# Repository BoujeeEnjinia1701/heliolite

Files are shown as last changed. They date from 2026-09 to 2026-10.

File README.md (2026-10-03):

# HelioLite

     

**Area:** CleanTech · **TRL:** 3 of 9 (proof of concept on paper) · **Value-engineering target:** about $455 USD · **Difficulty:** 3 of 5

Two-axis mini heliostat on a mast that redirects sunlight to a fixed target, using a sun-position algorithm with no sun sensors.

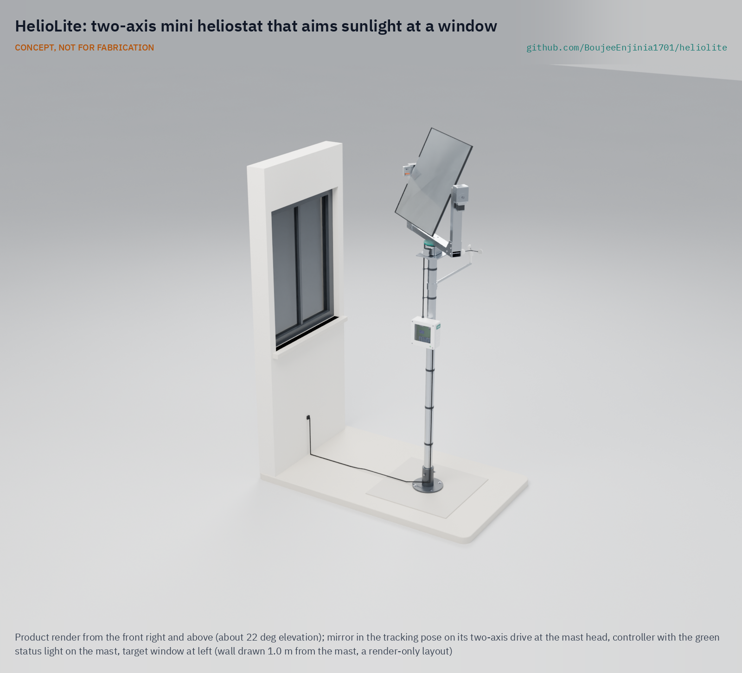
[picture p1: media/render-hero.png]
HelioLite: two-axis mini heliostat that aims sunlight at a window, product render


[Exploded render](media/render-exploded.png) · [Detail render](media/render-detail.png) · [Interactive 3D model](media/viewer.html) · [Concept blueprint (PDF)](media/concept-blueprint.pdf) · [General arrangement HLT-DWG-001 (PDF)](cad/drawings/HLT-DWG-001.pdf) · [Sizing calculations](docs/04-calcs/01-sizing.md) · [Prototype build plan](docs/05-build-plan.md) · [Design decisions register](docs/06-design-decisions.md) · [Review note](docs/REVIEW.md)

## Concept rationale

A flat mirror that follows the sun is the simplest way to move winter sunlight to where it is needed: it adds no light source, burns no fuel and uses a few watts to aim itself. Towns in deep valleys have proved the idea at civic scale ([NPR, 2013](https://www.npr.org/2013/11/03/242789411/as-mirrors-beam-light-to-town-norwegians-share-patch-of-sun)), and open microcontroller projects have shown that a clock and a sun-position algorithm can aim a mirror without a sun sensor ([jremington/Arduino_heliostat](https://github.com/jremington/Arduino_heliostat)). HelioLite joins the two at the scale of one window, with a mast, a light aluminum yoke and two worm drives instead of a structure on a mountainside.

Keeping the design open and garage-buildable matters because the useful sites are scattered and different: each yard, greenhouse or school has its own latitude, distances and shading, and the hourly model shows that siting changes the result more than any part choice. Common parts (a glazier's mirror, steel fence pipe, NEMA17 motors, an ESP32) let owners build, calibrate and repair a unit for their own site, and published calculations let them check that it will work there before they buy anything.

## Burning platform

People in the United States spend, on average, about 90 % of their time indoors ([US EPA](https://www.epa.gov/report-environment/indoor-air-quality)), so the daylight a room receives is most of the daylight its occupants get. Lighting in buildings and outdoor applications used about 8 % of global electricity in 2024, about 2,200 TWh ([IEA](https://www.iea.org/commentaries/the-next-wave-of-led-lighting-smarter-circular-and-more-efficient)), and rooms that never see the sun in winter are the ones that run lamps through the day.

Cold matters as well as dark. The WHO proposes 18 °C as a safe indoor temperature during cold seasons in temperate and colder climates ([WHO Housing and Health Guidelines, 2018](https://www.ncbi.nlm.nih.gov/books/NBK535281/table/fm-ch1.tab1/)), and north-facing rooms receive no passive solar gain toward it. HelioLite's contribution is modest, about 150 W while the sun shines, but it arrives at the time of day and in the rooms where winter sun is otherwise missing.

## Where it could be used

### By industry

| Industry | Use |
| --- | --- |
| Housing and home improvement | Daylight and a little heat in north-facing living rooms, kitchens and home offices |
| Horticulture and community gardens | Extra light on the shaded side of greenhouses, hoop houses and lean-tos in winter and spring |
| Education | A working teaching project in astronomy, optics and control for schools and makerspaces |
| Hospitality and small commercial | Sunlight into a north-facing courtyard, café seating or entrance on clear winter days |
| Urban planning and building retrofit | A small-scale option where new neighboring buildings take a dwelling's winter sun |

### By country or region

| Country or region | Why it matters there |
| --- | --- |
| United States | Space heating and air conditioning made up 52 % of household energy use in 2020, and homes in the colder Northeast and Midwest use more energy on average than those in the South and West, largely for heating ([US EIA](https://www.eia.gov/energyexplained/use-of-energy/homes.php)); houses, greenhouses and community gardens in the northern states have long, low-sun winters |
| European Union | In 2024, 9.2 % of the EU population could not keep their home adequately warm, rising to 19.0 % in Bulgaria and Greece ([Eurostat, 2026](https://ec.europa.eu/eurostat/web/products-eurostat-news/w/ddn-20260202-2)); in sunny southern member states, clear winter days make free solar gain worth capturing |
| China | Planning rules require dwellings to receive two or three hours of sunlight on Dahan Day (20 January) or one hour on the winter solstice, by climate zone and city size ([Hong, Wang and Zhang, *Buildings*, 2024](https://www.mdpi.com/2075-5309/14/4/1090)); units that fall short could borrow sun from a courtyard |
| Mongolia | More than half of Ulaanbaatar's residents, over 790,000 people, live in ger districts heated mainly by coal and wood, and January temperatures fall below -20 °C ([World Bank, 2018](https://www.worldbank.org/en/news/feature/2018/06/26/better-air-quality-in-ulaanbaatar-begins-in-ger-areas)); any daytime solar gain that does not come from a stove is worth having |
| Chile | Firewood produces as much as 94 % of fine particulate (PM2.5) emissions in some Chilean cities, and winter smog is trapped in valley cities such as Santiago ([UNEP](https://www.unep.org/news-and-stories/story/chile-takes-action-air-pollution)); in the Southern Hemisphere the rooms that miss winter sun face south |

## What sparked the idea

The starting point was Rjukan, a Norwegian town of about 3,500 people that the surrounding mountains keep out of direct sunlight from late September to mid-March. In 2013 a set of mirrors on the mountainside above the town was used for the first time: controlled by a computer, the mirrors shift with the sun through the day, pivot closed in windy weather and reflect a beam onto the central square, lighting an elliptical patch of about 600 m² ([NPR, 2013](https://www.npr.org/2013/11/03/242789411/as-mirrors-beam-light-to-town-norwegians-share-patch-of-sun)). HelioLite asks whether the same principle, a tracking mirror aimed by software, can serve a single dark room or greenhouse for a few hundred dollars in parts.

## Problem

North-facing rooms and greenhouses lack daylight and solar heat. On a clear winter day a 0.36 m² mirror can send about 160 W of sunlight (about 15,000 lm) through a window, enough to add roughly 500 lx to a small room, and 0.5 to 1.0 kWh a day at a well-sited house at 45° N, while its heat contribution is a modest bonus (calculations in [HLT-CAL-001](docs/04-calcs/01-sizing.md)).

## Concept

Two-axis mini heliostat on a mast that redirects sunlight to a fixed target, using a sun-position algorithm with no sun sensors.

An ESP32 computes the sun's position from a real-time clock and the site location every 30 s, and two worm-driven steppers turn the mirror so its normal bisects the directions to the sun and to the target. A phone-based calibration at four points over about 4 h fits the mount alignment, and spiral preload springs keep the worm drives' backlash out of the beam. The mirror stows face-down at night, before storms (from a cup anemometer and a wind forecast) and, on a supercapacitor reserve, after a power loss; a spring latch then carries the storm load instead of the gearbox.

At TRL 3 the paper checks meet 11 of 15 requirements with the design made constructable ([HLT-DDR-003](docs/decisions/0003-design-for-construction.md)). Value-engineering target: USD 455. Estimated cost of the constructable design: USD 499 (USD 44 over the target). Daily energy (R3) and pointing (R4) are at risk; see the [review note](docs/REVIEW.md).

Full design precis: [docs/02-concept.md](docs/02-concept.md)

## Key components

- Glass mirror 60 x 60 cm with a black EPDM edge channel (decided 2026-10-02)
- NEMA17 steppers on NMRV030-class 50:1 worm gearboxes (2)
- ESP32 with RTC
- Mast: 60.3 mm galvanized steel pipe (decided 2026-09-25)
- Aluminum tube yoke with printed bearing plugs and bronze bushes (made constructable 2026-10-01)
- Cup anemometer and supercapacitor stow reserve
- Stow stop and spring latch on the yoke (aluminum bracket, decided 2026-10-02), and spiral preload springs on both drives (decided 2026-09-25)

The priced bill of materials (USD 499 against the USD 455 value-engineering target, USD 44 over) is in [bom/bom.csv](bom/bom.csv). The parametric model is `cad/src/model.py`, with STEP and STL exports in `cad/step/` and `cad/stl/`.

## Building the prototype

The [prototype build plan](docs/05-build-plan.md) (HLT-BLD-001) shows how to make each of the 15 made components and how to put HelioLite together in 18 steps, with a making sketch for every made part, close-ups of the joints and a picture for every step, all drawn from the model. Building the plan made the design constructable: the printed yoke became an aluminum tube frame, and the trunnions, latch, mast top and fixings were detailed so every part can be made and fastened ([HLT-DDR-003](docs/decisions/0003-design-for-construction.md)). It is a plan, not yet built; building and testing to it is TRL 4 work. Decisions still open are in the [design decisions register](docs/06-design-decisions.md).

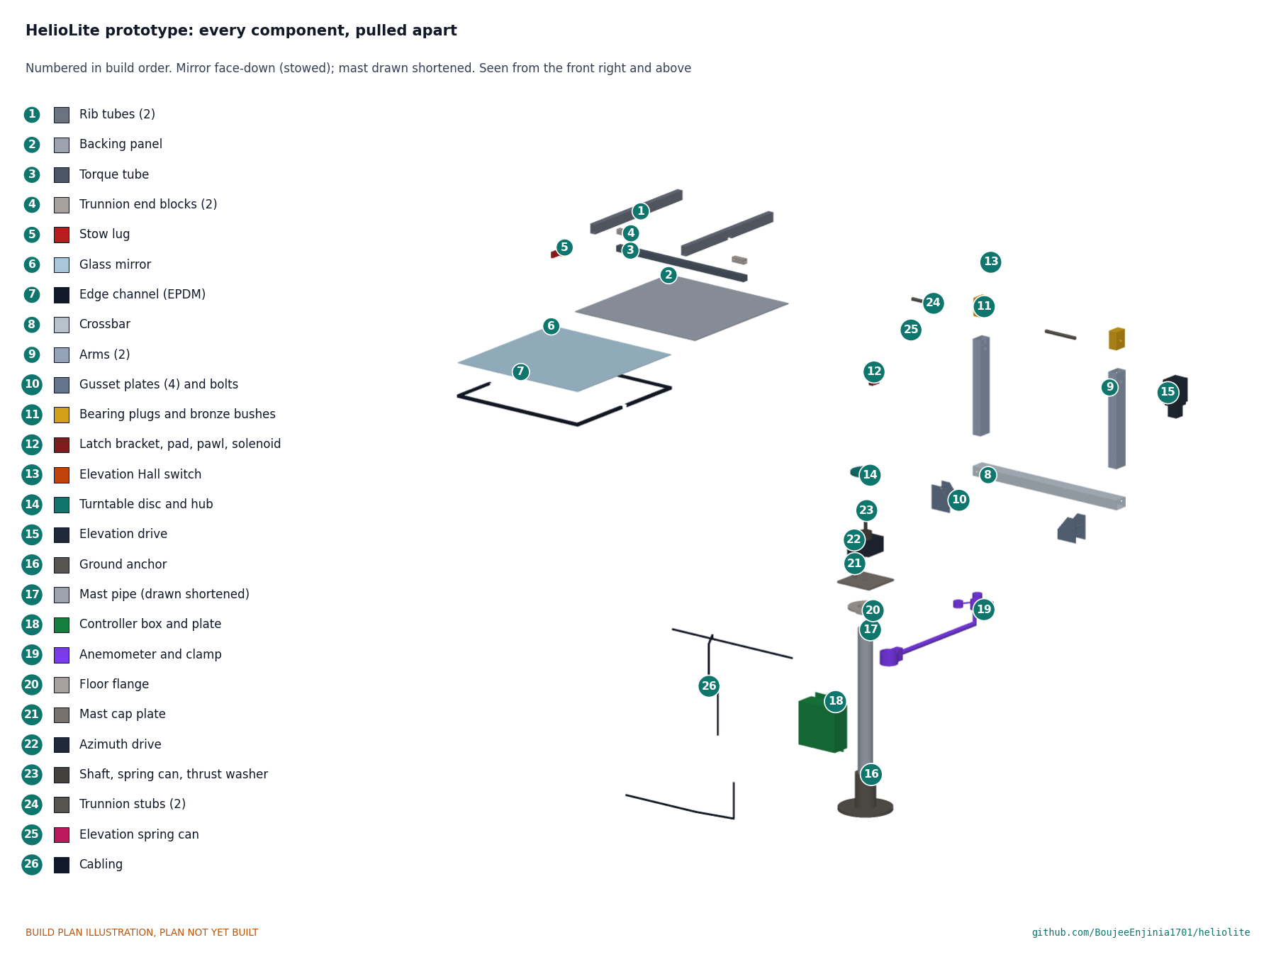
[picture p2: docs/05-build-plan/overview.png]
HelioLite prototype: every component pulled apart, numbered in build order


## Safety

> **Safety:** The reflected beam is nearly as bright as the sun and can cause eye injury; several mirrors aimed at one spot can start a fire. Never aim at people, vehicles or aircraft. The gimbal moves with high torque, the mirror is glass 2.2 m above the ground, and the mast must be anchored and stowed before storms. Only 12 V DC runs outdoors. See the safety section of the [precis](docs/02-concept.md).

## Repository layout

| Folder | Contents |
| --- | --- |
| `docs/` | Problem, concept, requirements, calculations and design decisions |
| `cad/src/` | build123d Python source, the source of truth for all geometry |
| `cad/step/`, `cad/stl/` | Exported models for FreeCAD, other CAD tools and printing |
| `cad/drawings/` | 2D sketches and dimensioned drawings |
| `bom/` | Bill of materials |
| `electronics/` | KiCad schematics and PCB layouts |
| `firmware/` | Microcontroller code |
| `media/` | Renders, perspectives and photos |
| `build-log/` | Dated prototyping notes |

## Documentation

Controlled documents follow the portfolio [documentation standard](.kit/STANDARDS.md). Each carries a document ID (HLT-PRC-001 for the precis), a version and a revision history. Branded PDFs are built with `python .kit/render.py` and attached to GitHub Releases when a document is tagged, for example `HLT-PRC-001/v1.0`.

## Credits

Designed by Amish Chadha, with contributions from Ashok Kumar Chadha. See [CONTRIBUTORS.md](CONTRIBUTORS.md) for roles. To cite this design, use [CITATION.cff](CITATION.cff) (GitHub shows it as "Cite this repository").

AI assistance (Claude) was used to accelerate concept renders, prototype documentation and first-pass sizing calculations. Design direction and all decisions are Amish Chadha's, recorded in this repository's decision records (`docs/decisions/`).

## Licenses

- **Hardware** (CAD, drawings, BOM, electronics): [CERN-OHL-S v2](LICENSE)
- **Software** (firmware, scripts, notebooks): [MIT](LICENSE-SOFTWARE)

A project of the [Design Molecule](https://designmolecule.com) lab.

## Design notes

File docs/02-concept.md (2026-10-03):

---
doc_id: HLT-PRC-001
title: HelioLite design precis
project: HelioLite
doc_type: Design precis
version: "0.8"
status: Draft
date: '2026-10-02'
author: Amish Chadha
license: CERN-OHL-S-2.0
revisions:
- version: "0.1"
  date: '2026-09-24'
  author: Amish Chadha
  change: Initial scaffold
- version: "0.2"
  date: '2026-09-25'
  author: Amish Chadha
  change: Populate to TRL 2 (architecture, first-order numbers, pointing and wind budgets, safety, media)
- version: "0.3"
  date: '2026-09-25'
  author: Amish Chadha
  change: TRL 3 update; design choices decided by Amish (HLT-DDR-001); drives, anemometer and stow reserve added; numbers replaced by HLT-CAL-001; model, drawing HLT-DWG-001 and media refreshed
- version: "0.4"
  date: '2026-09-25'
  author: Amish Chadha
  change: Recommendations accepted by Amish (DDR-002)
- version: "0.5"
  date: '2026-09-26'
  author: Amish Chadha
  change: "Budget top-up approved by Amish: parts within the $455 budget"
- version: "0.6"
  date: '2026-10-01'
  author: Amish Chadha
  change: Design made constructable (HLT-DDR-003); build plan HLT-BLD-001 and register HLT-DEC-001 added; budget treated as a value-engineering target
- version: "0.7"
  date: '2026-10-02'
  author: Amish Chadha
  change: "Decisions of 2026-10-02: glare study and local rules before uncovering, EPDM edge guard, two-lift head fitting from a platform, first site and siting survey, daylight first in public copy"
- version: "0.8"
  date: '2026-10-02'
  author: Amish Chadha
  change: "Decisions of 2026-10-02 carried into the design: aluminum latch bracket, EPDM edge channel in the parts table and figures, two-lift fitting; values from HLT-CAL-001 v0.5"
---

# HelioLite design precis

HelioLite is a 600 x 600 mm glass mirror on a two-axis, worm-driven gimbal at the top of a 60.3 mm steel mast. An ESP32 computes the sun's position from a real-time clock and the site location, and turns the mirror so its normal bisects the directions to the sun and to a fixed target window. It uses no sun sensor; a cup anemometer and a wind forecast tell it when to stow, a supercapacitor reserve lets it stow face-down after a power loss, and a stow latch then carries the storm load instead of the gearbox. The TRL 3 calculations (HLT-CAL-001) give about 211 W at the glazing and 159 W (about 15,000 lm, a mean of about 500 lx in a 12 m² room) at the design point, 0.50 kWh through the glazing on the winter solstice and 1.0 kWh on 1 February at a reference site, and a beam pointing error of 0.30° typical against 0.5°. The design is now constructable (HLT-DDR-003): every part can be made by its stated process and is fixed to the parts next to it, and the [build plan](05-build-plan.md) (HLT-BLD-001) shows how. 11 of 15 requirements are met on paper; daily energy (R3) and pointing (R4) are at risk; and on cost, value-engineering target: USD 455, estimated cost of the constructable design: USD 492 (USD 37 over the target).

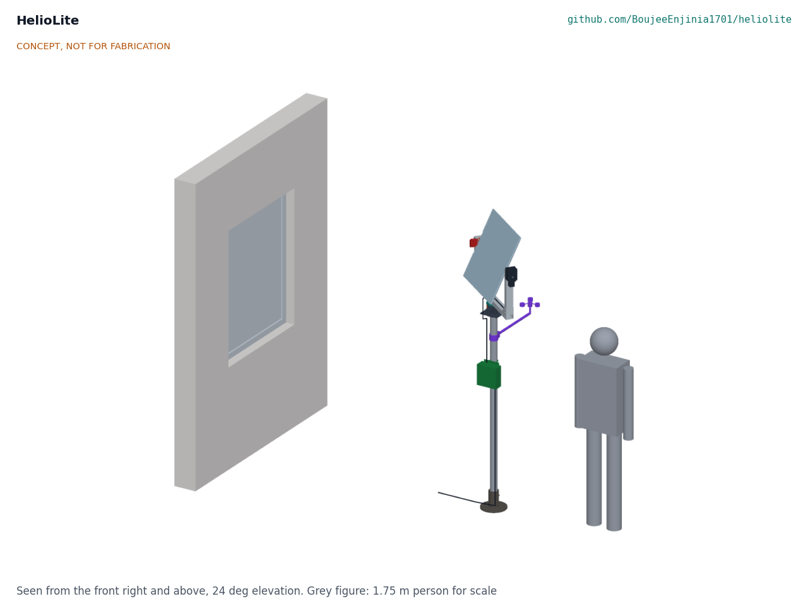
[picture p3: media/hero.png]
Hero render


*Figure 1. HelioLite on its mast with a 1.75 m person for scale. The house wall and target window are context and are drawn closer than a real site so the heliostat stays legible.*

## How it works

1. **Know the time and place.** A DS3231 real-time clock (±2 ppm from 0 to 40 °C, about ±1 min per year ([Adafruit DS3231 guide](https://learn.adafruit.com/adafruit-ds3231-precision-rtc-breakout/overview))) keeps UTC. When Wi-Fi is available the ESP32 corrects it by network time once a week. Latitude, longitude and the target direction are entered once at setup.
2. **Compute the sun.** Every 30 s the ESP32 runs Grena's algorithm 5 (maximum error 0.0027° for 2010 to 2110 ([Grena 2012](https://www.sciencedirect.com/science/article/abs/pii/S0038092X12000400))), with NREL SPA (±0.0003° ([Reda and Andreas](https://www.nrel.gov/docs/fy08osti/34302.pdf))) as the alternative, to get the unit vector **s** toward the sun. There is no sun sensor.
3. **Aim the mirror.** The required mirror normal is **n** = (**s** + **t**) / |**s** + **t**|, where **t** is the unit vector from the mirror to the target. A mount model with five terms (azimuth and elevation zero offsets, two base tilts and the mirror's cant on its torque tube) converts **n** into azimuth and elevation steps.
4. **Move.** Two NEMA17 steppers on NMRV030-class 50:1 worm gearboxes turn the yoke in azimuth and the mirror in elevation. A spiral preload spring of about 3 N·m on each axis keeps the worm teeth on one flank, so the gearbox's 1° backlash does not reach the beam; the elevation spring biases the mirror toward stow. The worms are self-locking, so the drivers switch off between moves. Hall switches home each axis at start-up.
5. **Calibrate.** At setup the user opens a web page served by the ESP32, jogs the sun spot onto the target center at four times spread over about 4 h, and the firmware fits the mount model to those points. No survey instrument is needed.
6. **Stow.** At night, on a fault, when the anemometer sees a 15 m/s gust or when the forecast predicts one, the mirror turns face-down. This sends no reflection anywhere, protects the glass from hail and dust, and presents the lowest wind load. On a power loss a supercapacitor bank in the controller box powers the stow. At the end of the stow a steel lug on the torque tube pushes a sliding latch pawl aside and seats on a polyurethane stop pad on the -X arm; the pawl springs back over it without power, the firmware backs the worm off to mid-backlash, and from then on the stop and the pawl carry the wind moment in both directions. A 12 V pull solenoid draws the pawl back when the unit leaves stow.

The sun moves about 15° per hour, so between 30 s updates it moves about 0.125° and the mirror normal needs about half of that. The mirror's center of mass sits 12.5 mm in front of the elevation axis (HLT-CAL-001, [H4]), so the drives overcome a small gravity moment (up to 0.78 N·m) as well as friction and wind.

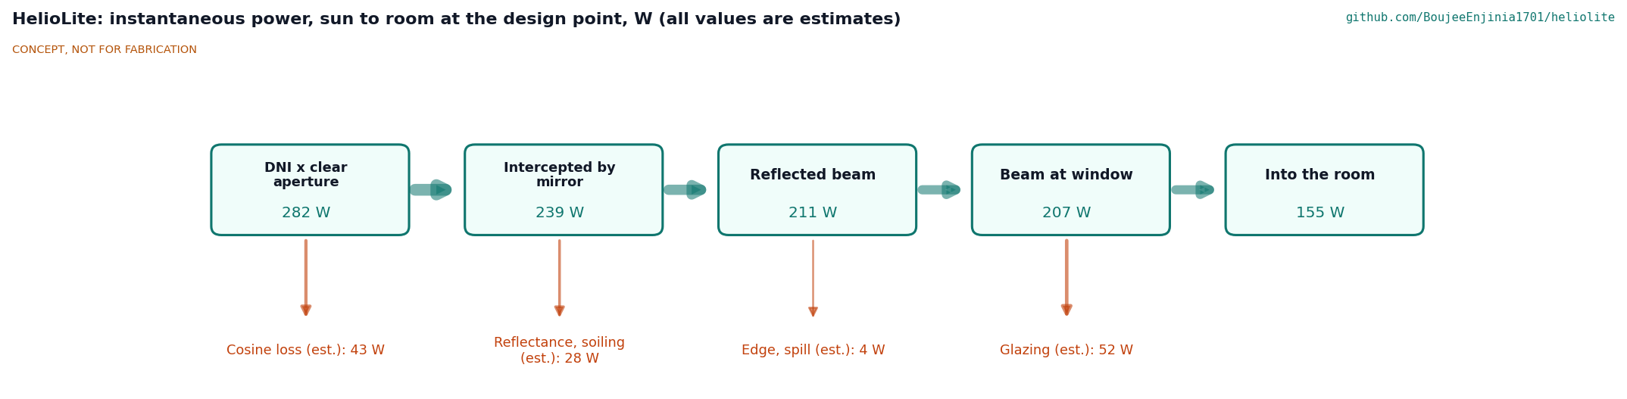
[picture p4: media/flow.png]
Energy flow


*Figure 2. Instantaneous power from the sun to the room at the design point (DNI 800 W/m², 10 m to the target, 32° incidence), in W. Values from HLT-CAL-001 [A2]; all are estimates.*

## Main components

Numbers match the exploded view (Figure 3), drawing HLT-DWG-001 and `bom/bom.csv`.

Table 1. Main components.

| # | Component | Choice | Notes |
| --- | --- | --- | --- |
| 1 | Mirror | 600 x 600 x 3 mm silvered glass, seamed edges, safety backing film; black EPDM edge channel round the glass and panel edges | Decided (HLT-DDR-001, D10; edge channel 2026-10-02); cut by a local glazier |
| 2 | Backing panel and torque tube | 4 mm aluminum composite panel bonded to the mirror, two 25 x 40 mm rib tubes with tunnels for the torque tube, 25 mm square aluminum torque tube with end blocks and pinned 14 mm keyed trunnion stubs | Carries the elevation axis 12.4 mm behind the mirror's center of mass |
| 3 | Gimbal yoke | Aluminum rectangular tube 60 x 40 x 2 mm: a crossbar and two arms at ±340 mm joined by gusset plates, printed ASA bearing plugs and flanged bronze bushes (HLT-DDR-003; the one-piece printed yoke could not be printed) | Arms stand 20 mm outside the mirror's sweep so it can turn face-down; arm flex 0.006° at 8 m/s (HLT-CAL-001, section C) |
| 4 | Elevation drive | NEMA17 stepper on an NMRV030-class 50:1 worm gearbox (17 N·m rated, 14 mm hollow bore) via an adapter plate | Bolted flat to the +X arm, on the keyed trunnion stub |
| 5 | Azimuth drive and mast cap | Same drive, bore vertical, on a 160 mm steel cap plate screwed to a 2 in threaded floor flange on the mast | Carries the turntable |
| 6 | Azimuth turntable | 120 mm aluminum disc on a keyed hub, a double output shaft and a bronze thrust washer | Carries the yoke and mirror |
| 7 | Mast | 60.3 mm (2 in) galvanized steel pipe, 1.70 m | Decided (D1). Mirror center 2.2 m above ground |
| 8 | Ground anchor | Ground screw for 60 mm posts or a concrete footing, with a socket and flange | Must resist 0.79 kN·m; 1.0 kN·m specified |
| 9 | Controller box | ESP32, DS3231 RTC, two TMC2209 drivers, 12 V to 5 V buck, supercapacitor stow reserve (BOM line 15), IP65 box | On the mast at 1.1 m, reachable for service |
| 10 | Homing switches | Two Hall switches with magnets | Axis reference only; not sun sensors |
| 11 | Cabling | Motor leads, 2-core outdoor 12 V cable, cable glands | 12 V feed from indoors (D9) |
| 14 | Anemometer | Pulse-output cup anemometer on a 550 mm side arm at 1.5 m | Decided (D2); a weather sensor, not a sun sensor |
| 16 | Drive preload springs | Flat spiral springs of about 3 N·m in printed cans: elevation on the -X trunnion outboard of the arm, azimuth inside the mast top | Decided (HLT-DDR-002 N2); holds each worm on one flank |
| 17 | Stow stop and latch | 8 mm steel lug on a collar on the torque tube; 6 mm aluminum angle bracket on the -X arm with an aluminum stop block and 3 mm polyurethane (90A) stop pad, a sliding steel pawl and a 12 V pull solenoid with a return spring | Decided (HLT-DDR-002 N1); designed for 48.6 N·m, twice the assumed stowed moment |

A listed indoor 12 V, 3 A power adapter (line 12), the fasteners (line 13) and the stow reserve inside the controller box (line 15) are in the BOM without callouts.

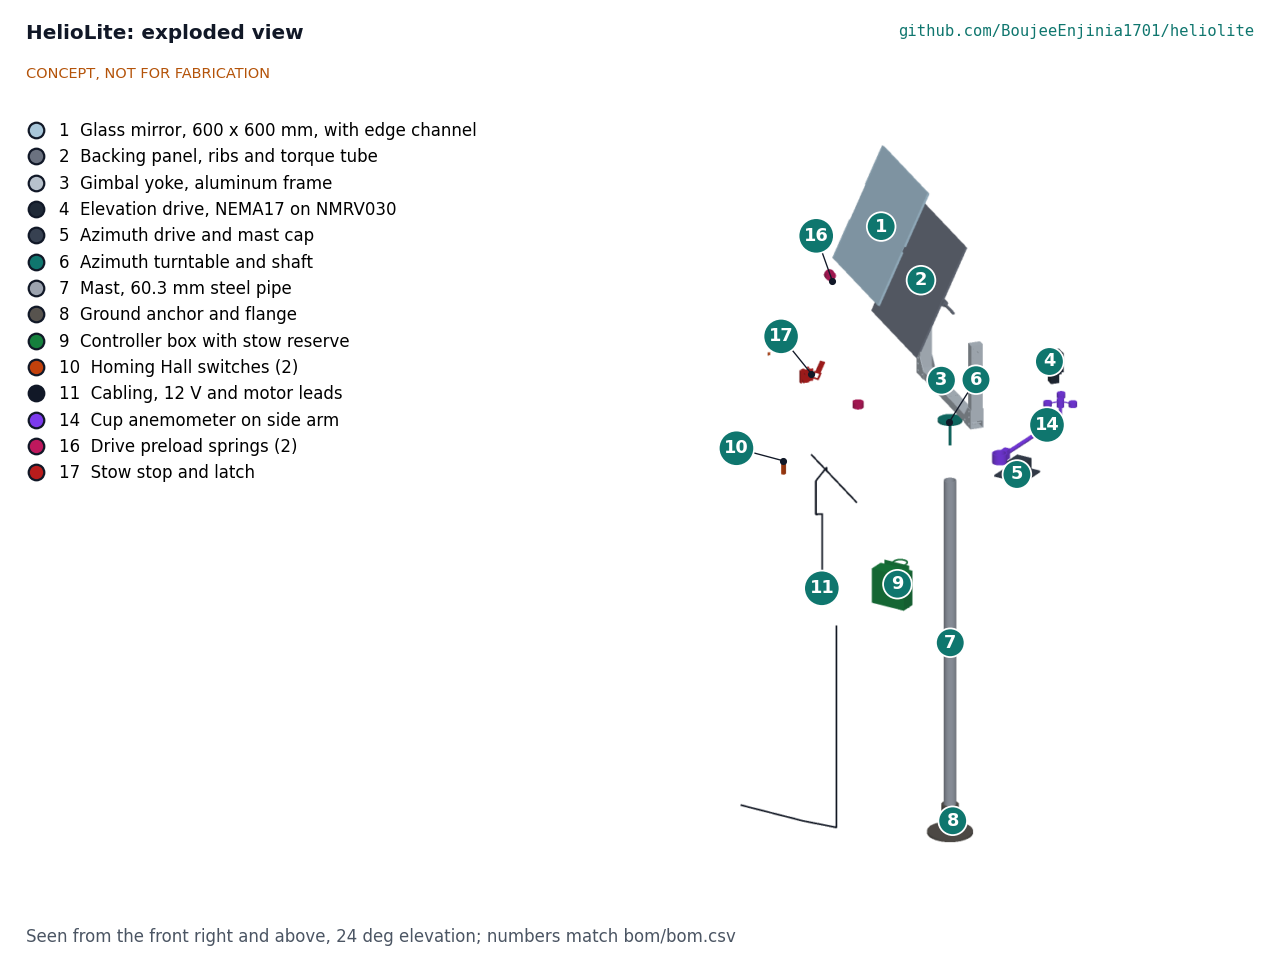
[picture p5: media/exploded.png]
Exploded view


*Figure 3. Exploded view with numbered callouts matching the BOM.*

The general arrangement, with main dimensions and interfaces, is drawing HLT-DWG-001 (`cad/drawings/HLT-DWG-001.pdf`), generated from the parametric model `cad/src/model.py`.

## Performance (HLT-CAL-001)

All values are paper calculations; tags refer to lines printed by `docs/04-calcs/sizing.py`.

### Optical power and daylight

Table 2. Power and daylight at the design point [A2, A3].

| Quantity | Value | Basis | Requirement |
| --- | --- | --- | --- |
| DNI times clear aperture | 282 W | 800 W/m² x 0.353 m² (594 mm square inside the edge channel's lip) | |
| Intercepted (after cosine) | 239 W | x 0.848 | |
| Reflected beam | 211 W | x 0.93 x 0.95 | |
| At the outside of the glazing | 207 W | 0.98 edge and spill allowance | R1 (200 W) met |
| Into the room | 155 W | x 0.75 | |
| Luminous flux into the room | about 14,770 lm | 95 lm/W | About ten 1,500 lm LED lamps |
| Mean added illuminance, 12 m² room | about 490 lx | utilization 0.4 | R2 (300 lx) met |
| Beam irradiance at the target | 0.88 to 0.93 of DNI | A flat mirror does not concentrate | See Safety |

### Daily energy, heat and siting

An hourly clear-sky model at 45° N with the house's shadow and the angle of the beam on the glass gives 0.49 kWh through the glazing on 21 December and 0.98 kWh on 1 February at reference site A (mirror 6 m east and 8 m north of the window). At site B, where the beam meets the glass at 58°, the solstice figure falls to 0.40 kWh; at site C, 15 m out on the window's axis, it rises to 1.0 kWh (HLT-CAL-001, Table 2). R3 (0.5 kWh) is at risk and depends on siting. A small, poorly insulated room may lose 0.5 to 1 kW in cold weather, so about 150 W is a noticeable but modest share of daytime heat, of the order of 15 to 30 % while the sun is out. The main benefit is light. On overcast days HelioLite delivers nothing.

### Beam size and spill

The spot is the mirror's projected outline blurred by the sun's 0.53° diameter. At 10 m it is about 0.65 m square and, with a 0.5° beam error either way, needs 0.82 m of a 1.0 m window. The limit for a 1.0 m wide window is about 17 m; beyond it spill onto the wall rises and a larger target is needed [A5, A6].

### Pointing

Table 3. Pointing error budget for the mirror normal [D4, D5].

| Source | Normal error | Basis |
| --- | --- | --- |
| Sun-position algorithm | 0.001° | Grena algorithm 5 |
| Clock, 6 months without network time | 0.066° | ±2 ppm, 31.5 s |
| Mount model residual after calibration | 0.116° | Median of a simulation with four points over 4 h (the decided default) |
| Worm backlash | 0.050° | With the decided preload springs holding each worm on one flank |
| Step resolution | 0.002° | 1.8° step, 16 microsteps, 50:1 |
| Mast bending at 8 m/s | 0.040° | 60.3 x 3.9 mm pipe |
| Yoke arm flex at 8 m/s | 0.006° | 40 x 60 x 2 mm aluminum tube arms (HLT-DDR-003) |
| **Root sum square** | **0.148°** | **Beam 0.30°; 0.50° at the 95th percentile of calibration** |

R4 is at risk because the 95th percentile of calibration sits at the 0.5° limit. The listed gearbox backlash is 1°, and without the preload springs the beam error could reach about 1°. Calibration points taken within half an hour cannot be fitted; four points over about 4 h are the default (HLT-DDR-002 N6; HLT-CAL-001, Table 3).

### Wind loads and drives

Table 4. Wind loads [E1].

| Wind | Pose | Force on mirror | Hinge moment | Mast base moment | Mast stress |
| --- | --- | --- | --- | --- | --- |
| 8 m/s (operating) | Tracking | 17 N | 2.1 N·m | 41 N·m | 5 MPa |
| 15 m/s (stow trigger) | Tracking | 60 N | 7.4 N·m | 146 N·m | 16 MPa |
| 35 m/s (survival) | Stowed face-down | 162 N | 24.3 N·m | 436 N·m | 48 MPa |
| 35 m/s (failure to stow) | Caught face-on | 324 N | 40.5 N·m | 793 N·m | 87 MPa, below 240 MPa yield |

The mast and anchor carry every case. The gearbox is rated 17 N·m (22 N·m listed maximum), enough up to the 15 m/s stow trigger but not for the assumed stowed moment at 35 m/s. In stow that moment goes into the stow stop and latch, which are designed for 48.6 N·m (a stowed coefficient up to twice the assumed value); the pad deflects 0.28 mm at that load, less than the 0.48 mm of free travel left with the worm at mid-backlash, so the gearbox carries no stowed moment and R9 is met on paper [E7, E8]. Caught face-on (a failed stow), the 40.5 N·m hinge moment still exceeds the gearbox.

### Stow on power loss

A worst-case stow takes 18 s of motion plus 5 s to detect the loss and needs 87 J; five 2.7 V, 25 F supercapacitors in series provide 187 J, a margin of 2.1 [F1, F2]. The stow turns the normal downward, so the beam moves only down toward the ground and disappears once the sun reaches the mirror's back; for about 2.8 s it crosses the ground between the target and the mast [F4], which R10 now allows (HLT-DDR-002 N5). The latch engages without power.

### Power, mass and cost

- **Power:** 0.60 W average, about 14 Wh per day (R14 met) [I1].
- **Mass:** mirror assembly 6.3 kg with its edge channel, yoke 2.3 kg, two drives 3.4 kg, turntable stack 0.5 kg, stow stop and latch 0.33 kg with the aluminum bracket, and springs 0.16 kg make 12.99 kg on the mast top against the relaxed 13 kg limit (R13 met, 0.01 kg margin); the head goes on in two lifts of 4.5 and 6.3 kg; the mast adds 9.2 kg [H1 to H3].
- **Cost:** value-engineering target: USD 455 (a hypothetical control target, Amish 2026-10-01). Estimated cost of the constructable design: USD 499 (USD 44 over the target) [J1]. The cost drivers and savings worth trying are in the design decisions register ([HLT-DEC-001](06-design-decisions.md)).

## Key design choices

Decided by Amish on 2026-09-25, going with the recommendation (HLT-DDR-001):

- **Mast (D1):** 60.3 mm galvanized steel pipe, rather than an 80 x 80 mm extrusion or a guyed 40 x 40 mm extrusion. The pipe tilts 0.040° at 8 m/s; a 40 x 40 mm extrusion would tilt 0.37°.
- **Storm awareness (D2):** a Wi-Fi wind forecast plus a cup anemometer, counted as a weather sensor, not a tracking sensor.
- **Safe state on power loss (D3):** a supercapacitor stow reserve.
- **Budget (D4):** $430, raised to $455 by a top-up Amish approved on 2026-09-26 (HLT-DDR-002, P1).
- **Pitch (D5):** "with no sun sensors".
- **Face-down stow (D6)** at night, on a fault and before storms, rather than face-up (which sends the beam into the sky toward aircraft) or edge-on.
- **Calibration by jogged spot points (D7)**, three or more; four points over about 4 h are used in the budget.
- **Algorithm and time (D8):** Grena algorithm 5 at 30 s, NREL SPA as an alternative, weekly network time.
- **Power supply (D9):** a listed indoor 12 V adapter with only SELV cable outdoors.
- **Mirror (D10):** glass with a safety backing film.

Selected at TRL 3 to make the checks possible: NMRV030-class 50:1 gearboxes, chosen because a rating and backlash are listed at a price within budget, and 40 x 70 mm yoke arms, sized for stiffness (made aluminum tube 40 x 60 mm in HLT-DDR-003, because the printed yoke could not be printed).

Decided by Amish on 2026-09-25, going with the recommendation (HLT-DDR-002):

- **Stowed wind survival (N1):** stow stops on the yoke that carry the stowed hinge moment in both directions (option B), checked against a published-coefficient margin (option C) by designing for twice the assumed coefficient. Because a fixed stop cannot resist both directions on an axis that turns into the stow, the stops take the form of a stop pad and a sprung latch pawl.
- **Drive preload (N2):** a spiral spring of about 3 N·m on each axis, about $6 for both.
- **Mass (N3):** R13 relaxed to 13 kg; installation stays a two-person job.
- **Calibration wording (N4):** R7 counts hands-on time spread over one clear day.
- **Stow transient (N5):** R10 allows the beam to move only downward during a stow.
- **Calibration points (N6):** four points over about 4 h as the default, within D7.

Decided by Amish on 2026-09-26: a budget top-up to $455 that covers the $451 BOM (HLT-DDR-002, P1).

## Safety

> **Safety:** HelioLite redirects sunlight, moves under motor power, carries a glass mirror 2.2 m above the ground and stands in the wind. Treat the beam, the moving gimbal, the glass and the mast as hazards at every stage.

- **Eye injury and glare.** Looking into the reflected beam is like looking at the sun, at 0.88 to 0.93 of its brightness. A brief glance causes an after-image; staring can cause retinal injury ([Ho, Ghanbari and Diver 2011](https://www.sandia.gov/app/uploads/sites/167/2025/03/Methods_Ho_2011.pdf)). Before the mirror is uncovered, check the local building and planning rules and do a simple glare study of where the beam can go (neighbors, roads, sky), and keep the beam inside the property in every state. Site the unit so the beam path crosses no path, road, neighbor's window or flight approach; mount the mirror above head height; never aim at people, vehicles or aircraft; and make the firmware refuse any target that is not the calibrated one.
- **Beam sweep.** During slews, calibration and stows the beam can pass across the surroundings. Stows always turn the normal downward so the beam moves toward the ground; during a power-loss stow it crosses the ground between the target and the mast for about 3 s. Keep that strip clear of seating and paths. Calibration jogs move the spot near the target; the user should stand beside, not in, the beam path.
- **Concentration and fire.** One flat mirror does not concentrate sunlight, but several mirrors aimed at one spot, or a mirror bent concave by its mounting, can. Do not aim more than one unit at the same spot, and check the mirror for flatness after mounting.
- **Glass.** A broken mirror has sharp edges and can fall from 2.2 m. Use seamed edges, a black EPDM edge channel round the glass and panel edges, and a safety backing film, wear cut-resistant gloves and eye protection when handling, and keep the mirror face-down in hail.
- **Moving machinery.** The worm drives turn slowly but with high torque (up to 17 N·m at the output) and can trap fingers between the mirror, torque tube and yoke, where the gaps are only 20 to 56 mm, and between the stow lug and the latch bracket, where the gap is 3 to 9 mm. The preload springs store energy even when the drives are off, and the elevation spring pulls the mirror toward stow if a drive is disconnected. The sliding latch pawl snaps out under spring force. Disable the drives and discharge the stow reserve before servicing, and keep the gimbal above head height.
- **Stored energy.** The supercapacitor bank holds about 360 J at 12 V and can deliver high current if shorted. Fuse its output, bleed it on shutdown and mark the controller box.
- **Mast and wind.** A falling mast or mirror can injure people. Use an anchor rated for at least 1.0 kN·m, check for buried services before driving a ground screw, and stow before storms. The stow latch is designed on an assumed stowed load; until it is tested (TRL 4, on hold), remove the mirror if a storm with gusts above about 29 m/s is forecast. Two people install the mirror: the yoke and drive go on the mast first, and the mirror assembly (about 6.2 kg) is lowered into the yoke, glass covered, from a stable platform, not from steps.
- **Electrical.** Only 12 V DC runs outdoors. The mains adapter stays indoors and must be a listed product; do not run mains to the mast.
- **Working at height.** Rooftop sites need fall protection and a structural check of the roof; they are not recommended for the first build.

## Open questions

Every open decision and every item to confirm when parts are bought is listed in the design decisions register, [docs/06-design-decisions.md](06-design-decisions.md) (HLT-DEC-001). Decided on 2026-10-02: the first site is a house in the team's network, picked by a desk siting survey of 20 to 30 real yards; local rules and a glare study are checked before the mirror is uncovered; public copy leads with daylight and treats heat as a bonus, and both are asked about in co-design. The main open questions: gearbox, spring and solenoid masses (R13 has only 0.06 kg of margin) and the gearbox's backlash; and a published stowed coefficient for small heliostats to confirm the latch margin.

TRL 4 work (building and testing) is on hold by Amish's instruction.

Concept media: [blueprint sheet](../media/concept-blueprint.pdf), [interactive 3D model](../media/viewer.html). General arrangement: [HLT-DWG-001](../cad/drawings/HLT-DWG-001.pdf). Prototype build plan: [HLT-BLD-001](05-build-plan.md).

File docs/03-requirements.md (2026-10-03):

---
doc_id: HLT-REQ-001
title: HelioLite requirements
project: HelioLite
doc_type: Requirements
version: "0.8"
status: Draft
date: '2026-10-02'
author: Amish Chadha
license: CERN-OHL-S-2.0
revisions:
- version: "0.1"
  date: '2026-09-24'
  author: Amish Chadha
  change: Initial scaffold
- version: "0.2"
  date: '2026-09-25'
  author: Amish Chadha
  change: First measurable requirements for TRL 2, with status against the concept estimates
- version: "0.3"
  date: '2026-09-25'
  author: Amish Chadha
  change: R15 budget raised to $430 (HLT-DDR-001 D4); R5 allows the decided anemometer (D2); status column replaced by the TRL 3 results of HLT-CAL-001
- version: "0.4"
  date: '2026-09-25'
  author: Amish Chadha
  change: Recommendations accepted by Amish (DDR-002)
- version: "0.5"
  date: '2026-09-26'
  author: Amish Chadha
  change: Budget top-up approved by Amish
- version: "0.6"
  date: '2026-10-01'
  author: Amish Chadha
  change: Status from HLT-CAL-001 v0.4 for the constructable design (HLT-DDR-003); R15 reported against the value-engineering target
- version: "0.7"
  date: '2026-10-02'
  author: Amish Chadha
  change: "R13 note on the aluminum latch bracket and edge guard decided on 2026-10-02; no target or status changed"
- version: "0.8"
  date: '2026-10-02'
  author: Amish Chadha
  change: "Values from HLT-CAL-001 v0.5 (aluminum latch bracket, EPDM edge channel, two-lift fitting, BOM lines 1, 9 and 17); no target or status changed"
---

# HelioLite requirements

These are the requirements for the concept, checked by calculation at TRL 3 in HLT-CAL-001 v0.5, for the constructable design of HLT-DDR-003 with the decisions of 2026-10-02 carried in. Targets are proposals, not yet validated with users. "Met" means met on paper only. On 2026-09-25 Amish decided to raise the budget to $430 (HLT-DDR-001, D4), so R15 reads $430, and R5 names the weather anemometer decided in D2 as allowed. Later the same day he accepted the TRL 3 recommendations (HLT-DDR-002): R13 is relaxed from 10 kg to 13 kg (N3), R7 now counts hands-on time spread over one clear day (N4), and R10 now allows the beam to move only downward during a stow (N5). On 2026-09-26 Amish approved a budget top-up to $455 (HLT-DDR-002 v0.2, P1), so R15 read $455. On 2026-10-01 Amish set budgets as hypothetical value-engineering targets ("the budgets are a hypothethical control target to ensure we are thinking along a value engineering lens"), so R15 now names the $455 value-engineering target and its status is reported against it. No other target has changed.

The **design point** used throughout is a clear winter day at 45° N, DNI 800 W/m², a mirror-to-target distance of 10 m and an angle of incidence on the mirror of about 32° (cosine factor 0.85).

Table 1. Requirements and TRL 3 status (tags refer to lines printed by `docs/04-calcs/sizing.py`).

| ID | Requirement | Target | Status (HLT-CAL-001) | Verification |
| --- | --- | --- | --- | --- |
| R1 | Redirected sunlight at the target | 200 W or more arriving at the outside of the target glazing at the design point | Met: 207 W [A2] | Optical calculation (done) |
| R2 | Useful daylight in the room | Raise the mean illuminance of a 12 m² room by 300 lx or more at the design point | Met: 492 lx, utilization 0.4 assumed [A3] | Illuminance calculation (done) |
| R3 | Daily energy delivered | 0.5 kWh or more through the glazing on a clear winter day | **At risk:** 0.49 kWh on 21 Dec and 0.98 kWh on 1 Feb at reference site A; 0.40 kWh at site B on 21 Dec [B2, B3] | Hourly sun-path calculation (done); siting survey |
| R4 | Pointing accuracy | Beam center within 0.5° of the target center (about 90 mm at 10 m), with winds up to 8 m/s | **At risk:** 0.30° typical and 0.50° at the 95th percentile, with four-point calibration and the decided preload springs; 1.04° without preload [D5, D6] | Error budget and calibration simulation (done); later spot log |
| R5 | Sensorless tracking | Sun position from time and location only; no sun sensor or camera; axis homing switches and a weather anemometer allowed | Met by design | Design review |
| R6 | Timekeeping | Clock error 60 s or less after 6 months without a network time source | Met: 31.5 s (DS3231, ±2 ppm) [D1] | Datasheet check |
| R7 | Calibration | One person sets up and calibrates from a phone in 30 min or less of hands-on time, spread over one clear day, with no survey instrument (reworded 2026-09-25, HLT-DDR-002 N4) | Met: 19 min hands-on for four points over about 4 h [G1, G2] | Task analysis (done) |
| R8 | Working range | Target distance 3 to 20 m; mirror normal azimuth ±135° about the target direction; elevation of the normal -90° (face-down stow) to +90° | Met mechanically; spot plus 0.5° error fits a 1.0 m window up to 16.8 m [A6, K1] | Geometry check (done) |
| R9 | Wind | Hold R4 up to 8 m/s; survive 35 m/s (126 km/h) gusts in stow without damage | Met: the stowed moment (24.3 N·m, assumed coefficient) is carried by the stow stop and latch, designed for 48.6 N·m, not by the gearbox [E7, E8] | Wind load calculation (done); gearbox and pad data |
| R10 | Safe beam when stowed, faulted or unpowered | Beam directed only at the target or the ground within 3 m of the mast when stowed; during a stow the beam may move only downward, toward the ground (clarified 2026-09-25, HLT-DDR-002 N5); stow face-down within 60 s of a fault or power loss | Met: stow in 23 s on the supercapacitor reserve with 2.1x energy margin, beam moving only downward; latch engages without power [F1, F2, F4] | Calculation (done); later fault test |
| R11 | Electrical safety | Only 12 V DC (SELV) outdoors; electronics enclosure IP65; mains adapter indoors and listed | Met by design | Design review |
| R12 | Outdoor life | Operate from -20 to +45 °C; UV-stable plastics (ASA or better); corrosion-resistant mast; 10-year mirror life with cleaning | Not verifiable at TRL 3 | Materials review; later exposure test |
| R13 | Mass and install | 13 kg or less on the mast top (relaxed from 10 kg, decided by Amish 2026-09-25, HLT-DDR-002 N3); installed by two people with hand tools in 4 h or less | Met, very thinly: 12.99 kg on the mast top, 0.01 kg margin on assumed masses, with the aluminum latch bracket (0.08 kg less) and the EPDM edge channel (0.16 kg) decided on 2026-10-02; fitted in two lifts of 4.48 kg and 6.34 kg [H3]; install time not verifiable at TRL 3. If the weighed head exceeds 13 kg, R13 is relaxed slightly rather than the guard dropped (decided 2026-10-02) | Mass estimate (done) |
| R14 | Standby power | 3 W or less average from the 12 V supply | Met: 0.60 W [I1] | Power budget (done) |
| R15 | Cost | Parts at or under the $455 value-engineering target (a hypothetical control target; raised from $400 to $430 by Amish on 2026-09-25, then to $455 by a top-up he approved on 2026-09-26) | **Over the value-engineering target by $44:** estimated cost of the constructable design $499 [J1] | Priced BOM (`bom/bom.csv`) |

## Requirements not met, at risk or over the target

- **R15 (cost) over the value-engineering target by $44.** The parts that make the design constructable (HLT-DDR-003) take the estimate from $451 to $492, and the edge channel and aluminum latch bracket decided on 2026-10-02 to $499; the target is unchanged, and the design decisions register lists the cost drivers and savings worth trying.

- **R3 (daily energy) at risk.** Site dependent: site A now falls 2 % short on the solstice (0.49 kWh, after the edge channel's 3 mm front lip trimmed the clear aperture) and meets the target by February; missed at site B.
- **R4 (pointing) at risk.** 0.30° typical, but the 95th percentile of four-point calibration sits at the 0.5° limit; it relies on the decided preload springs against the gearbox's 1° backlash.
- **R12 (outdoor life) not verifiable at TRL 3.**
- **R13 (mass)** is met with only 0.01 kg of margin on assumed gearbox, spring and solenoid masses.

## Assumptions

- Mirror area 0.36 m² (600 x 600 mm), clear aperture 0.353 m² inside the edge channel's 3 mm front lip, solar-weighted reflectance about 0.93 when clean and 0.95 soiling factor (combined 0.88).
- Double glazing transmits about 75 % of the beam at normal incidence, less at oblique incidence (HLT-CAL-001).
- Luminous efficacy of direct sunlight about 95 lm/W; a utilization factor of 0.4 for sunlight bounced from a light ceiling or a diffuser into a 3 x 4 m room.
- R3 is checked by an hourly clear-sky model at three illustrative sites at 45° N (HLT-CAL-001, section B). The TRL 2 shortcut of six useful hours at a mean DNI of 650 W/m² and a mean cosine factor of 0.80 gives 0.73 kWh and is no longer used.

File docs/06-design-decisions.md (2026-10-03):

---
doc_id: HLT-DEC-001
title: HelioLite design decisions register
project: HelioLite
doc_type: Design decisions register
version: "0.4"
status: Draft
date: '2026-10-02'
author: Amish Chadha
license: CERN-OHL-S-2.0
revisions:
- version: "0.1"
  date: '2026-10-01'
  author: Amish Chadha
  change: Register opened with the constructable design (HLT-DDR-003); budget treated as a value-engineering target
- version: "0.2"
  date: '2026-10-02'
  author: Amish Chadha
  change: "Amish approved the recommendations for all open decisions 1 to 11 on 2026-10-02 (aluminum latch bracket, two-lift head fitting, edge guard, clear lid, glare check before uncovering); moved to decisions made; value engineering savings updated"
- version: "0.3"
  date: '2026-10-02'
  author: Amish Chadha
  change: "Design for construction (HLT-DDR-003, Table 1, P1 to P14) accepted by Amish on 2026-10-02; added to decisions made"
- version: "0.4"
  date: '2026-10-02'
  author: Amish Chadha
  change: "Decisions of 2026-10-02 carried into the model, BOM and calculations: value engineering at USD 499; R13 margin now 0.01 kg"
---

# HelioLite design decisions register

Every design decision still to be made, and every decision made, in one place. Each decision is argued in full in its decision record under `docs/decisions/`; this register is the index Amish works from. The build plan (`docs/05-build-plan.md`) describes the design as it stands and does not list open decisions.

## Open decisions

None. All open decisions were decided on 2026-10-02.

## To confirm when parts are bought

| # | What to confirm | Why it matters | Source |
| --- | --- | --- | --- |
| 1 | The NMRV030 gearbox's output-face hole pattern (the model assumes four M6 on a 44 mm square), its mass (1.2 kg assumed) and its listed backlash | Sets the holes in the right arm and cap plate; R13 has a 0.01 kg margin with the aluminum latch bracket and the edge channel decided on 2026-10-02; R4 depends on backlash | HLT-DDR-003; HLT-CAL-001 |
| 2 | A 14 mm double output shaft is sold for the chosen azimuth gearbox, and the gearbox's permissible radial load and overturning moment on its output | The yoke's wind moment passes through the azimuth gearbox's output bearings | HLT-DDR-003 |
| 3 | The floor flange's hole circle (105 mm assumed) and that the pipe thread engages fully | Sets the tapped holes in the cap plate | HLT-DDR-003 |
| 4 | The keyed flange hub fits the 14 mm keyed shaft, has a 30 mm boss and a 40 mm screw circle | Sets the turntable disc's holes | HLT-DDR-003 |
| 5 | The release solenoid's stroke (12 mm needed), pull force with its return spring, and mass | The pawl must clear the lug fully | HLT-DDR-003 |
| 6 | The spiral springs give about 3 N·m over the axis travel and fit the 50 mm and 52.5 mm cans | The preload that R4 depends on | HLT-DDR-002, N2 |
| 7 | The ground screw socket fits 60.3 mm pipe and its overturning rating is at least 1.0 kN·m | Mast survival at 35 m/s | HLT-CAL-001 [E4] |
| 8 | A published stowed force and hinge moment coefficient for small heliostats | The latch is designed on an assumed coefficient with a factor of 2 | HLT-CAL-001 [E7] |
| 9 | The polyurethane pad's modulus (50 MPa assumed) | The pad must deflect less than the worm's free travel | HLT-CAL-001 [E8] |
| 10 | The controller box's mounting lugs | Sets the plate's box holes | HLT-DDR-003 |

## Value engineering

Value-engineering target: USD 455 (a hypothetical control target, not a limit). Estimated cost of the constructable design: USD 499 (USD 44 over the target). Main cost drivers and savings worth trying:

- The largest lines are the two drives (azimuth with cap and flange USD 68, elevation USD 52), the controller with its mounting plate (USD 51), the gimbal yoke (USD 38), the backing panel, ribs, tube and trunnions (USD 36), the mast and the ground anchor (USD 35 each), the glass mirror with its edge channel (USD 31), and the turntable stack (USD 28).
- Making the design constructable repriced lines 2, 3, 5, 6, 9, 13, 14 and 17, from USD 451 to USD 492: the floor flange and tapped cap (USD 8), the shaft, hub and thrust washer (USD 13), the controller plate and U-bolts (USD 6), the anemometer clamp (USD 4), more fixings (USD 4), the rib, end block and stub parts (USD 6) and the latch detail (USD 2), partly offset by the aluminum yoke costing less than the printed one (USD 2 less). The decisions of 2026-10-02 add USD 7, to USD 499: the EPDM edge channel (line 1, about USD 6) and the aluminum latch bracket (line 17, about USD 1); the clear-lid box (line 9) lists at about the same price.
- Savings worth trying: buy both gearboxes and motors as one kit (often USD 10 to 15 less than two singles); print the turntable disc in ASA instead of aluminum if a stiffness check allows (about USD 6); a forecast-only storm stow where the forecast is reliable, making the anemometer optional (USD 24, but it weakens R9's backup). The cheaper box without a clear lid is no longer a saving: the clear lid was decided on 2026-10-02.

## Decisions made

| Date | Decision | Decided by | Record |
| --- | --- | --- | --- |
| 2026-09-25 | TRL 2 review items D1 to D10: 60.3 mm galvanized steel pipe mast; forecast plus cup anemometer; supercapacitor stow reserve; budget $430; pitch "with no sun sensors"; face-down stow; calibration by jogged spot points; Grena algorithm 5 with weekly network time; listed indoor 12 V adapter; glass mirror with safety backing film | Amish: "proceed with all of your recommendations across all batches. Make sure we don't proceed to TRL 4 on any of them." | HLT-DDR-001 |
| 2026-09-25 | TRL 3 review items N1 to N6: stow stop and latch carrying the stowed moment; spiral preload springs on both axes; R13 relaxed to 13 kg; R7 and R10 reworded; four calibration points over about 4 h | Amish: "i accept all your recommendations, go with them across all repos." | HLT-DDR-002 |
| 2026-09-26 | Budget top-up to $455 for the $451 BOM (P1, option a) | Amish: "I am ok with the budget top ups" | HLT-DDR-002 v0.2 |
| 2026-09-30 | Make the design physically buildable while drawing the build plan | Amish: "If you are realising that the design cannot be built as per concept - fix the design assumptions to match and be physically feasible as you draw the illustrations." | HLT-DDR-003 (its Table 1 changes and its Table 3 items were decided on 2026-10-02, below) |
| 2026-10-01 | `budget_usd` is a hypothetical value-engineering target, not a limit | Amish: "the budgets are a hypothethical control target to ensure we are thinking along a value engineering lens. its ok to ensure wording reflects that the hypothesis budget was x - the real cost being accrued is y" | This register, Value engineering |
| 2026-10-02 | First site and user: a house first, owned by a contributor or someone in the team's network, chosen by the siting check of decision 3 (one mirror spot sees both the winter sun and a north window); schools only after glare safety is shown | Amish: "i approve your recommendations for all 555 open decisions." | HLT-DDR-001, O1 |
| 2026-10-02 | Local rules and glare: before the mirror is uncovered, check the local building and planning rules and do a simple glare study of where the beam can go (neighbours, roads, sky); the beam stays inside the property in every state | Amish: "i approve your recommendations for all 555 open decisions." | HLT-DDR-001, O2 |
| 2026-10-02 | Siting survey: a desk survey of 20 to 30 real yards using satellite images and a sun-path check, scored on whether one mirror spot sees the winter sun and a north window within range, then a visit to the first build site | Amish: "i approve your recommendations for all 555 open decisions." | HLT-DDR-001, O3 |
| 2026-10-02 | Benefit: public copy leads with daylight and treats heat as a bonus until co-design shows otherwise; both questions are asked at the co-design sessions | Amish: "i approve your recommendations for all 555 open decisions." | HLT-PRC-001, open questions |
| 2026-10-02 | R13 mass margin (option b, changed from a): the latch bracket is made in aluminum now (about 0.1 kg saved), and the parts are weighed at TRL 4 | Amish: "i approve your recommendations for all 555 open decisions." | HLT-DDR-003, A1 |
| 2026-10-02 | Head on the mast (option b, changed from a): for the prototype the yoke and drive are fitted at height first and the mirror assembly (about 6.2 kg) is lowered into it, glass covered, from a stable platform rather than steps; a hinged mast base (option c) is looked at before any second build | Amish: "i approve your recommendations for all 555 open decisions." | HLT-DDR-003, A2 |
| 2026-10-02 | Appearance model and renders: updated to the aluminum yoke, the new latch and the rib tunnels, dropping the torque tube saddles | Amish: "i approve your recommendations for all 555 open decisions." | HLT-DDR-003, A3; `docs/REVIEW.md`, 2026-09-26, item 4 |
| 2026-10-02 | Target distance in the product render: the wall stays 1.0 m from the mast as a render-only layout, with the caption saying so | Amish: "i approve your recommendations for all 555 open decisions." | `docs/REVIEW.md`, 2026-09-26, item 1 |
| 2026-10-02 | Mirror edge guard: a black EPDM edge channel round the glass and panel edges is added to the BOM, paired with the aluminum latch bracket of decision 5; if the weighed head still exceeds 13 kg, R13 is relaxed slightly rather than the guard dropped | Amish: "i approve your recommendations for all 555 open decisions." | `docs/REVIEW.md`, 2026-09-26, item 2 |
| 2026-10-02 | Controller lid: an IP65 box with a clear lid is specified on BOM line 9 | Amish: "i approve your recommendations for all 555 open decisions." | `docs/REVIEW.md`, 2026-09-26, item 3 |
| 2026-10-02 | Product finish set (option a), with the yoke in natural aluminum: teal turntable and name plate, silver-grey gearboxes, black motors, galvanized mast and cap, dark anchor | Amish: "i approve your recommendations for all 555 open decisions." | `docs/REVIEW.md`, 2026-09-26, item 5 |
| 2026-10-02 | Design for construction accepted: the changes P1 to P14 in Table 1, as made | Amish: "APPROVED: Design-for-construction changes in 10 repos (CityTwin, CoolShade, PalletPilot, Heliolite, PotholeLog, EarthPress, ReadyKit, CellCheck, CargoMule and ThermaCart)" | [HLT-DDR-003](decisions/0003-design-for-construction.md), Table 1 |

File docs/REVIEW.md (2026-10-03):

# Review note: HelioLite

## Session 2026-09-25: /populate to a strong TRL 2

### What was done

- `docs/01-problem.md` (HLT-PRB-001 v0.2): problem with winter sun geometry, users, operating environment and siting, constraints, out of scope, prior work with cited sources (Rjukan sun mirrors, Sunflower home heliostat, open Arduino heliostats, NREL SPA, Grena 2012, Sandia wind-load and glare methods), open questions and a co-design checklist.
- `docs/03-requirements.md` (HLT-REQ-001 v0.2): 15 measurable requirements (R1 to R15) with targets, a defined design point, a status column against the estimates, and a list of requirements not met.
- `docs/02-concept.md` (HLT-PRC-001 v0.2): how it works, numbered components, optical power and daylight, daily energy and heat, beam size, pointing error budget, wind loads, power, mass, cost, proposed design choices, safety section and open questions.
- `cad/src/concept_media.py`: massing model with 11 BOM-numbered parts (mirror, backing and torque tube, printed yoke, two worm drives, turntable, mast, anchor, controller box, homing switches, cabling), plus a house wall and window as hero-only context.
- `media/`: `hero.png` (1.75 m scale figure), `concept-blueprint.png`, `.pdf` and `.svg`, `exploded.png` with callouts 1 to 11, `flow.png` (sun to room, all values labeled as estimates), `model.glb` and `viewer.html`. No cutaway: the inside of the gimbal does not carry the idea at massing level. Temporary `media/_views*` folders deleted.
- `bom/bom.csv`: 13 lines with indicative prices, items 1 to 11 matching the exploded view; `bom/bom-notes.md` updated.
- `README.md`: hero image and links line inserted before "## Problem"; problem, concept, key components and safety text brought in line with the precis.
- `docs/pdf/`: branded PDFs of the three controlled documents.
- `project.yaml`: unchanged.

### Key results (estimates, to be checked at TRL 3)

| Quantity | Estimate | Requirement |
| --- | --- | --- |
| Beam at the outside of the glazing, design point (DNI 800 W/m², 10 m) | about 212 W | R1 (200 W) met, small margin |
| Sunlight into the room | about 159 W, about 15,000 lm | |
| Mean added illuminance, 12 m² room | about 500 lx | R2 (300 lx) met |
| Energy through the glazing, clear winter day | about 0.7 kWh | R3 (0.5 kWh) met |
| Share of a small room's daytime heat loss | about 10 to 30 % while sunny | Heat benefit is modest |
| Pointing error, root sum square | about 0.17° normal, 0.34° beam | R4 (0.5°) met on paper |
| Clock error, 6 months without network | about 32 s | R6 (60 s) met |
| Hinge moment, 35 m/s face-on | about 40 N·m | R9 at risk (gearbox holding torque unknown) |
| Mast stress, 35 m/s | about 78 MPa in 60.3 mm steel pipe | Mast OK |
| Mass on the mast top | about 8 kg | R13 (10 kg) met |
| Average power | about 0.6 W | R14 (3 W) met |
| Parts cost | about $391 | R15 ($400) met, about $9 margin |

Requirements not met or at risk:

- **R9 (wind survival) not met.** The unit has no way to know a storm is coming, and a generic NEMA17 worm gearbox may not hold the estimated 40 N·m hinge moment if caught face-on.
- **R10 (safe state on power loss) not met.** Worm drives hold the mirror where it stops, so after a power loss the beam walks across the surroundings at about 15° per hour.
- **R7 (30 min calibration) and R12 (outdoor life)** are unverified.
- **R15 (cost)** has only about $9 of margin; either fix for R9 or R10 takes the total over budget.

### Proposed, awaiting Amish

1. **Mast.** The scaffold's aluminum extrusion mast is too flexible: a 40 x 40 mm profile at 2.2 m tilts about 0.37° at 8 m/s, more than the whole pointing budget. Options: (A) 60.3 mm galvanized steel pipe, about $35; (B) 80 x 80 mm aluminum extrusion, about $70 to $90, over budget; (C) 40 x 40 mm extrusion with guy wires. Recommendation: A. This changes a key component listed in the README, where it is marked as proposed. **Decided by Amish, 2026-09-25: go with recommendation** (HLT-DDR-001 D1).
2. **Storm awareness (R9).** Options: (A) Wi-Fi wind forecast; (B) cup anemometer, about $20; (C) slip clutch. Recommendation: A plus B, with the anemometer treated as a weather sensor, not a tracking sensor. **Decided by Amish, 2026-09-25: go with recommendation** (HLT-DDR-001 D2).
3. **Safe state on power loss (R10).** Options: (A) supercapacitor stow reserve, about $10 to $15; (B) supervised sites only. Recommendation: A. **Decided by Amish, 2026-09-25: go with recommendation** (HLT-DDR-001 D3).
4. **Budget.** With the recommendations for items 2 and 3 the parts total becomes about $425 against $400. Options: (a) raise `budget_usd` to $430; (b) keep $400 and drop to a cheaper gearbox or print the turntable; (c) treat the anemometer as optional where a forecast is available. Recommendation: (a), because the fixes are safety items. `project.yaml` is unchanged. **Decided by Amish, 2026-09-25: go with recommendation** (HLT-DDR-001 D4).
5. **Pitch wording.** The pitch says "with no sensors", but the design uses two axis homing switches and may add an anemometer. Recommendation: change to "with no sun sensors". `project.yaml` is unchanged. **Decided by Amish, 2026-09-25: go with recommendation** (HLT-DDR-001 D5).
6. Face-down stow at night, on faults and before storms, rather than face-up or edge-on. **Decided by Amish, 2026-09-25: go with recommendation** (HLT-DDR-001 D6).
7. Calibration by jogging the sun spot onto the target at three or more times of day, rather than a compass, inclinometer or GPS survey. **Decided by Amish, 2026-09-25: go with recommendation** (HLT-DDR-001 D7).
8. Grena algorithm 5 at 30 s updates (NREL SPA as an alternative), with weekly network time when Wi-Fi is available. **Decided by Amish, 2026-09-25: go with recommendation** (HLT-DDR-001 D8).
9. Indoor listed 12 V adapter with only SELV outdoors, rather than a solar panel and battery on the mast. **Decided by Amish, 2026-09-25: go with recommendation** (HLT-DDR-001 D9).
10. Glass mirror with safety backing film, rather than acrylic or film mirror. **Decided by Amish, 2026-09-25: go with recommendation** (HLT-DDR-001 D10).
11. First site and user for the co-design checklist (house, greenhouse or school). No recommendation; stays Proposed, awaiting Amish.

### Safety concerns

- Eye injury and glare from a beam of 0.6 to 0.9 sun; beam sweep during slews and after power loss (R10).
- Fire only if several mirrors are aimed at one spot or the mirror is bent concave; single-unit, flat-mirror design.
- Broken glass falling from 2 m; pinch points in a high-torque worm-driven gimbal.
- Mast or mirror failure in storms (R9); buried services when driving a ground screw; working at height on roofs.
- Mains stays indoors in a listed adapter; only 12 V DC outdoors.

### Problems and notes

- The hero and blueprint show the house wall about 2.2 m from the mast so the heliostat stays legible; the design range is 3 to 20 m. The precis caption says so.
- Some sources (Grena 2012 abstract, EN 17037 summary) were checked through secondary pages; the full texts should be read at TRL 3.
- The legacy `cad/src/model.py` placeholder is untouched (TRL 3 work).

### Recommended next step

Review this note and the media, then decide items 1 to 4. If approved, run `/advance-trl3` to check the optical, pointing and wind estimates by calculation, select gearboxes with a known holding torque, and produce the parametric model and drawing sheet.

## Session 2026-09-25: TRL 3

Amish's instruction for this session (2026-09-25): "proceed with all of your recommendations across all batches. Make sure we don't proceed to TRL 4 on any of them." HelioLite now claims TRL 3 (proof of concept on paper). TRL 4 is on hold by Amish's instruction.

### What was done

- `docs/decisions/0001-trl2-review-decisions.md` (HLT-DDR-001 v0.1): the ten TRL 2 review items with a recommendation recorded as decided by Amish, 2026-09-25, and four items that stay open.
- `docs/04-calcs/01-sizing.md` (HLT-CAL-001 v0.1) and `docs/04-calcs/sizing.py`: design-point optics and spot size; an hourly clear-sky model with house shading and glazing incidence at three illustrative sites; mast and yoke stiffness; a Monte Carlo simulation of the jogged-point calibration; the pointing budget; wind loads in operation, at the stow trigger, stowed and caught face-on, against the gearbox rating; the supercapacitor stow reserve and the beam path during a stow; mass and balance from the model; power; BOM total. The script imports the model's `PARAMS`, reads `bom/bom.csv`, and prints every quoted number with a tag, [A1] to [K3].
- `cad/src/model.py`: parametric build123d model (mirror, backing and torque tube with trunnions, printed yoke, two NMRV030-class drive envelopes, mast cap, turntable, mast pipe, ground anchor and screw, controller box, Hall switches, cabling, anemometer) in tracking or stowed pose, exporting `cad/step/heliolite-tracking.step`, `heliolite-stowed.step`, `mirror-assembly.step`, `gimbal.step`, `mast-and-anchor.step` and matching STL files in `cad/stl/`.
- `cad/src/sheets.py` and `cad/drawings/HLT-DWG-001.svg`, `.pdf`, `.png`: general arrangement at Rev P1, scale 1:25, stowed orthographic views with dimensions drawn from the model, tracking-pose isometric, and a main-dimensions box. The sheet carries "CONCEPT, NOT FOR FABRICATION" and "PRELIMINARY, NOT FOR FABRICATION". HLT-DWG-001 was free; the concept sheet is HLT-DWG-010.
- `bom/bom.csv` and `bom/bom-notes.md`: all 15 lines priced with a supplier or supplier type; total $425 against the $430 budget.
- `cad/src/concept_media.py` now builds the media from `model.py`; every file in `media/` was regenerated and checked by eye; temporary `media/_views*` folders were deleted.
- HLT-PRB-001, HLT-PRC-001 and HLT-REQ-001 revised to v0.3 (decisions recorded, numbers replaced by HLT-CAL-001, TRL 3 status column); `README.md` updated to TRL 3 with the new pitch; `project.yaml` set to `trl: 3`, `trl_target: 3`, `budget_usd: 430` and the new pitch, with the evidence files listed. PDFs are in `docs/pdf/`.

### Requirements (HLT-CAL-001, Table 6)

8 met, 2 not met, 4 at risk, 1 not verifiable at TRL 3.

| ID | Status | Value against target |
| --- | --- | --- |
| R9 | **Not met** | Assumed stowed hinge moment 24.3 N·m at 35 m/s against the NMRV030-class gearbox's 17 N·m rating and 22 N·m listed maximum; rating reached at a 29 m/s gust. Stow trigger at 15 m/s (7.4 N·m) is fine; mast 87 MPa worst case against 240 MPa |
| R13 | **Not met** | 12.5 kg on the mast top against 10 kg; rated gearboxes (about 1.2 kg each, assumed) and stiffer arms add about 4.5 kg to the TRL 2 estimate |
| R3 | At risk | 0.50 kWh on 21 Dec and 1.00 kWh on 1 Feb at reference site A; 0.40 kWh at site B; strongly site dependent |
| R4 | At risk | 0.31° beam typical, 0.50° at the 95th percentile, needing four-point calibration over about 4 h and a preload on each drive; 1.04° without preload (1° listed backlash) |
| R7 | At risk | 19 min hands-on, but the calibration points must span about 4 h |
| R10 | At risk | Stow in 23 s on stored energy, 2.1x margin; the beam moves only downward but crosses the ground beyond 3 m for about 2.8 s |
| R12 | Not verifiable at TRL 3 | Materials chosen for outdoor life |
| R1 | Met | 211 W at the glazing |
| R2 | Met | 502 lx mean added |
| R5 | Met | No sun sensor |
| R6 | Met | 31.5 s after 6 months |
| R8 | Met | Mechanical range; spill limit about 17 m for a 1.0 m window |
| R11 | Met | SELV outdoors, IP65, listed adapter |
| R14 | Met | 0.60 W average |
| R15 | Met | $425 against $430 |

Other key numbers: 159 W and about 15,070 lm into the room at the design point; mast tilt 0.040° at 8 m/s (0.37° for the rejected 40 x 40 mm extrusion); 30 x 50 mm printed arms would flex 0.145°, so the model uses 40 x 70 mm (0.040°); mirror center of mass 13.7 mm off the elevation axis (0.8 N·m); stow reserve 187 J usable against 87 J needed. Every TRL 2 number in the docs was checked against the script and corrected where it differed (HLT-CAL-001, "Checks against earlier figures"): the daily energy is now site-based, the mast-top mass rose from about 8 to 12.5 kg, and the TRL 2 pointing budget's calibration, backlash and yoke terms were optimistic.

### Decisions recorded (HLT-DDR-001)

Decided by Amish, 2026-09-25, going with the recommendation: D1 60.3 mm galvanized steel pipe mast; D2 Wi-Fi forecast plus cup anemometer for storm stow; D3 supercapacitor stow reserve; D4 `budget_usd` raised to $430; D5 pitch reworded to "with no sun sensors" (applied to `project.yaml` and `README.md`); D6 face-down stow; D7 calibration by jogged spot points; D8 Grena algorithm 5 at 30 s with weekly network time; D9 listed indoor 12 V adapter; D10 glass mirror with safety backing film. R15 now reads $430 and R5 allows the anemometer; no other target was relaxed. The SwapCell interface decisions do not apply (HelioLite uses no SwapCell pack).

### Proposed, awaiting Amish

Still open from TRL 2 (no recommendation was made):

1. First site and user for the co-design checklist (O1); partners stay open by Amish's instruction.
2. Local rules on glare and structures at that site (O2), and a siting survey of real yards (O3).

New from TRL 3:

3. **Stowed wind survival (R9).** Options: (A) NMRV040-class elevation gearbox (more mass and cost); (B) rubber stow stops on the yoke that carry the stowed hinge moment in both directions; (C) find published stowed coefficients for small heliostats that justify a lower load. Recommendation: B, checked against C. **Decided by Amish, 2026-09-25: go with recommendation** (HLT-DDR-002 N1).
4. **Drive preload (R4).** A torsion spring of about 3 N·m on each axis (about $6 for two, not yet in the BOM or model). Recommendation: adopt. **Decided by Amish, 2026-09-25: go with recommendation** (HLT-DDR-002 N2).
5. **Mass limit (R13).** Options: (a) relax R13 to 13 kg; (b) lighter drives, which conflicts with R9; (c) aluminum yoke arms. Recommendation: (a). **Decided by Amish, 2026-09-25: go with recommendation** (HLT-DDR-002 N3).
6. **R7 wording.** "30 min or less of hands-on time, spread over one clear day". Recommendation: adopt. **Decided by Amish, 2026-09-25: go with recommendation** (HLT-DDR-002 N4).
7. **R10 wording.** Allow the beam to move only downward, toward the ground, during a stow. Recommendation: adopt. **Decided by Amish, 2026-09-25: go with recommendation** (HLT-DDR-002 N5).
8. **Calibration points.** Use four points over about 4 h as the default (within decision D7's "three or more"). Recommendation: adopt. **Decided by Amish, 2026-09-25: go with recommendation** (HLT-DDR-002 N6).

### Safety concerns

- Beam of 0.88 to 0.93 sun: eye injury and glare; the beam sweeps the ground between target and mast for about 3 s in a power-loss stow; calibration jogs move the spot near people.
- R9 not met: until resolved, remove the mirror if gusts above about 29 m/s are forecast. Caught face-on at 35 m/s the hinge moment (40 N·m) would exceed the gearbox rating, so stow must not fail.
- Pinch points: 20 mm between mirror and arms, 46 mm to the crossbar; 17 N·m drives; a preload spring would store energy with drives off.
- Supercapacitor bank of about 360 J at 12 V: fuse, bleed and label it.
- Glass 2.2 m above ground; mast anchor must resist 0.79 kN·m (1.0 kN·m specified); buried services; working at height on roofs.
- Mains stays indoors in a listed adapter; only 12 V DC outdoors.

### Other notes

- No existing TRL 4 material was found (`build-log/` holds only its README; `electronics/` and `firmware/` are empty). None was created. STANDARDS section 9 asks for a TRL change to be recorded in the build log; no build-log entry was written, since the brief did not name one.
- Citations: the Grena 2012 abstract was checked on ScienceDirect (0.19° to 0.0027°, 2010 to 2110), confirmed. The EN 17037 claim in HLT-PRB-001 cited the ClimateStudio page for the sunlight-exposure recommendation, which that page does not cover; the citation now splits the 300 lx target (ClimateStudio) and the 1.5 h to 4 h sunlight recommendation (SageGlass summary). The full text of EN 17037 was not read. New sources used at TRL 3: StepperOnline and RS listings for the gearbox rating and backlash, and Emes et al. for the effect of chord on stowed coefficients. The stowed coefficients themselves (0.6 force, 0.15 hinge moment) are assumptions, not sourced values, and the gearbox mass (1.2 kg) is assumed.
- BOM prices other than the gearbox are indicative estimates by supplier type, not quotes.

### Recommended next step

Stay at TRL 3. TRL 4 is on hold by Amish's instruction. Decide items 3 to 8 above, starting with R9 (stow stops or a larger gearbox) and the R13 mass limit, get the chosen gearbox's drawing (mass, static holding torque, backlash), then revise HLT-CAL-001, the model and the BOM on paper. Name the first site (item 1) so the hourly model can be run for a real yard.

For reference only, TRL 4 would need: a lab test report (TST, `environment: lab`) on a built gimbal and drive set (holding torque and backlash under load, preload behavior, stow timing on the supercapacitor reserve, calibration residual on a bench or yard setup, beam spot size), build-log entries, and the purchasing and build work that goes with them. None of this has been started.

## Session 2026-09-25: recommendations accepted

Amish's instruction (2026-09-25, in chat): "i accept all your recommendations, go with them across all repos." Every open item with a recommendation is now decided by Amish, 2026-09-25: go with recommendation. Items without a recommendation stay open. TRL 4 remains on hold.

### Decisions applied and what changed

Recorded in `docs/decisions/0002-recommendations-accepted.md` (HLT-DDR-002 v0.1). HLT-DDR-001 moves to v0.2 (O4 marked decided).

| # | Decision | Before | After |
| --- | --- | --- | --- |
| N1 | Stow stops on the yoke carrying the stowed moment in both directions (option B, checked against C) | R9 not met: 24.3 N·m stowed moment on a gearbox rated 17 N·m, 22 N·m listed maximum | Steel lug on the torque tube trapped between a 3 mm polyurethane stop pad and a sprung latch pawl on the -X arm, released by a 12 V pull solenoid; designed for 48.6 N·m (2x, a coefficient up to 0.30); pad deflection 0.28 mm against 0.48 mm free travel at mid-backlash, so the gearbox carries no stowed moment. R9 met on paper. BOM line 17, $20 |
| N2 | Spiral preload spring of about 3 N·m on each axis | Not in BOM or model | BOM line 16, $6 for two; model part 16; elevation spring biases toward stow. R4 still at risk (0.31° typical, 0.50° at the 95th percentile) |
| N3 | Relax R13 to 13 kg | 12.5 kg against 10 kg, not met | 12.95 kg against 13 kg, met with 0.05 kg margin on assumed masses |
| N4 | R7: 30 min hands-on, spread over one clear day | At risk (19 min hands-on, 4 h elapsed) | Met |
| N5 | R10: beam may move only downward during a stow | At risk (2.8 s sweep beyond 3 m) | Met |
| N6 | Four calibration points over about 4 h as the default | Used in the budget, not decided | Default in HLT-PRC-001 and HLT-CAL-001 |

Files changed: `cad/src/model.py` (parts 16 and 17, STEP and STL re-exported); `cad/src/sheets.py` and `cad/drawings/HLT-DWG-001.*` (Rev P1 to P2, new notes, same drawing number); `cad/src/concept_media.py` and all of `media/` (regenerated and checked by eye; `media/_views*` deleted); `bom/bom.csv` (17 lines, $425 to $451) and `bom/bom-notes.md`; `docs/04-calcs/sizing.py` and `01-sizing.md` (HLT-CAL-001 v0.1 to v0.2, new tags [E6] to [E8], results table rebuilt); HLT-REQ-001 and HLT-PRC-001 v0.3 to v0.4; `project.yaml` (DDR-002 added to the TRL evidence; `budget_usd` stays 430, `trl: 3`, `trl_target: 3`); `README.md` (status, components, and the new sections Concept rationale, Burning platform, Where it could be used and What sparked the idea). HLT-PRB-001 did not attribute the idea to a brainstorm and is unchanged. All PDFs in `docs/pdf/`, the drawing and the media were regenerated so no generated file still shows the old personal domain.

### Budget

No accepted recommendation carried a budget figure, so `budget_usd` stays at $430. The two added lines take the BOM to $451, $21 over, and R15 moves from met to **not met**.

### Requirement status (HLT-CAL-001 v0.2, Table 6)

11 met, 1 not met, 2 at risk, 1 not verifiable at TRL 3.

| ID | Status | Value against target |
| --- | --- | --- |
| R15 | **Not met** | $451 against $430 |
| R3 | At risk | 0.50 kWh (21 Dec) and 1.00 kWh (1 Feb) at site A; 0.40 kWh at site B |
| R4 | At risk | 0.31° beam typical, 0.50° at the 95th percentile of calibration |
| R12 | Not verifiable at TRL 3 | Materials chosen for outdoor life |
| R1, R2, R5, R6, R7, R8, R9, R10, R11, R13, R14 | Met | R9 via the stow latch; R13 with 0.05 kg margin; R7 and R10 as reworded |

### Still awaiting Amish

1. First site and user for the co-design checklist (O1); co-design partners stay open.
2. Local rules on glare and structures at that site (O2) and a siting survey of real yards (O3).
3. **New: budget for the $451 BOM (P1).** Options: (a) raise `budget_usd` to $455; (b) keep $430 and cut cost elsewhere (printed turntable, cheaper anemometer); (c) make the anemometer optional where a reliable forecast exists. Recommendation: (a), because both additions are safety or accuracy items. **Decided by Amish, 2026-09-26: budget top-up to $455 (option a), applied in the session below.**

### Cross-repo actions

None. No decision here needs another repo to change.

### Safety concerns

- New pinch point between the stow lug and the latch bracket (3 to 9 mm); the latch pawl snaps shut under spring force; the preload springs store energy with the drives off and pull the mirror toward stow if a drive is disconnected.
- The latch is sized on an assumed stowed coefficient and an assumed polyurethane modulus; until tested, remove the mirror if gusts above about 29 m/s are forecast. A failed stow (caught face-on, 40.5 N·m) still exceeds the gearbox.
- Earlier concerns (beam and glare, stow sweep, glass at height, supercapacitor energy, mast and anchor) are unchanged.

### Notes

- The recommendation "stops in both directions" needed a latch in practice, because a fixed stop can only resist the direction the axis turns into; the latch engages passively so a power-loss stow still latches, and the solenoid is used only to leave stow. This is recorded in HLT-DDR-002 N1 for Amish to see.
- Solenoid, spring and bracket masses and prices are estimates; R13 margin (0.05 kg) is inside their uncertainty.

### TRL 4

TRL 4 remains on hold by Amish's instruction. Building and testing the latch (holding moment, pad compliance, engagement on a power-loss stow), the springs and the drives are TRL 4 work and were not started.

## Session 2026-09-26: sources strengthened

### Sources replaced

Every link in "Concept rationale", "Burning platform", "Where it could be used" and "What sparked the idea" was fetched and checked against its sentence. Kept and confirmed: US EPA (about 90 % of time indoors), IEA (lighting about 8 % of global electricity, about 2,200 TWh, 2024), WHO Housing and Health Guidelines (18 °C), Hong, Wang and Zhang 2024 (Chinese sunlight rules), World Bank 2018 (Ulaanbaatar ger districts).

| Where | Old source | New source |
| --- | --- | --- |
| What sparked the idea | Viganella, Italy (Vice) | Rjukan, Norway, sun mirrors first used in 2013 ([NPR, 2013](https://www.npr.org/2013/11/03/242789411/as-mirrors-beam-light-to-town-norwegians-share-patch-of-sun)). No BBC, Times or CBC account of Viganella could be opened (blocked or refused), and the municipal tourism page supports only the 83 sunless days, so the inspiration was changed. INSPIRATIONS.md line replaced |
| Concept rationale | No citation | NPR, 2013 (civic mirrors); jremington/Arduino_heliostat (clock-driven open heliostat) |
| Region row: United Kingdom and northern Europe | ClimateStudio and SageGlass (vendor pages on EN 17037) | Replaced by a European Union row: Eurostat, 2 February 2026 (9.2 % could not keep their home adequately warm in 2024; 19.0 % in Bulgaria and Greece) |
| Region row: Canada and the northern United States | No citation | Replaced by a United States row: US EIA "Use of energy in homes" (heating and cooling 52 % of household energy in 2020; higher use in the Northeast and Midwest) |
| Region row: Chile and Argentina | No citation | Replaced by a Chile row: UNEP "Chile takes action on air pollution" (firewood up to 94 % of PM2.5 emissions in some cities) |
| Region row: Norway | NPR, 2013 | Removed, because Rjukan is now the inspiration; the rows cover North America, Europe, East Asia, Central Asia and South America |
| HLT-PRB-001 v0.4, "The problem" item 1 | ClimateStudio and SageGlass (EN 17037 targets) | US EPA (about 90 % of time indoors). The EN 17037 figures were removed because the standard is paywalled and no primary summary could be opened |

Not changed and still weak, outside the README sections in scope: HLT-PRB-001 "Prior work" cites Inhabitat and Solar Power World for the Sunflower home heliostat, and Visit Rjukan for the mirror details.

### Budget

- P1 decided by Amish, 2026-09-26 ("I am ok with the budget top ups"): `budget_usd` $430 to $455 in `project.yaml`.
- `docs/04-calcs/sizing.py` hard-codes the budget; `BUDGET` is now 455.0 and the script was re-run: [J1] "total $451.00 against $455 budget; margin $4.00"; [K3] 0 not met, 2 at risk, 1 not verifiable, 12 met.
- R15 not met to met. Documents revised: HLT-REQ-001 v0.5, HLT-CAL-001 v0.3, HLT-DDR-002 v0.2, HLT-PRC-001 v0.5, HLT-PRB-001 v0.4 (sources and budget); `README.md` budget line and status; `bom/bom-notes.md`.
- Concept media: the blueprint key figure in `cad/src/concept_media.py` now reads "Parts $451 against $455 budget, R15 met"; all of `media/` was regenerated and the temporary `_views` folders deleted.
- Still awaiting Amish: O1, O2 and O3.

## Session 2026-09-26: product appearance model and photoreal renders

Amish chose this repo for the first batch of product renders on 2026-09-26.

### What was added

`cad/src/product_model.py` exposes `product_parts()` (70 parts: 36 shell, 25 internal, 1 accessory, 8 context), `TITLE` and `RENDER_VIEWS` (hero, exploded and a detail view of the two-axis drive with the mirror removed). It reuses PARAMS, derived() and parts() from `cad/src/model.py`; the tracking pose (mirror normal 25° up, yoke turned -36.9°), the 2.2 m axis height, the yoke arm spacing, the gearbox, motor, turntable, cap plate, mast, anchor, controller, anemometer, spring can and stow latch envelopes and positions are as model.py. It adds:

- Mirror assembly: glass with a seamed edge over a thin silvered layer, a rubber edge guard, the painted backing panel, aluminum rib tubes with end plugs, the torque tube with clamp saddles and the steel trunnion stubs.
- Yoke: filleted ASA base plate and crossbar, arms with rounded heads around the trunnion and shallow face pockets, flanged bearings and M6 bolts.
- Drives: NMRV030-class gearbox bodies with fillets, output bosses, fins and cover detail; adapter plates with screws; NEMA17 motors with chamfered bodies, aluminum end caps and connectors; the teal turntable with a bearing seam; the galvanized cap plate with bolts; both homing switches.
- Stow stop and latch: lug, bracket with bolts, orange polyurethane stop pad, pawl with pivot pin and the pull solenoid with plunger; the ribbed elevation spring can.
- Controller: IP65 box with side ribs and a parting line, a lid with a clear window over the board (ESP32 module, RTC and coin cell, two stepper drivers with heat sinks, buck converter, terminal block and the five supercapacitors of the stow reserve), lid screws, a lit green status light, cable glands and vent, a teal name plate with the HelioLite wordmark, and mast straps.
- Cabling with stand-off clips on the mast; cup anemometer with hemispherical cups, hub, spokes, body and mast clamp; anchor flange and socket with bolts and set screws; the indoor 12 V power adapter as an accessory in the exploded view.
- Context (not in the BOM): a compact ground patch with a paver pad, a short section of house wall with the target window, sill and a dark room behind the glazing, and the outdoor feed cable running to a wall entry.

`README.md` now shows `media/render-hero.png` and links `media/render-exploded.png`; the orchestrator produces both files.

### Differences from model.py (Proposed, awaiting Amish)

1. **Target distance in the render.** The concept media place the house wall 2.2 m from the mast, itself closer than a real site. The appearance model puts the wall face 1.0 m from the mast, with a 920 mm wide wall section and an 800 x 1,000 mm window, so the heliostat fills the product render. Proposed, awaiting Amish. Recommendation: keep this as a render-only layout; the hero note says the window is drawn closer than a real site.
2. **Mirror edge guard.** BOM line 1 specifies seamed edges and a safety backing film but no edge protection. The appearance model adds a black EPDM U-channel around the glass and panel edges (10 mm lip), which protects hands during fitting and the glass edge against chipping. Proposed, awaiting Amish. Recommendation: adopt it and add it to BOM line 1 or 13 at the next BOM revision (a few dollars, within the $4 margin but to be checked); the BOM was not edited.
3. **Clear window in the controller lid.** BOM line 9 specifies an IP65 box without saying whether the lid is clear. The appearance model uses a lid with a clear polycarbonate window so the board and stow reserve show. Proposed, awaiting Amish. Recommendation: adopt a clear-lid IP65 box (common and similar in price) and add "clear lid" to BOM line 9 at the next revision.
4. **Torque tube saddles.** model.py joins the torque tube directly to the underside of the backing panel, and BOM line 2 lists structural silicone. The appearance model shows two bolted steel saddles clamping the tube to the panel near the ribs. Proposed, awaiting Amish. Recommendation: keep the saddles as the mechanical attachment, with silicone as the bond, and confirm at TRL 4 design review.
5. **Finishes.** model.py colours identify parts only. The appearance model uses off-white ASA for the yoke, a teal painted turntable and name plate, silver-grey gearboxes, black motors, galvanized mast and cap plate and a dark painted anchor. Proposed, awaiting Amish. Recommendation: accept as the product finish set.
6. **Glass layering and small hardware.** The 3 mm glass is split into a 0.4 mm silvered layer and 2.6 mm of glass for rendering; the total thickness is unchanged. Bolts, clips, straps, glands and the name plate are appearance detail under BOM lines 11 and 13; no new BOM lines are implied beyond items 2 and 3.

### Status

This is an appearance model only: no tolerances, no fabrication detail, nothing past TRL 3. `trl: 3` and `trl_target: 3` are unchanged, and TRL 4 remains on hold. model.py, the BOM and the other documents were not edited.

## Session 2026-09-27: kit 1.5.0 and image quality

- Kit 1.5.0 synced: STANDARDS v1.5 (sections 12 to 15: product renders, storefront images and image quality, public release, authorship and signing), `.kit/cards.py`, `.kit/image_qc.py`, `.kit/release_gate.py`, issue templates, and the `/render-product` and `/release` commands. `CLAUDE.md` now matches `.kit/CLAUDE.md`.
- Every `media/render-*.png` recaptioned from its original render with the new layout: the title, concept label and repository sit in a band above the render and the view note in a band below it, each line wrapped to the image width, so no text overlaps other text or the render or runs off the image. `media/card.png` and `media/social-preview.png` regenerated with the same rules.
- `python .kit/image_qc.py` and `python .kit/release_gate.py` pass. trl stays 3.

## Session 2026-10-01: design for construction and prototype build plan (kit 1.7.0)

Under Amish's 2026-09-30 instruction ("If you are realising that the design cannot be built as per concept - fix the design assumptions to match and be physically feasible as you draw the illustrations") and his approval of the build plan format, HelioLite was brought to the approved standard. TRL stays 3; TRL 4 remains on hold.

### What was done

- Kit 1.7.0 installed (`.kit/`, `.claude/commands/`); `CLAUDE.md` matches `.kit/CLAUDE.md`.
- `cad/src/model.py` rebuilt as separate made and bought parts with bolt holes, and a constructability check (`python cad/src/model.py --check`): 1,583 checks of contacts, clearances, overlaps and the elevation sweep from stow to face-up, all passing. STEP and STL re-exported.
- `docs/decisions/0003-design-for-construction.md` (HLT-DDR-003 v0.1, Draft): every change, with its reason; made under Amish's 2026-09-30 instruction to make the design physically buildable; open for his review.
- `cad/src/build_plan_media.py`: overview, 15 making sketches (`cad/drawings/HLT-DWG-101` to `115`), 8 joint close-ups, 18 assembly step pictures and a block-level wiring diagram in `docs/05-build-plan/`.
- `docs/05-build-plan.md` (HLT-BLD-001 v0.1) and `docs/06-design-decisions.md` (HLT-DEC-001 v0.1), both added to `trl_evidence`; `design_state: constructable` in `project.yaml`.
- HLT-CAL-001 v0.4 (`sizing.py` re-run), HLT-PRC-001 v0.6, HLT-REQ-001 v0.6, `bom/bom.csv`, `bom/bom-notes.md`, `README.md` (links line, "Building the prototype" section, key components, value-engineering wording); general arrangement HLT-DWG-001 Rev P4; concept media regenerated.

### Design changes made for construction (HLT-DDR-003)

1. Ribs crossed the torque tube in the same space: ribs are now 25 x 40 mm with a square tunnel the tube runs through.
2. The trunnion rod was loose in the tube and could not be fitted with the mirror in the yoke: aluminum end blocks bolted in the tube ends and two keyed stubs pinned in after the mirror is in place.
3. The one-piece printed yoke could not be printed: an aluminum 60 x 40 x 2 mm tube crossbar and arms with gusset plates, printed bearing plugs; the printed base plate is gone.
4. Bearings had no housing: flanged bronze bushes through arm and plug; the flanges locate the tube.
5. Elevation gearbox had no fixing: bolted flat to the right arm.
6. Elevation spring can floated off the arm: screwed to the left arm, spring stub into it.
7. Turntable sat loose on the gearbox with no shaft: double output shaft, thrust washer, keyed hub and a 120 x 10 mm disc; the shaft drives the azimuth spring in the mast.
8. Cap plate to mast undefined: threaded floor flange on the pipe, cap screwed to it from below.
9. Stow latch could not release (pawl lifted inside the lug's swing) and was poorly supported: lug on a square collar, sliding pawl, bent bracket with a stop block, solenoid on a strap.
10. Homing switches sensed nothing: azimuth switch on a post under a magnet in the disc; elevation switch beside a magnet in the lug.
11. Controller box floating: plate and two U-bolts.
12. Anemometer arm touching the mast at a point: right-angle clamp.
13. Cable ran through the anchor flange and missed the turning yoke: rerouted, with a service loop to the crossbar.
14. Mast loose in its socket: two set bolts.

### Key results

- Requirements (HLT-CAL-001 v0.4): 11 met on paper, 2 at risk (R3, R4), 1 not verifiable at TRL 3 (R12), none not met; R15 over the value-engineering target by $37.
- Value-engineering target: USD 455. Estimated cost of the constructable design: USD 492 (USD 37 over the target).
- Mast-top mass 12.94 kg against 13 kg (0.06 kg margin, on an assumed 1.2 kg gearbox); arm flex 0.040 to 0.006 degrees; pointing 0.30 degrees beam typical, 0.50 degrees at the 95th percentile; crossbar clearance 46 to 56 mm.

### Proposed, awaiting Amish

All open items are in `docs/06-design-decisions.md`. New this session: the R13 mass margin (A1), how the head goes on the mast (A2) and updating the appearance model and renders (A3), each with a recommendation; and ten items to confirm when parts are bought.

### Stale until regenerated on Amish's Mac

The photoreal renders `media/render-*.png` (made on Amish's Mac; not in this cloud copy), `media/card.png` and `media/social-preview.png` show the printed yoke, the concept latch and the torque tube saddles; the design changed visibly. `cad/src/product_model.py` was not updated.

### Safety concerns

Unchanged in kind: the beam (glass kept covered from bonding until calibration), glass handling, high-torque drives and wound preload springs, the stow reserve's stored energy, and lifting the 11 kg head onto the mast at 1.8 m (two people, stable steps, mirror latched and covered). The build plan's safety stops S1 to S8 cover each.

### Recommended next step

Amish reviews HLT-DDR-003 and the register. TRL 4 (building and testing to the plan) stays on hold.

## Session 2026-10-02: open decisions decided

On 2026-10-02 Amish approved the recommendations for every open decision: "i approve your recommendations for all 555 open decisions." The 11 open decisions of the design decisions register are now in its Decisions made table, dated 2026-10-02.

HLT-DDR-003 Table 3 items A1 to A3 are decided (A1 and A2 on changed recommendations: an aluminum latch bracket now, and fitting the head in two lifts from a stable platform). The acceptance of HLT-DDR-003 Table 1 as a whole was never among the open decisions; Amish accepted it later on 2026-10-02 (see the next session). The value engineering savings no longer list the box without a clear lid. Review flag 3 (a forecast-only stow weakening the storm-stow backup) was not part of any decision and that saving is still listed with its caveat.

### Documents changed

- `docs/06-design-decisions.md` (HLT-DEC-001 v0.2)
- `docs/decisions/0003-design-for-construction.md` (HLT-DDR-003 v0.2)
- `docs/01-problem.md` (HLT-PRB-001 v0.5)
- `docs/02-concept.md` (HLT-PRC-001 v0.7)
- `docs/03-requirements.md` (HLT-REQ-001 v0.7)
- `docs/05-build-plan.md` (HLT-BLD-001 v0.2)
- `bom/bom-notes.md` (not a controlled document)
- `README.md` (not a controlled document)

### Follow-up actions to carry approved decisions into the design

1. Decision 5: Model and drawings: make the latch bracket aluminum in `cad/src/model.py` and on making sketch HLT-DWG-110, rechecking its bending under the stowed load.
2. Decision 5: BOM and calculations: change line 17's latch bracket to aluminum with its price, and take about 0.1 kg off the mast-top mass (HLT-CAL-001, H3).
3. Decision 6: Build plan and pictures: redraw steps 10 to 17 so the yoke and drive go on the mast first and the mirror assembly (about 6.2 kg) is lowered into it from a stable platform; regenerate the step pictures.
4. Decision 6: Model: add the platform-height fitting sequence to `cad/src/build_plan_media.py` and check the mirror assembly can be lowered into the yoke with the trunnions fitted.
5. Decision 7: Appearance model and renders: update `cad/src/product_model.py` and the photoreal renders on Amish's Mac to the aluminum yoke, the new latch and the rib tunnels, dropping the torque tube saddles; finish set of item 11 and caption of item 8 with them.
6. Decision 9: BOM: add about 2.4 m of black EPDM edge channel with its price (line 1 or 13).
7. Decision 9: Model and calculations: add the edge channel to the mirror assembly and the mast-top mass (about 0.15 to 0.25 kg); if the weighed head exceeds 13 kg, propose a slight R13 relaxation.
8. Decision 9: Build plan pictures: show the edge channel in step 5 after bonding.
9. Decision 10: BOM: change line 9's specification to an IP65 box with a clear lid.
10. Decision 3: Run the desk siting survey of 20 to 30 yards and record it (HLT-CAL-001, section B, or a new note).

### Points found in the review

1. Item 9's edge guard would use up the 0.06 kg R13 margin (item 5) by itself; the two items must be decided together.
2. A saving in Value engineering (a box without a clear lid) contradicts the recommendation in item 10.
3. A saving in Value engineering (forecast-only stow, making the anemometer optional) weakens the storm-stow backup in the safety case and should not be counted as a saving.
4. REVIEW 2026-09-26 item 2 says the edge guard fits 'within the $4 margin'; the estimate is now USD 37 over its target, so that wording is stale.

No CAD model, BOM quantity or price, calculation result or picture was changed. TRL stays at 3; TRL 4 remains on hold.

## Session 2026-10-02: design-for-construction changes accepted

Amish, 2026-10-02: "APPROVED: Design-for-construction changes in 10 repos (CityTwin, CoolShade, PalletPilot, Heliolite, PotholeLog, EarthPress, ReadyKit, CellCheck, CargoMule and ThermaCart)". This accepts the whole change table of HLT-DDR-003, Table 1 (P1 to P14), whose acceptance had not been among the open decisions decided earlier the same day. No other item is decided by it. trl stays 3; no build or test work was done, and the model, BOM, calculations and pictures are unchanged.

### Documents changed

- `docs/decisions/0003-design-for-construction.md` (HLT-DDR-003 v0.3, status Draft): status line now "accepted" with Amish's words.
- `docs/06-design-decisions.md` (HLT-DEC-001 v0.3): Decisions made row added, dated 2026-10-02.
- `docs/05-build-plan.md` (HLT-BLD-001 v0.3): section 2 says HLT-DDR-003 is accepted.
- PDFs regenerated.

### Recommended next step

No change: the follow-up actions of the previous session stand. TRL 4 remains on hold by Amish's instruction.

## Session 2026-10-02: approved follow-ups carried out

Amish, 2026-10-02: "497 follow-up actions that need CAD, drawing, picture, BOM or calculation work ... APPROVED CHANGES, COMPLETE THESE", and for the renders: "Photoreal renders are out of date in most repos ... COMPLETE THESE". This session carried the decisions of 2026-10-02 into the model, BOM, calculations, drawings, pictures and appearance model. trl stays 3; no build or test work was done.

### Follow-ups (from the 2026-10-02 list)

1. Done. Latch bracket and stop block made aluminum in `cad/src/model.py`: 6 mm aluminum angle (6063-T6), cut with no bending, in place of 4 mm bent steel plate; making sketch HLT-DWG-110 redrawn. Bending rechecked [E9]: the pawl's moment (11.5 N·m at the design load) bends the leg to 36 MPa against 170 MPa minimum yield (factor 4.7), and the 6 mm leg is 1.16 times as stiff as the steel bracket.
2. Done. BOM line 17 respecified and repriced (USD 22 to USD 23); mast-top mass updated in HLT-CAL-001 [H3]. The aluminum bracket and block save 0.08 kg, a little under the 0.1 kg expected.
3. Done. Build plan steps 10 to 17 rewritten and redrawn for the two-lift fitting: step 10 elevation drive onto the right arm on the bench; steps 11 to 14 mast, controller, flange and cap (were 13 to 16); step 15 first lift, the yoke with drive, latch, disc and hub (4.48 kg); step 16 second lift, the mirror assembly (6.34 kg) lowered in from a stable platform onto two 54 mm packers on the crossbar; step 17 stubs, cross pins and spring can at height, then stow and latch. Safety stops S3 and S6 renumbered and S6 now covers each lift.
4. Done. The fitting sequence is in `cad/src/build_plan_media.py` (steps 10 and 15 to 17), and `model.py --check` now lowers the mirror assembly (end blocks fitted, no stubs) between the arms from 450 mm above its seat in 25 mm steps against every fixed yoke part. The check found that the elevation Hall switch, 3 mm proud of the left arm, stood in the path of the torque tube's end (the tube end passes 2 mm from the arm face); the old bench sequence had the same clash. Fix made: the switch now sits in a 13 x 16 mm window in the arm's inner wall, its back on the bearing plug, 1 mm proud, so the tube end passes it with 1 mm to spare (HLT-DWG-107 redrawn). All 3,634 checks pass.
5. Done in this repo. `cad/src/product_model.py` rebuilt on the constructable solids of `build_components()`: natural aluminum tube yoke with gussets, printed plugs and bronze bushes, the aluminum latch bracket, sliding pawl and solenoid, rib tubes with tunnels, end blocks and pinned stubs, the EPDM edge channel, the turntable disc on its keyed hub, cap plate and floor flange; torque tube saddles and the printed yoke dropped. Finish set of item 11 (option a) applied; the hero note says the wall is drawn 1.0 m from the mast as a render-only layout (item 8). Render scenes exported to `/home/claude/renders/heliolite`. Not done here: the photoreal renders, captions, `card.png` and `social-preview.png`, which are made on Amish's Mac next.
6. Done. BOM line 1 adds 2.5 m of black EPDM U edge channel (about USD 2.40 per m, +USD 6; USD 25 to USD 31).
7. Done. Edge channel added to the model's mirror assembly (2.5 mm wall, 3 mm lip over the glass, 8 mm over the panel back; cut back 15 mm each side of the tube on the right edge and 95 mm each side on the left edge so the lug, bracket and pad pass in the elevation sweep): 0.16 kg for about 2.2 m fitted [H1]. Mast top 12.99 kg against 13 kg, margin 0.01 kg [H3]. The estimate does not exceed 13 kg, so no R13 relaxation is proposed; the decision of 2026-10-02 already provides one if the head weighed at TRL 4 exceeds 13 kg.
8. Done. Step 5 now shows and describes the edge channel pressed on after bonding.
9. Done. BOM line 9 specifies an IP65 box with a clear polycarbonate lid; price unchanged (clear-lid boxes of this size list at about the same price).
10. Not done: the desk siting survey of 20 to 30 real yards is research needing satellite images of real properties chosen by Amish's network (outreach, not design work).

### Requirement status changes

None. R1 207 W (was 211 W) and R2 492 lx (was 502 lx) stay met: the edge channel's 3 mm front lip trims the clear aperture from 0.36 to 0.353 m². R3 stays at risk, but reference site A now falls 2 % short on the solstice (0.491 kWh, was 0.501 kWh) and meets 0.5 kWh from about mid-January. R13 stays met with 0.01 kg margin. R15 stays over the value-engineering target.

Value-engineering target: USD 455. Estimated cost of the constructable design: USD 499 (USD 44 over the target). `budget_usd` unchanged.

### Documents changed

- `cad/src/model.py`, STEP and STL exports regenerated; `docs/04-calcs/sizing.py`.
- `bom/bom.csv` (lines 1, 9, 17), `bom/bom-notes.md`.
- `docs/04-calcs/01-sizing.md` (HLT-CAL-001 v0.5), `docs/03-requirements.md` (HLT-REQ-001 v0.8), `docs/02-concept.md` (HLT-PRC-001 v0.8), `docs/05-build-plan.md` (HLT-BLD-001 v0.4), `docs/06-design-decisions.md` (HLT-DEC-001 v0.4), `README.md`.
- General arrangement HLT-DWG-001 Rev P5; making sketches HLT-DWG-104, 107, 110 and 114; build plan overview, joint 5 and steps 5, 8 and 10 to 18; concept media (`cad/src/concept_media.py`: key figures and flow at the clear aperture).
- `cad/src/product_model.py`; render scenes in `/home/claude/renders/heliolite`.
- PDFs regenerated.

### Points for Amish

- The edge channel's front lip costs 2 % of the light. A channel with no front lip (back lip and edge only) would keep R3 at site A on the solstice at the target but guards the glass face edge less. Proposed, awaiting Amish: keep the 3 mm lip (recommended, the guard's purpose is the glass edge).
- R13's margin is now 0.01 kg on an assumed gearbox mass; weighing at TRL 4 decides it, as already decided.

### Cross-repo actions

None.

### Recommended next step

Photoreal renders on Amish's Mac from the exported scenes. TRL 4 remains on hold.

## 2026-10-02: photoreal renders redone on the constructable design

Rendered with Blender Cycles on Amish's Mac from the updated appearance model; captioned with `.kit/photo_caption.py`; `media/card.png` and `media/social-preview.png` regenerated with `.kit/cards.py`. Views: hero, exploded, detail. image_qc passes. Appearance deviations are those logged above as proposed, awaiting Amish.

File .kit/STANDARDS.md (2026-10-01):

---
doc_id: OHP-STD-001
title: Documentation and drawing standard
project: Open Hardware Portfolio
doc_type: Standard
version: "1.7"
status: Released
date: 2026-09-30
author: Amish Chadha
license: CC-BY-SA-4.0
revisions:
  - version: "1.0"
    date: 2026-09-24
    author: Amish Chadha
    change: First release of the standard
  - version: "1.1"
    date: 2026-09-24
    author: Amish Chadha
    change: Adopt Technology Readiness Levels (section 9) for project maturity
  - version: "1.2"
    date: 2026-09-24
    author: Amish Chadha
    change: Portfolio phase cap (section 10), concept media standard (section 11), CLAUDE.md guardrails
  - version: "1.3"
    date: 2026-09-24
    author: Amish Chadha
    change: Scale figure, interactive 3D viewer and flow diagrams added to concept media; session slash commands
  - version: "1.4"
    date: 2026-09-26
    author: Amish Chadha
    change: Every sheet and render names the project and its GitHub repository; overall dimensions, ISO centre lines and 300 dpi PNG on sheets; titles name the device and view labels state the viewing direction; optional photoreal renders with Blender
  - version: "1.5"
    date: 2026-09-27
    author: Amish Chadha
    change: Product renders (section 12), storefront images and image quality check (section 13), public release and release gate (section 14), authorship, citation and commit signing (section 15)
  - version: "1.6"
    date: 2026-09-29
    author: Amish Chadha
    change: Licensing metadata with REUSE (section 16), Zenodo DOI and Software Heritage archiving (section 17), release gate checks REUSE and a single CITATION.cff license, archive.py
  - version: "1.7"
    date: 2026-09-30
    author: Amish Chadha
    change: Concept and constructable design states; design decisions register (DEC) kept apart from the build plan; prototype build plan (BLD, section 18) with pictures by component is required TRL 3 evidence; every repo targets TRL 3 during the populate phase; build_views.py; /to-trl3 and /build-plan commands
---

# Documentation and drawing standard

Every project in the portfolio uses this standard, so that each precis, write-up and sketch looks the same and carries its own version history. The standard ships as a kit in each repo's `.kit/` folder. The kit version is in `.kit/KIT_VERSION`.

## 1. Document types and IDs

Every controlled document has a unique ID in the form `PRJ-TYP-NNN`.

- `PRJ` is the three-letter project code listed in section 7.
- `TYP` is the document type code from the table below.
- `NNN` is a sequence number within that project and type, starting at 001.

| Code | Type | Typical file |
| --- | --- | --- |
| PRC | Design precis | `docs/02-concept.md` |
| PRB | Problem statement | `docs/01-problem.md` |
| REQ | Requirements | `docs/03-requirements.md` |
| CAL | Calculation or sizing note | `docs/04-calcs/*.md` |
| DDR | Design decision record | `docs/decisions/*.md` |
| BOM | Bill of materials | `bom/bom.csv` |
| DWG | Drawing or sketch sheet | `cad/drawings/*.svg` |
| BLD | Prototype build plan (section 18) | `docs/05-build-plan.md` |
| DEC | Design decisions register (section 18) | `docs/06-design-decisions.md` |
| TST | Test plan or test report (front matter adds `environment: lab` or `relevant`) | `docs/05-tests/*.md` |

Example: `TBK-PRC-001` is the ThermaBrick design precis.

## 2. Revision scheme

| Artifact | While in draft | When released | Change after release |
| --- | --- | --- | --- |
| Documents | 0.1, 0.2, 0.3 ... | 1.0 | 1.1 for minor edits, 2.0 for a design change |
| Drawings | Rev P1, P2 ... (preliminary) | Rev A | Rev B, C ... |

- Every change to a controlled document adds a row to its revision history before the commit.
- The `version` field in front matter always equals the newest row in `revisions`. The renderer rejects a document where they differ.
- Status is one of `Draft`, `In review`, `Released` or `Superseded`. Draft and In review documents print with a status band on every page.
- Every release is tagged in Git as `<doc_id>/v<version>`, for example `TBK-PRC-001/v1.0`. Drawings are tagged `TBK-DWG-001/revA`.
- Git history is the full audit trail. The in-document revision table is the human-readable summary.

## 3. Document front matter

Every Markdown document under version control starts with this block:

```yaml
---
doc_id: TBK-PRC-001
title: ThermaBrick design precis
project: ThermaBrick
doc_type: Precis
version: "0.1"
status: Draft
date: 2026-09-24
author: Amish Chadha
license: CERN-OHL-S-2.0
revisions:
  - version: "0.1"
    date: 2026-09-24
    author: Amish Chadha
    change: Initial draft
---
```

Quote version numbers so YAML keeps `1.0` as text instead of turning it into a number. List revisions newest last.

## 4. Writing style

- Chicago Manual of Style.
- No em dashes. Restructure the sentence instead.
- Lead each section with its conclusion, then support it.
- SI units throughout, in the form `12 kW`, `450 °C`, `3.2 m`. Imperial values may follow in parentheses.
- Number every figure and table ("Figure 2", "Table 1") and give each a caption.
- State every assumption in the calculation that depends on it.
- Put safety notes in a blockquote starting with **Safety:**.

## 5. Visual identity

| Element | Specification |
| --- | --- |
| Typeface | IBM Plex Sans for text, IBM Plex Mono for code and values (SIL Open Font License, bundled in `.kit/fonts`) |
| Ink | `#111827` |
| Secondary text | `#4B5563` |
| Rules and grid | `#D1D5DB` |
| Accent (one only) | `#0F766E` teal |
| Document page | US Letter, 20 mm margins |
| Drawing sheet | ANSI B landscape (431.8 x 279.4 mm) |
| Footer | Document ID, version, status, license and designmolecule.com on every page |

## 6. Drawing and sketch conventions

- Units are millimeters unless the title block says otherwise.
- Third-angle projection, marked with the symbol in the title block.
- Line weights: visible outlines 0.5 mm, hidden lines 0.25 mm dashed, center lines 0.18 mm chain.
- The title block contains the project, title, drawing number, revision, scale, units, projection, sheet, author, date, material or notes, and license.
- Every sheet and every render names the project and its GitHub repository (from `repo:` in `project.yaml`), at the top of the sheet and in the title block, so a printed or forwarded sheet is never anonymous.
- The drawing title names the device, not only the drawing type (for example "Handheld near-infrared resin scanner: general arrangement").
- Every view label states its scale and viewing direction (for example "Scale 1:1; side elevation looking along +Y"), and every isometric or render states where it is seen from.
- Orthographic views generated with `add_ortho` carry overall dimensions (length and depth on the top view, height on the front view) and ISO 128 centre lines on cylinders; hidden lines are dashed. Tolerances are not shown before TRL 4.
- Sheets are exported as SVG, PDF and a 300 dpi PNG.
- The revision table in the top right of the sheet lists every revision.
- Concept sketches use the same sheet and title block and carry the label "CONCEPT, NOT FOR FABRICATION".
- Geometry comes from `cad/src/*.py` (build123d). Sheets are generated by `.kit/drawing.py` and never edited by hand.

## 7. Project codes

| Code | Project | Code | Project | Code | Project |
| --- | --- | --- | --- | --- | --- |
| TBK | ThermaBrick | PCF | PicoFlow | HLT | HelioLite |
| CCB | CharCube | DRN | DustRunner | TRT | TremorTrace |
| STC | StepCue | FXH | FlexHand | CPD | ColdPod |
| SCL | SunClave | STR | SteamRoot | GGD | GrainGuard |
| SDL | SeedLine | ZBX | ZeerBox | RMS | RootMesh |
| DWD | DewDrive | SSK | StillStack | PPR | PotPress |
| WWT | WaterWatch | LMF | LumaFlow | FCL | FieldCell |
| CNP | ConePro | CVC | CulvertCrawl | EGD | EmberGuard |
| SNF | SnapFrame | CGM | CargoMule | SCM | StepClimber |
| SWC | SwapCell | PLP | PalletPilot | FTK | FlatTrike |
| WWK | WaterWalker | GRR | GrowRider | SSP | SunSpoke |
| SGN | StepGen | PBX | PowerBox | WML | WasteWise-ml |
| WSC | WasteWise Scan | RFE | ReflowEconomy | | |
| OHP | Portfolio-wide | | | | |

## 8. Build and publish

- `python .kit/render.py` checks every controlled document and renders it to `docs/pdf/<doc_id>_v<version>.pdf`.
- `python .kit/drawing.py` (called from each project's `cad/src/sheets.py`) builds drawing sheets as SVG and PDF in `cad/drawings/`.
- The GitHub Action in `.github/workflows/docs.yml` runs the checks on every push and attaches PDFs to a GitHub Release whenever a release tag is pushed.
- Public releases follow section 14: `python .kit/release_gate.py` must pass, and the release tag is `v0.<TRL>.0` (for example `v0.3.0` at TRL 3).

## 9. Technology Readiness Level (TRL)

Each project states its maturity as a Technology Readiness Level on the NASA and US DOE 1 to 9 scale. The TRL rates this specific design, not the underlying technology. A sand battery is commercial elsewhere, but a new sand battery design starts at TRL 2 until evidence shows otherwise.

| TRL | Definition | Evidence the repo must contain |
| --- | --- | --- |
| 1 | Basic principles observed | Problem statement (PRB) |
| 2 | Technology concept formulated | Draft precis (PRC) and requirements (REQ) |
| 3 | Analytical or experimental proof of concept | Calculation note (CAL), working build123d model with STEP export, drawing sheet (DWG), priced BOM with every unit cost filled in, prototype build plan (BLD) with pictures, `design_state: constructable` |
| 4 | Components validated in the lab | Test report (TST) with `environment: lab`, build log entries |
| 5 | Validated in a relevant environment | Test report (TST) with `environment: relevant` |
| 6 | System prototype demonstrated in a relevant environment | Precis at version 1.0 or later with status Released, a drawing at a lettered revision (Rev A or later), and a system-level TST with `environment: relevant` |
| 7 to 9 | Operational demonstration through proven in service | Beyond portfolio scope; claim only with a named deployment partner and evidence |

Rules:

- `project.yaml` records `trl` (current level), `trl_target` (the level the current effort aims for) and `trl_evidence` (the files that support the claim).
- `python .kit/render.py --check` fails if the evidence for the claimed TRL is missing. CI runs this check on every push.
- Documentation alone cannot go past TRL 3. TRL 4 and above require hardware and a test report.
- TRL and visibility are independent. A repo can be public at TRL 3 as a documented design ready to build.
- A change of TRL is recorded in the build log with the date and the evidence that justified it.
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

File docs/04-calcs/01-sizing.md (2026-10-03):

---
doc_id: HLT-CAL-001
title: HelioLite sizing calculations
project: HelioLite
doc_type: Calculation
version: "0.5"
status: Draft
date: '2026-10-02'
author: Amish Chadha
license: CERN-OHL-S-2.0
revisions:
- version: "0.1"
  date: '2026-09-25'
  author: Amish Chadha
  change: First issue for TRL 3 (optics, hourly energy at reference sites, stiffness, pointing and calibration, wind and drives, stow reserve, mass, power, cost)
- version: "0.2"
  date: '2026-09-25'
  author: Amish Chadha
  change: Recommendations accepted by Amish (DDR-002)
- version: "0.3"
  date: '2026-09-26'
  author: Amish Chadha
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

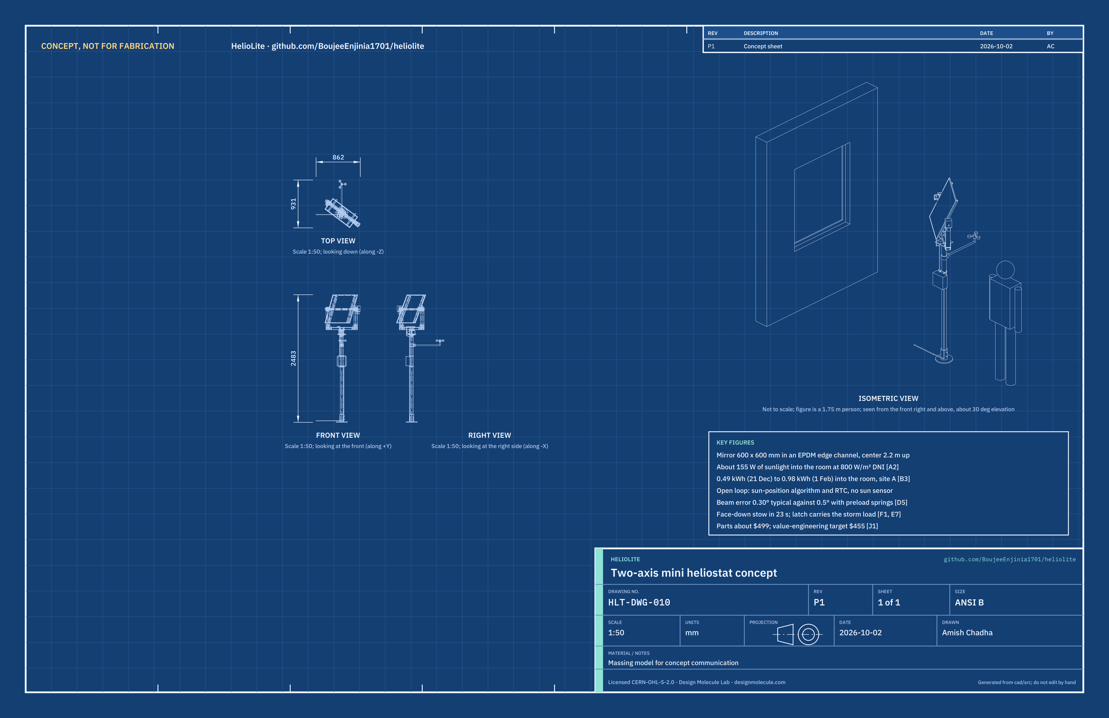
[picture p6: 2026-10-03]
media/concept-blueprint.png

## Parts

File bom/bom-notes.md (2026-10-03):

# BOM notes

- Prices are indicative US retail figures for one prototype, not quotes. The NMRV030 gearbox price ($34.02) and its listed rating (17 N·m at 50:1, 1° backlash) are from the [StepperOnline listing](https://www.omc-stepperonline.com/nmrv30-worm-gearbox), checked on 2026-09-25; other lines are estimates by supplier type.
- All 17 lines are priced. Value-engineering target: USD 455 (`budget_usd` in `project.yaml`, a hypothetical control target, not a limit; Amish, 2026-10-01). Estimated cost of the constructable design: USD 499 (USD 44 over the target). `docs/04-calcs/sizing.py` reads this file and prints the total [J1]. The target was raised from $400 to $430 by Amish on 2026-09-25 (HLT-DDR-001 D4) and to $455 by a top-up he approved on 2026-09-26 (HLT-DDR-002 P1); the cost drivers and savings worth trying are in `docs/06-design-decisions.md`.
- Items 1 to 11, 14, 16 and 17 match the numbered callouts in `media/exploded.png`. Items 12 (indoor adapter), 13 (hardware) and 15 (stow reserve, inside the controller box) have no callout.
- Changes at TRL 3: drives are now NEMA17 motors on NMRV030-class 50:1 gearboxes with a listed rating, with adapter plates and shaft sleeves (lines 4 and 5); the yoke arms grew to 40 x 70 mm (line 3); the turntable carries one thrust bearing on the gearbox output (line 6); the anemometer (line 14) and supercapacitor stow reserve (line 15) were added after decisions D2 and D3.
- Changes under HLT-DDR-002 (2026-09-25, recommendations accepted by Amish): drive preload springs added (line 16, $6 for two) and the stow stop and latch added (line 17, $20: steel lug, bracket, polyurethane pad, sprung pawl, 12 V pull solenoid and MOSFET driver).
- Not included: tools, 3D printer time and shipping.
- Shared SwapCell packs are not used by HelioLite, so the portfolio rule that prices them once does not apply here.
- Changes under HLT-DDR-003 (2026-10-01, design for construction): line 2 ribs 25 x 40 mm with tunnels, trunnion end blocks and pinned keyed stubs (+$6); line 3 aluminum tube yoke with gussets, printed bearing plugs and bronze bushes in place of the one-piece printed yoke (-$2); line 5 floor flange and tapped cap (+$8); line 6 120 mm disc, keyed aluminum hub, double output shaft and thrust washer (+$13); line 9 mounting plate and U-bolts (+$6); line 13 more fixings (+$4); line 14 right-angle clamp (+$4); line 17 stop block and sliding pawl (+$2). Total $451 to $492.
- Decisions of 2026-10-02 (HLT-DEC-001), carried into the BOM on 2026-10-02: line 1 adds 2.5 m of black EPDM U edge channel round the glass and panel edges (about $2.40 per m, +$6; about 2.3 m fitted, cut back at the torque tube and the latch); line 9 specifies an IP65 box with a clear polycarbonate lid (clear-lid boxes of this size list at about the same price, $0); line 17's latch bracket and stop block are 6 mm aluminum angle and bar in place of 4 mm steel (+$1; about 0.15 kg lighter); the gimbal yoke of line 3 stays natural aluminum. Total $492 to $499.

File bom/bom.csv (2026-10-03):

item | qty | spec | supplier | unit_cost_usd | make_buy | notes
1 Glass mirror | 1 | 600 x 600 x 3 mm silvered float glass mirror, seamed edges, safety backing film; 2.5 m of black EPDM U edge channel for a 7 mm edge (3 mm lip over the glass, 8 mm over the panel back), round the glass and panel edges | Local glazier and hardware or online seller | 31.00 | buy | Indicative price: glass about $25; edge channel about $2.40 per m x 2.5 m, about $6; glass decided 2026-09-25 (HLT-DDR-001 D10), edge channel decided 2026-10-02 (HLT-DEC-001)
2 Backing panel and torque tube | 1 | 4 mm aluminum composite panel 600 x 600 mm; two 25 x 40 x 1.5 mm aluminum rib tubes 560 mm long, each with a 25.5 mm square tunnel cut for the torque tube; 25 x 25 x 2 mm aluminum square tube 636 mm; two aluminum trunnion end blocks 21 x 21 x 60 mm (from 22 mm square bar) with 5 mm cross pins; two 14 mm steel trunnion stubs (drive stub 148 mm with a 5 mm key, spring stub 108 mm); four M6 x 35 bolts; structural silicone | Metal supplier and hardware shop | 36.00 | buy | Indicative price; ribs, end blocks and stubs specified for construction (HLT-DDR-003)
3 Gimbal yoke | 1 | Aluminum rectangular tube 60 x 40 x 2 mm (6063): crossbar 720 mm and two arms 397 mm; four 3 mm aluminum gusset plates; two printed ASA bearing plugs; two flanged bronze bushes 14 x 18 x 40 mm; M6 bolts with crush sleeves | Metal supplier, bearing supplier and home printer | 38.00 | make | Indicative price; the one-piece printed yoke could not be printed, so the frame is aluminum tube with printed bearing plugs (HLT-DDR-003)
4 Elevation drive | 1 | NEMA17 stepper (48 mm, about 0.45 N m holding) on an NMRV030-class 50:1 worm gearbox (rated 17 N m output, 14 mm hollow bore), NEMA17 to NMRV030 adapter plate and 5 to 11 mm shaft sleeve | Stepper motor distributor (for example StepperOnline) | 52.00 | buy | Gearbox listed at $34.02; motor about $12; adapter about $6
5 Azimuth drive and mast cap | 1 | Same motor, gearbox and adapter as item 4, plus a 160 x 160 x 8 mm steel mast cap plate (16 mm center hole, four M8 tapped holes), a 2 in threaded galvanized floor flange on the mast top and four M8 x 20 screws; gearbox held by four M6 countersunk screws from under the cap | Stepper motor distributor and steel supplier | 68.00 | buy | Indicative price; gearbox bore vertical; floor flange and tapped cap replace the welded socket (HLT-DDR-003)
6 Azimuth turntable and bearing | 1 | 120 x 10 mm aluminum turntable disc; 14 mm keyed-bore aluminum flange hub 50 mm with a set screw (to fit the disc's 30 mm center hole); NMRV030 double output shaft 14 mm with key; bronze thrust washer 15 x 40 x 2 mm | Bearing supplier | 28.00 | buy | Indicative price; shaft, hub and thrust washer specified for construction (HLT-DDR-003)
7 Mast | 1 | 60.3 mm OD x 3.9 mm galvanized steel pipe (2 in schedule 40), 1.70 m, with cap | Hardware or steel supplier | 35.00 | buy | Indicative price; mast decided 2026-09-25 (HLT-DDR-001 D1)
8 Ground anchor and flange | 1 | Ground screw for 60 mm posts, about 800 mm long, with socket and flange, or concrete footing with a bolted flange; overturning capacity at least 1.0 kN m | Fencing or hardware supplier | 35.00 | buy | Indicative price; check for buried services; rating to confirm
9 Controller box | 1 | ESP32 module, DS3231 RTC with coin cell, two TMC2209 stepper drivers, 12 V to 5 V buck converter, IP65 box 180 x 80 x 180 mm with a clear polycarbonate lid, glands and terminals; 3 mm aluminum mounting plate 140 x 220 mm and two 2 in U-bolts | Electronics distributor | 51.00 | buy | Indicative price; mounting plate and U-bolts added (HLT-DDR-003); clear lid decided 2026-10-02 (HLT-DEC-001), clear-lid IP65 boxes of this size list at about the same price, so the price is unchanged
10 Homing Hall switches | 2 | Unipolar Hall switch with potted lead and small neodymium magnet | Electronics distributor | 3.00 | buy | Indicative price; axis homing only
11 Cabling | 1 | Two 1.5 m shielded 4-core motor leads, 15 m of 2-core 1.0 mm2 outdoor cable, cable glands and clips | Electronics distributor | 20.00 | buy | Indicative price; 12 V feed from indoors
12 Power adapter | 1 | Listed 12 V 3 A plug-in adapter for indoor use | Electronics retailer | 15.00 | buy | Indicative price; no exploded-view callout; stays indoors (HLT-DDR-001 D9)
13 Hardware and consumables | 1 | Stainless fasteners (M5, M6 and M8 bolts, nyloc nuts, washers, crush sleeves), cable clips and ties, medium thread locker, anti-seize | Local hardware shop | 16.00 | buy | Indicative price; no exploded-view callout
14 Cup anemometer | 1 | Pulse-output cup anemometer (reed switch) on a 20 mm aluminum side arm 550 mm, with a right-angle pipe clamp (60.3 mm to 20 mm) | Weather station parts supplier | 24.00 | buy | Weather sensor for storm stow (HLT-DDR-001 D2); not a sun sensor; clamp added (HLT-DDR-003)
15 Supercapacitor stow reserve | 1 | Five 2.7 V 25 F supercapacitors in series (5 F, 13.5 V), balancing resistors, input diode, charge resistor and voltage sense divider, inside the controller box | Electronics distributor | 15.00 | buy | Indicative price; stow on power loss (HLT-DDR-001 D3); no separate callout (inside item 9)
16 Drive preload springs | 2 | Flat spiral (clock) spring in a printed can, about 3 N m over the axis travel, biasing each axis one way (elevation toward stow); elevation can on the -X trunnion, azimuth can inside the mast top | Spring supplier | 3.00 | buy | Indicative price; preload decided 2026-09-25 (HLT-DDR-002 N2); about $6 for two as recommended
17 Stow stop and latch | 1 | 8 mm steel stow lug with a square collar and M5 set screw on the torque tube; latch bracket with a back wall cut from 6 mm aluminum angle (6063-T6) and an aluminum stop block 15 x 30 mm, bolted to the -X arm; 3 mm polyurethane (90A) stop pad; sliding steel latch pawl with return spring; 12 V pull solenoid on a strap, with MOSFET driver | Metal supplier and electronics distributor | 23.00 | buy | Indicative price (solenoid about $8; 6 mm aluminum angle and bar offcuts about $4 against about $3 for the 4 mm steel plate and bar); stow stops decided 2026-09-25 (HLT-DDR-002 N1); bracket, block and sliding pawl detailed in HLT-DDR-003; bracket and block aluminum, decided 2026-10-02 (HLT-DEC-001)

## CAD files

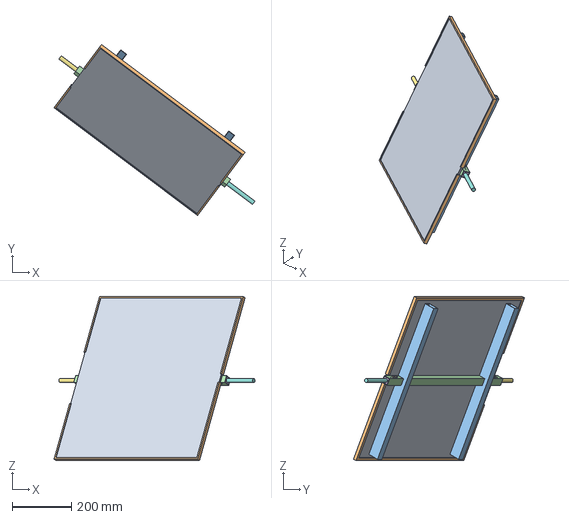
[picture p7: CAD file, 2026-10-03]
cad/step/mirror-assembly.step
677.1 x 576.4 x 553.4 mm

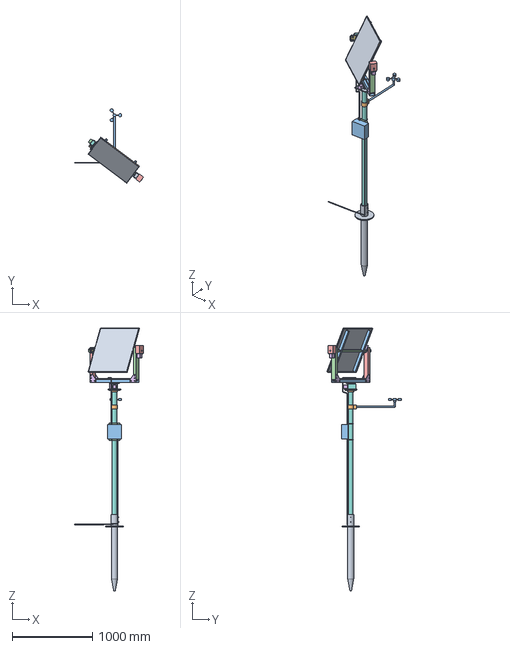
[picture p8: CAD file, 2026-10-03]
cad/step/heliolite-tracking.step
862.3 x 930.8 x 3283.5 mm

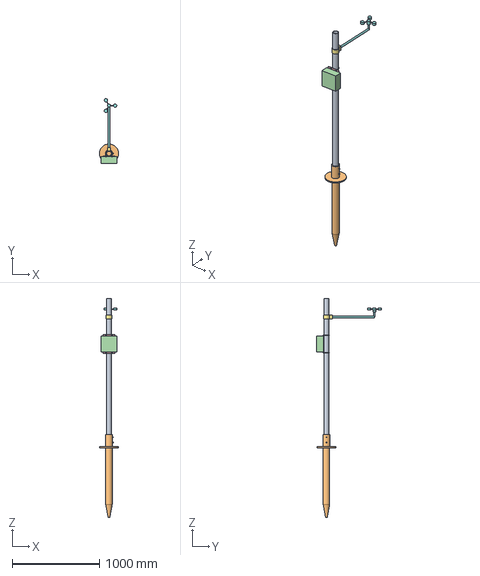
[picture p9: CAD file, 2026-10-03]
cad/step/mast-and-anchor.step
219.8 x 744.1 x 2512.0 mm

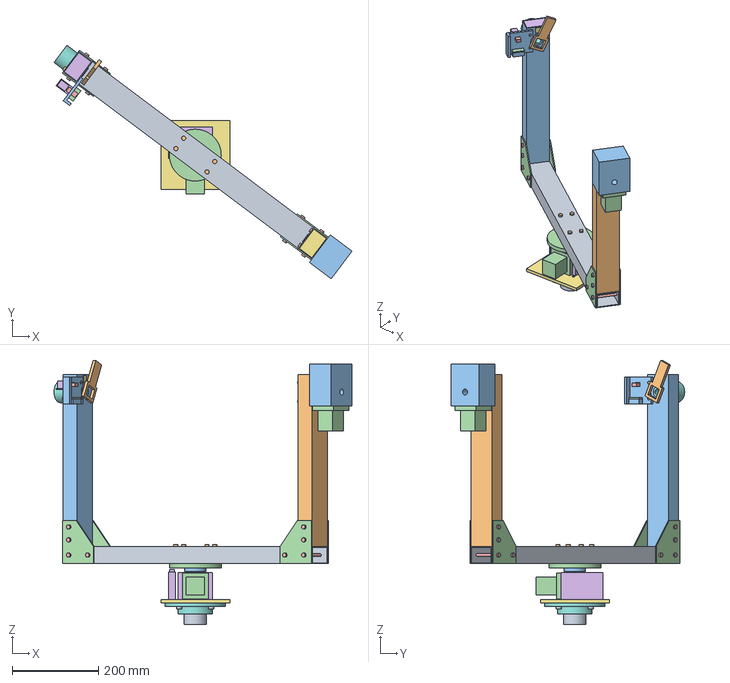
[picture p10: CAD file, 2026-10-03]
cad/step/gimbal.step
689.2 x 540.1 x 611.3 mm

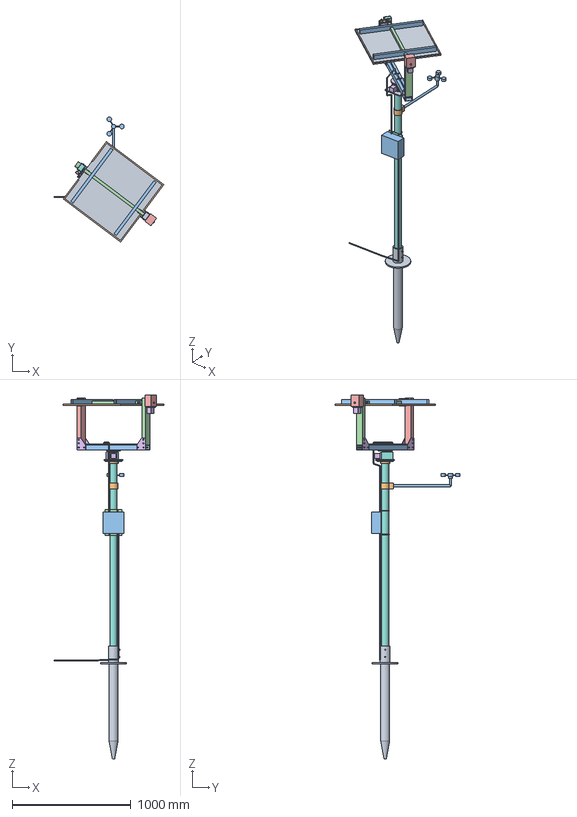
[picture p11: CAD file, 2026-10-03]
cad/step/heliolite-stowed.step
923.5 x 1054.5 x 3064.7 mm

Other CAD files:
cad/stl/gimbal.stl
cad/stl/heliolite-stowed.stl
cad/stl/heliolite-tracking.stl
cad/stl/mast-and-anchor.stl
cad/stl/mirror-assembly.stl

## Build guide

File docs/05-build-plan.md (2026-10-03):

---
doc_id: HLT-BLD-001
title: HelioLite prototype build plan
project: HelioLite
doc_type: Build plan
version: "0.4"
status: Draft
date: '2026-10-02'
author: Amish Chadha
license: CERN-OHL-S-2.0
revisions:
  - version: "0.1"
    date: '2026-10-01'
    author: Amish Chadha
    change: First build plan, with pictures by component and step; design made constructable (HLT-DDR-003)
  - version: "0.2"
    date: '2026-10-02'
    author: Amish Chadha
    change: "Decisions of 2026-10-02: head fitted in two lifts from a stable platform (step 17 and safety stop S6; steps and pictures to be redrawn); glare study and local rules added to S7"
  - version: "0.3"
    date: '2026-10-02'
    author: Amish Chadha
    change: "Section 2: the changes recorded in HLT-DDR-003 accepted by Amish on 2026-10-02"
  - version: "0.4"
    date: '2026-10-02'
    author: Amish Chadha
    change: "Decisions of 2026-10-02 carried into the plan: aluminum angle latch bracket (HLT-DWG-110 rev), EPDM edge channel (step 5), steps 10 to 17 and their pictures redrawn for the two-lift fitting from a platform, elevation Hall switch recessed in a window in the left arm (HLT-DWG-107 rev)"
---

# HelioLite prototype build plan

**Plan, not yet built.** How to build the first proof-of-concept prototype, component by component. Building and testing to it is TRL 4 work. Decisions still to be made are kept in the design decisions register ([docs/06-design-decisions.md](06-design-decisions.md)), not here.

## 1. What you are building

Figure 1. Every component, pulled apart and numbered in build order

*Figure 1. Every component pulled apart and numbered in build order. The mirror is shown face-down, as it stows, and the mast is drawn shortened.*

The prototype is one HelioLite: a 600 mm square glass mirror on a two-axis gimbal at the top of a 2 in steel pipe mast, with its elevation axis 2.2 m above the ground. The mirror is bonded to an aluminum composite panel stiffened by two rib tubes and a square torque tube; the torque tube turns in two bronze bushes in an aluminum yoke; a worm gearbox turns the mirror in elevation and a second one, on a steel cap on the mast top, turns the whole yoke in azimuth. A steel lug on the torque tube, a stop pad on an aluminum bracket and a sliding pawl hold the mirror face-down in storms. A black rubber edge channel guards the glass and panel edges. A controller box and a cup anemometer are clamped to the mast. Figure 1 shows the 26 components in the order you make or fit them. Fifteen kinds of part are made in a small workshop, each with its own making sketch: the ribs, torque tube, trunnion end blocks and stubs, stow lug, crossbar, right and left arms, gusset plates, the latch bracket with its stop block and pawl, the cap plate, the turntable disc and the controller mounting plate, and three printed parts (the bearing plugs, the spring cans and a switch post). Everything else is bought and fitted. The work is sawing, drilling, tapping, reaming and filing aluminum and steel, bonding with structural silicone, 3D printing in ASA and wiring bought electronic modules. The parts cost about USD 499 from the bill of materials.

> **Safety:** The finished mirror reflects a beam nearly as bright as the sun. Keep the glass covered with card from the moment it is bonded (step 5) until calibration, which is outside this plan, and never uncover it where the beam can reach a person, a road or the sky. The glass is heavy and its edges are sharp: two people, cut-resistant gloves and eye protection whenever it is handled. The worm drives turn slowly with high torque and the preload springs store energy even with the power off. The stow reserve holds about 360 J at 12 V. Cut metal edges are sharp: deburr everything. Printing ASA gives off fumes; print in a ventilated space. The head goes up 2.2 m in two lifts: two people on a stable platform, and a check for buried services before the ground anchor is driven.

## 2. What changed to make it buildable

The concept showed what HelioLite does; some of its parts could not be made or fixed as drawn. Each change below keeps what HelioLite does, and all of them are recorded in decision record HLT-DDR-003, accepted by Amish on 2026-10-02.

*Table 1. Changes from the concept.*

| Component | The concept had | The buildable design has | Why |
| --- | --- | --- | --- |
| Rib tubes | 25 x 20 mm ribs crossing the torque tube in the same space | 25 x 40 mm ribs, each with a square tunnel the torque tube slides through (Figure 3) | The tube still touches the panel, so the mirror's balance is unchanged; the square tunnel carries the wind moment |
| Trunnions | One 14 mm rod loose inside the square tube | An end block bolted in each tube end and a separate stub pinned into each block after the mirror is in the yoke (Figures 4 and 13) | The mirror can be fitted first and the stubs slid in from outside |
| Yoke | One printed ASA piece, 720 mm wide | Aluminum rectangular tube, a crossbar and two arms joined by gusset plates, with printed bearing plugs (Figure 11) | No common printer can print the concept's yoke; the tube frame is stiffer and lighter |
| Trunnion bearings | Bearings drawn with no housing | A flanged bronze bush through each arm and its plug; the flanges locate the tube ends (Figure 13) | Suits a slow axis; nothing to house |
| Elevation gearbox and spring | No fixings; the spring can stood off the arm | Gearbox bolted flat to the right arm; spring can screwed to the left arm, stub in its centre (Figures 13 and 14) | Both now act between the arm and the mirror |
| Azimuth stack | Turntable sat loose on the gearbox; nothing drove the spring in the mast | Keyed shaft through gearbox, cap and spring can; thrust washer, keyed hub and a 120 mm disc on top (Figure 23) | Every part fixed; stack height unchanged |
| Mast cap | "Welded or bolted to a pipe socket" | A threaded floor flange on the pipe; the cap screws to it from below (Figure 23) | No welding |
| Stow latch | Lug loose on the tube; a pawl that lifted inside the lug's swing; a bracket mostly off the arm | Lug on a square collar with a set screw; a pawl that slides sideways out of the lug's path; an aluminum angle bracket with a stop block under the pad (Figure 17) | The latch can now release; every part is held |
| Homing switches | Placed where nothing passed them | Azimuth switch on a post under a magnet in the disc; elevation switch beside a magnet in the lug (Figures 17 and 23) | Each switch now sees its magnet |
| Controller box, anemometer, mast | Floating beside the mast; mast loose in its socket | Plate and two U-bolts; a right-angle clamp; two set bolts in the socket (Figures 25 and 26) | Standard pole fixings |
| Cabling | Through the anchor flange; nothing to the turning yoke | Rerouted round the flanges, with a service loop to the crossbar (step 18) | Allows plus or minus 135 degrees of azimuth |

## 3. Making the components

Make and check each component before the assembly step that needs it. Sizes are in millimetres. "Left" and "right" are as seen standing in front of the mirror, looking at the glass: the right arm carries the elevation drive and the left arm carries the stow latch. Workshop tolerance is 0.5 mm unless a step says otherwise; drawings do not carry tolerances before TRL 4.

### 3.1 Rib tubes (make 2)

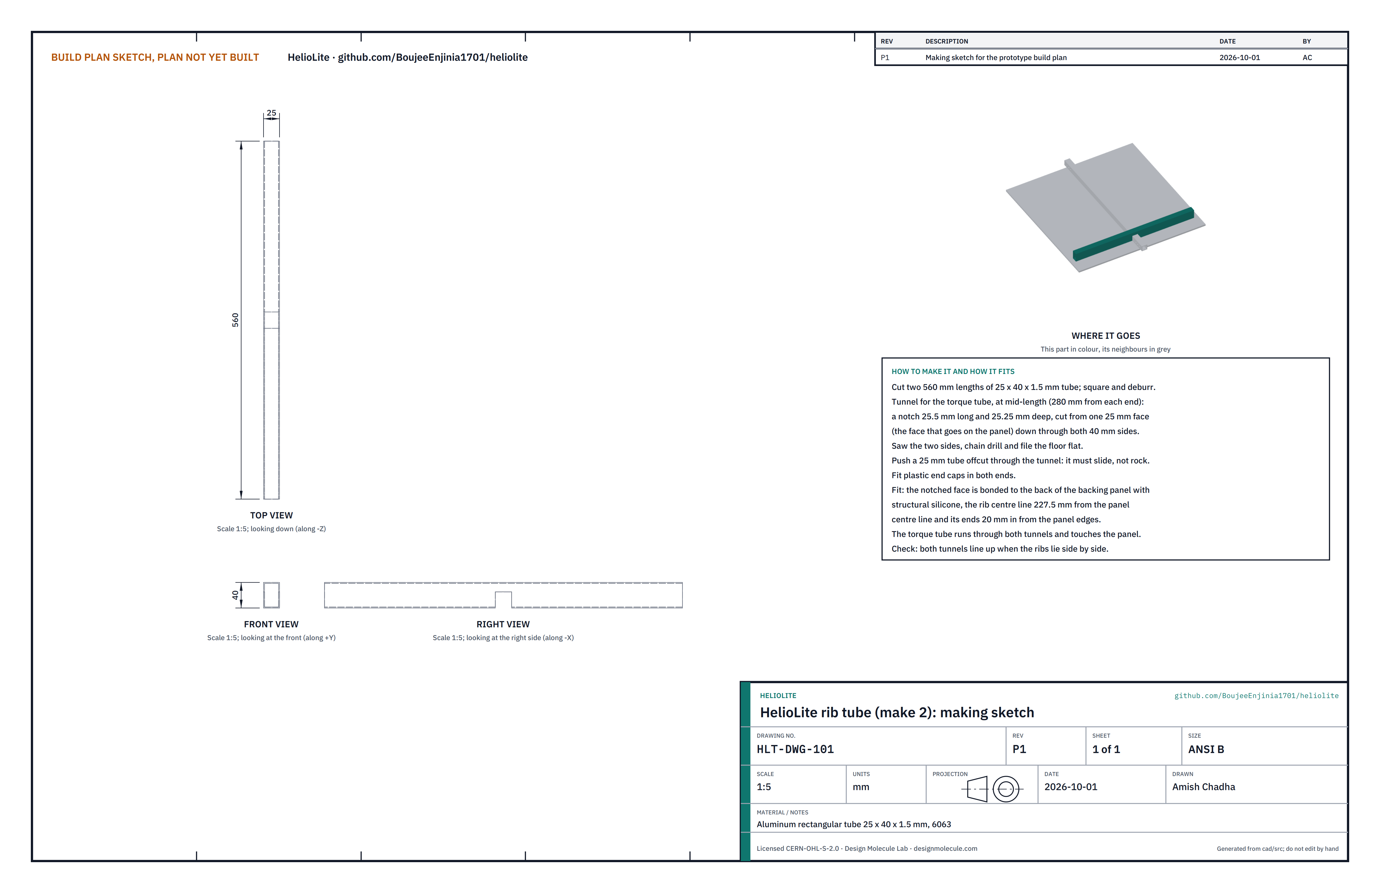
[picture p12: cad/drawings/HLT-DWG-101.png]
Figure 2. Making sketch of the rib tube


*Figure 2. Rib tube making sketch (HLT-DWG-101).*

**What it is and what it is made from.** The two stiffeners bonded across the back of the mirror panel, each with a tunnel the torque tube runs through. Aluminum rectangular tube 25 x 40 x 1.5 mm, 6063 class.

**How to make it.**

1. Cut two 560 mm lengths; square and deburr the ends.
2. Choose one 25 mm face as the panel face. At mid-length, 280 from each end, mark a notch 25.5 long.
3. Saw down both 40 mm sides 25.25 deep from the panel face, chain drill across, and file the floor of the notch flat and square.
4. Push an offcut of the 25 mm torque tube through the tunnel: it must slide without rocking.
5. Fit plastic end caps.

**How it fits the parts next to it.**

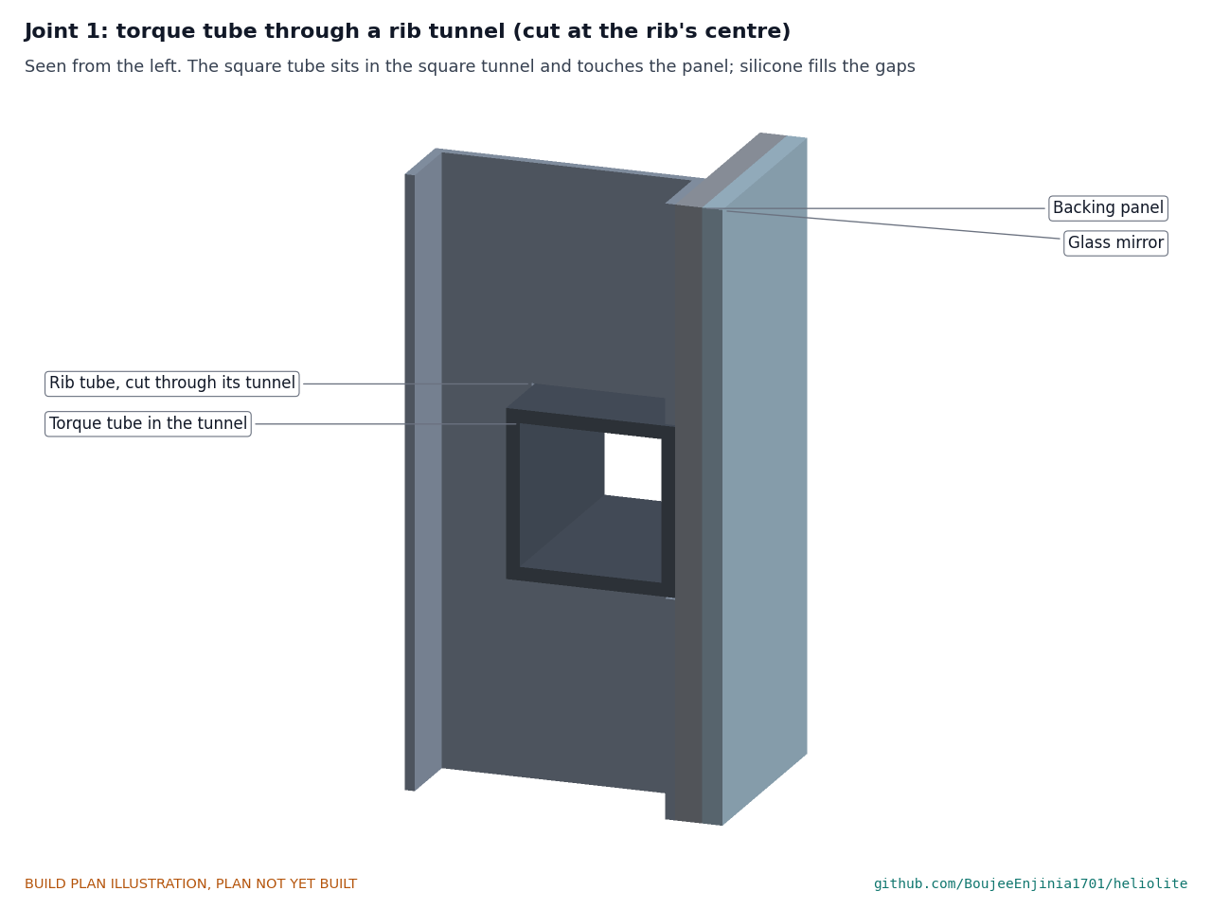
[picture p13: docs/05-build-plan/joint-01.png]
Figure 3. Joint 1: torque tube through a rib tunnel


*Figure 3. Cut through the rib's centre: the square torque tube sits in the square tunnel and touches the panel.*

The notched face is bonded flat to the back of the backing panel with structural silicone, the rib's centre line 227.5 from the panel's centre line and its ends 20 in from the panel edges. The torque tube runs through both tunnels and is bonded in them and to the panel.

**Check before moving on.** Lay the two ribs side by side: the tunnels line up.

### 3.2 Torque tube

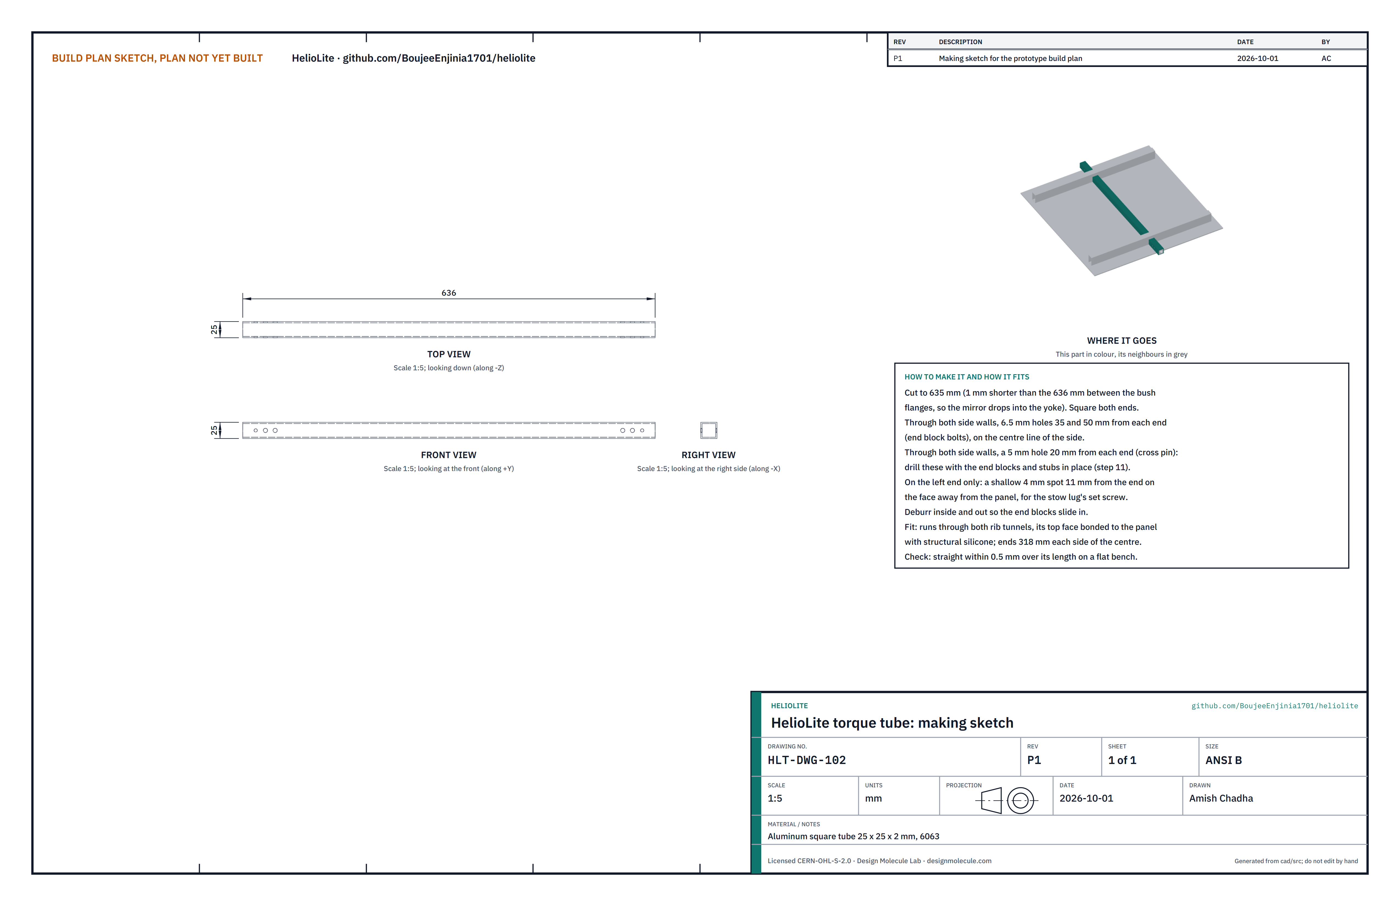
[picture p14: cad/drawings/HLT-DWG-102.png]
Figure 4. Making sketch of the torque tube


*Figure 4. Torque tube making sketch (HLT-DWG-102).*

**What it is and what it is made from.** The elevation axle of the mirror. Aluminum square tube 25 x 25 x 2 mm, 6063 class.

**How to make it.**

1. Cut to 635, 1 mm shorter than the 636 between the bush flanges, so the mirror drops into the yoke. Square both ends.
2. Through both side walls, on the centre line of the side, drill 6.5 holes 35 and 50 from each end for the end block bolts.
3. On the left end only, spot a shallow 4 mm dimple 11 from the end, on the face away from the panel, for the stow lug's set screw.
4. Deburr inside and out so the end blocks slide in. The 5 mm cross pin holes, 20 from each end, are drilled later with the stubs in place (step 17).

**How it fits the parts next to it.** It lies on the panel's centre line through both rib tunnels, its top face bonded to the panel, its ends 318 each side of the centre (Figure 3). The end blocks go inside its ends (section 3.3); the stow lug goes on its left end (section 3.4).

**Check before moving on.** Straight within 0.5 mm along its length on a flat bench.

### 3.3 Trunnion end blocks and stubs (make 2 of each)

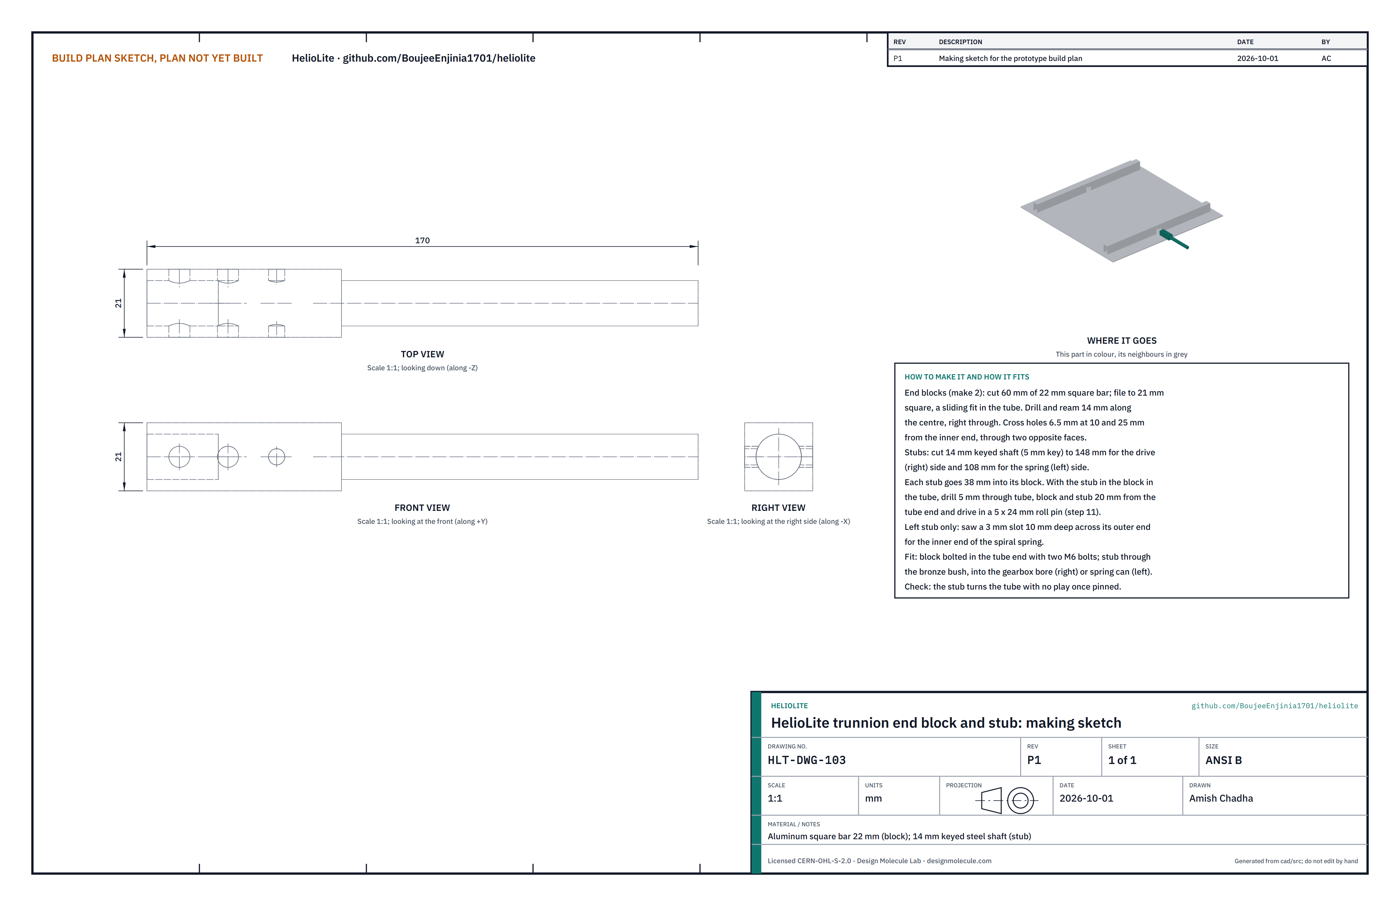
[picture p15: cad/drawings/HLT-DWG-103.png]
Figure 5. Making sketch of the trunnion end block and stub


*Figure 5. End block with its stub in place (HLT-DWG-103).*

**What it is and what it is made from.** Each end block is a short square plug in the end of the torque tube; each stub is the short shaft that carries the mirror in its bush. Blocks: aluminum square bar 22 mm. Stubs: 14 mm keyed steel shaft with a 5 mm key.

**How to make it.**

1. Blocks: cut two 60 lengths of 22 mm square bar and file each to 21 square, a sliding fit in the tube.
2. Drill and ream 14 along the centre, right through each block.
3. Drill 6.5 cross holes 10 and 25 from the block's inner end, through two opposite faces.
4. Stubs: cut the keyed shaft to 148 for the drive (right) stub and 108 for the spring (left) stub. Deburr the ends.
5. On the spring stub only, saw a 3 mm slot 10 deep across its outer end for the inner end of the spiral spring.

**How it fits the parts next to it.** Each block slides into a tube end, flush with it, and is held by two M6 bolts through tube and block with nyloc nuts (step 3). After the mirror is in the yoke on the mast, each stub slides in through its bush, 38 into the block, and a 5 x 24 mm roll pin goes through tube, block and stub 20 from the tube end (step 17). The drive stub goes in through the elevation gearbox's hollow bore, already on the arm, with its key; the spring stub ends inside the spring can (Figure 13).

**Check before moving on.** Each block slides in its tube end without forcing; each stub slides through a 14 mm bronze bush.

### 3.4 Stow lug

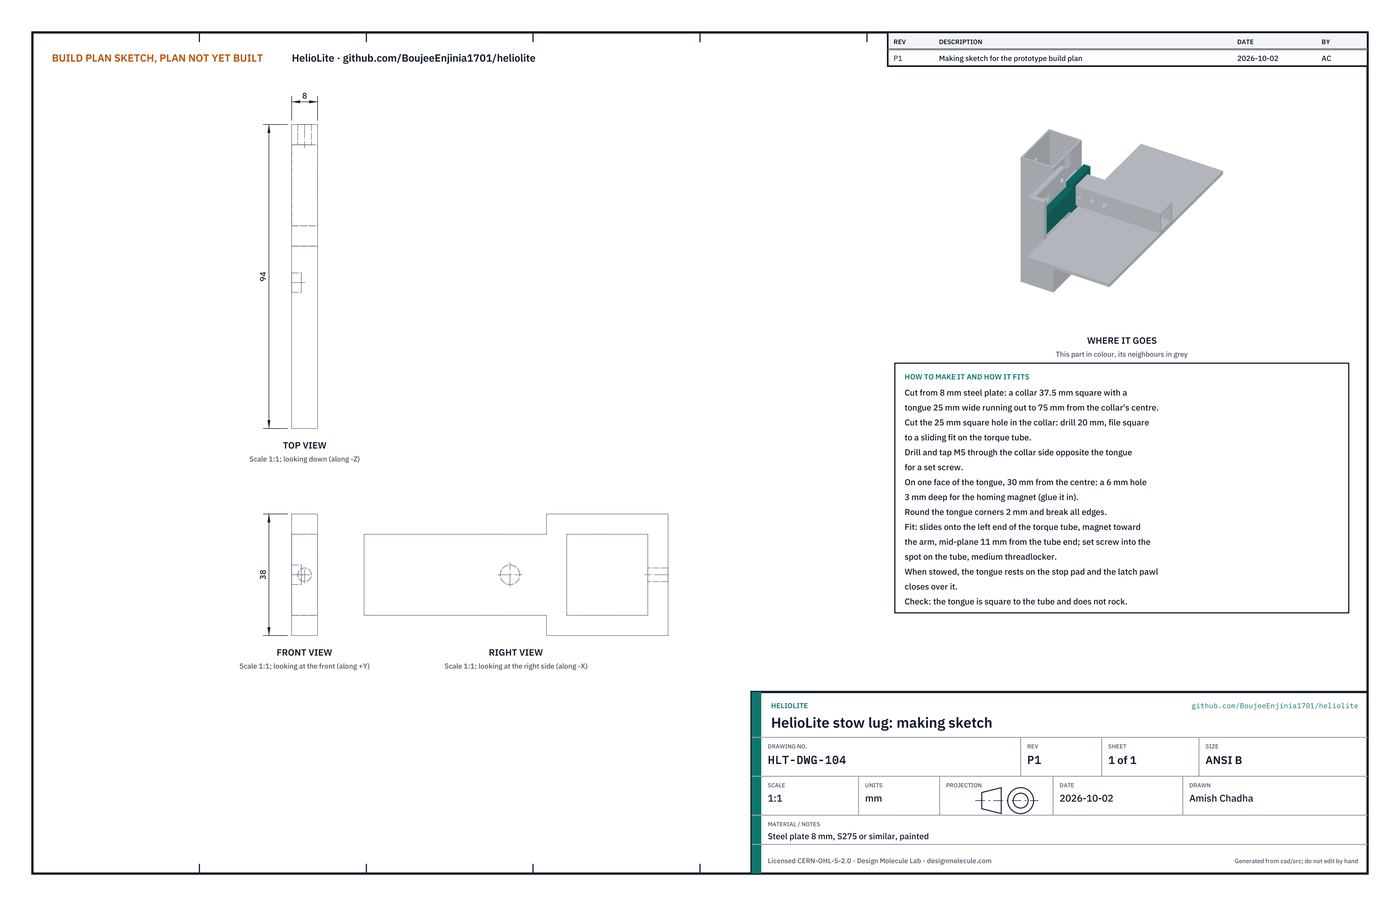
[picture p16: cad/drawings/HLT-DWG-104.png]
Figure 6. Making sketch of the stow lug


*Figure 6. Stow lug making sketch (HLT-DWG-104).*

**What it is and what it is made from.** The steel tongue that the latch traps when the mirror is stowed. Steel plate 8 mm, S275 class, painted.

**How to make it.**

1. Cut a collar 37.5 square with a tongue 25 wide running out to 75 from the collar's centre (94 overall).
2. Cut the 25 square hole in the collar: drill 20, then file square to a sliding fit on the torque tube.
3. Drill and tap M5 through the collar side opposite the tongue for a set screw.
4. On one face of the tongue, 30 from the collar's centre, drill a 6 mm hole 3 deep and glue in a 6 x 3 mm magnet for the elevation homing switch.
5. Round the tongue corners 2 mm and break all edges.

**How it fits the parts next to it.** It slides onto the left end of the torque tube, magnet toward the tube end, its mid-plane 11 from the end, with the tongue pointing across the panel as step 4 shows. The set screw goes into the dimple with medium threadlocker. When the mirror is stowed the tongue rests on the stop pad and the latch pawl closes over it (Figure 17).

**Check before moving on.** The tongue is square to the tube and the collar does not rock once the set screw is tight.

### 3.5 Glass mirror and backing panel (bought)

**What to buy.** A 600 x 600 x 3 mm silvered float glass mirror with seamed edges and a safety backing film, cut by a local glazier; 2.5 m of black EPDM U edge channel for a 7 mm edge, with a 3 mm lip over the glass and an 8 mm lip over the panel back; a 600 x 600 x 4 mm aluminum composite panel; mirror adhesive that is safe on the mirror's backing paint; structural silicone. **What to do to them.** Nothing but cleaning: the ribs and tube are bonded to the panel (steps 1 and 2) and the glass to its other face (step 5); the edge channel is cut to length and pressed on after the glass is bonded (step 5).

### 3.6 Crossbar

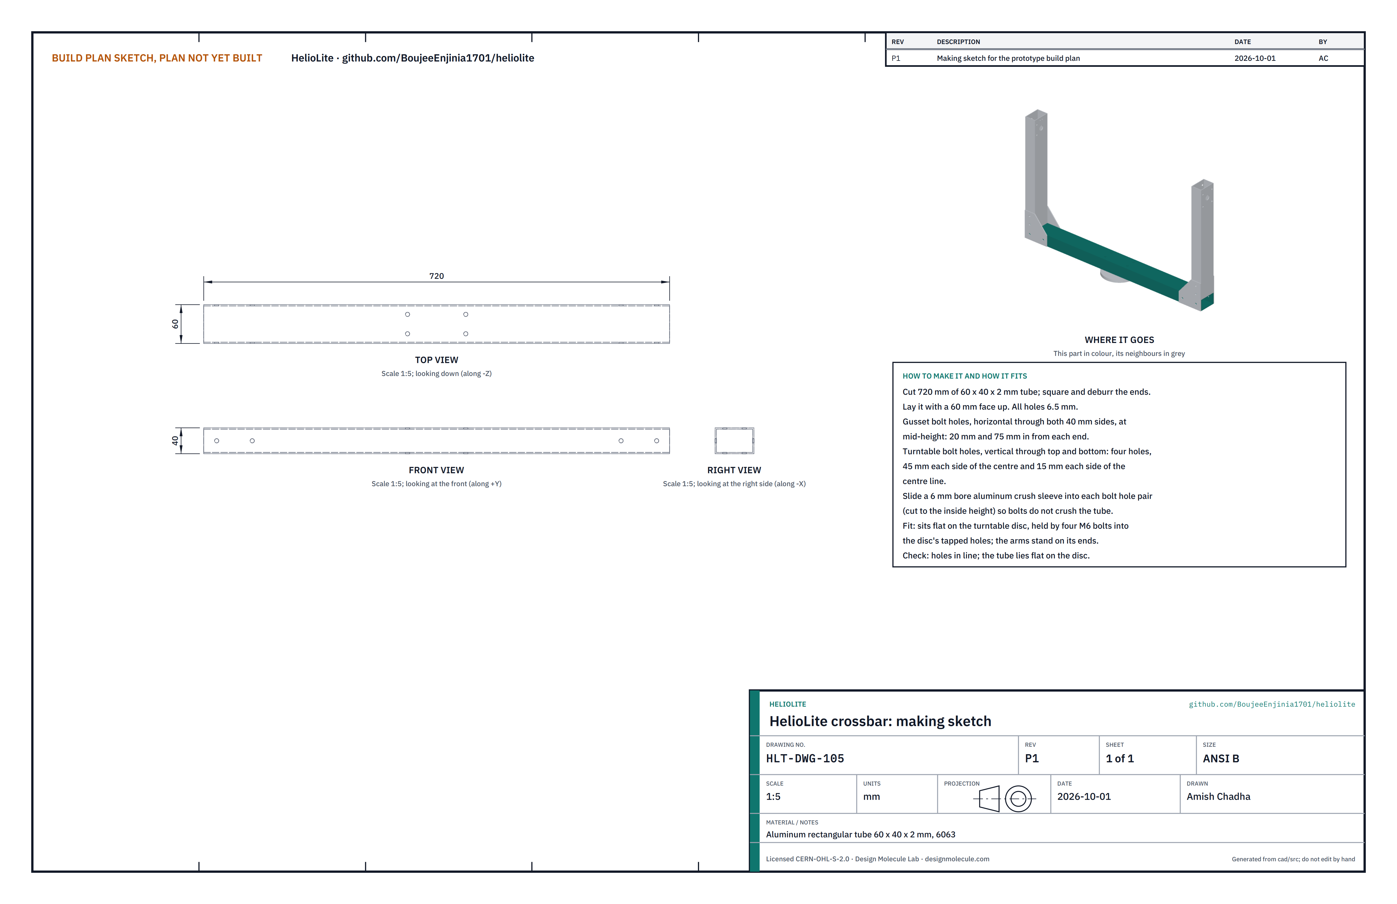
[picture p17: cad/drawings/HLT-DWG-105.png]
Figure 7. Making sketch of the crossbar


*Figure 7. Crossbar making sketch (HLT-DWG-105).*

**What it is and what it is made from.** The bottom of the yoke; it sits on the turntable disc and carries the arms on its ends. Aluminum rectangular tube 60 x 40 x 2 mm, 6063 class.

**How to make it.**

1. Cut 720 long; square and deburr the ends. Lay it with a 60 mm face up.
2. Gusset bolt holes, 6.5, horizontal through both 40 mm sides at mid-height: 20 and 75 in from each end.
3. Turntable bolt holes, 6.5, vertical through top and bottom: four, 45 each side of the centre and 15 each side of the centre line.
4. Cut aluminum crush sleeves (8 mm outside, 6.5 inside) to the inside height of the tube and slip one into each pair of holes.

**How it fits the parts next to it.** Sits flat on the turntable disc, held by four M6 bolts into the disc's tapped holes (Figure 23). The arms stand on its ends and the gusset plates clamp both (Figure 11).

**Check before moving on.** The holes line up through both walls; the tube lies flat on a bench.

### 3.7 Arms (make 2: a right and a left)

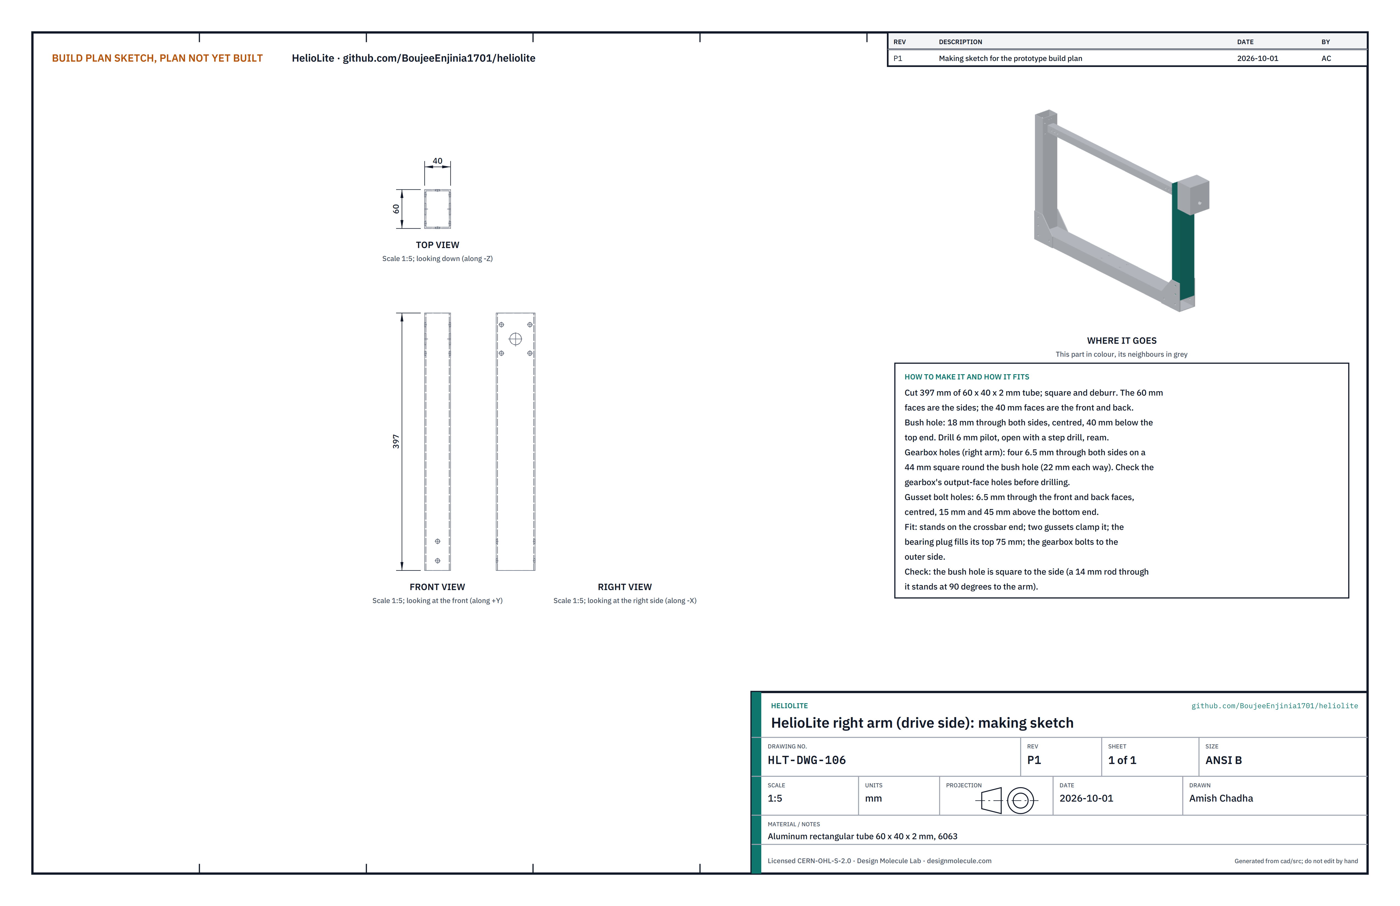
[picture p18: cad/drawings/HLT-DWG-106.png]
Figure 8. Making sketch of the right arm


*Figure 8. Right (drive side) arm making sketch (HLT-DWG-106).*

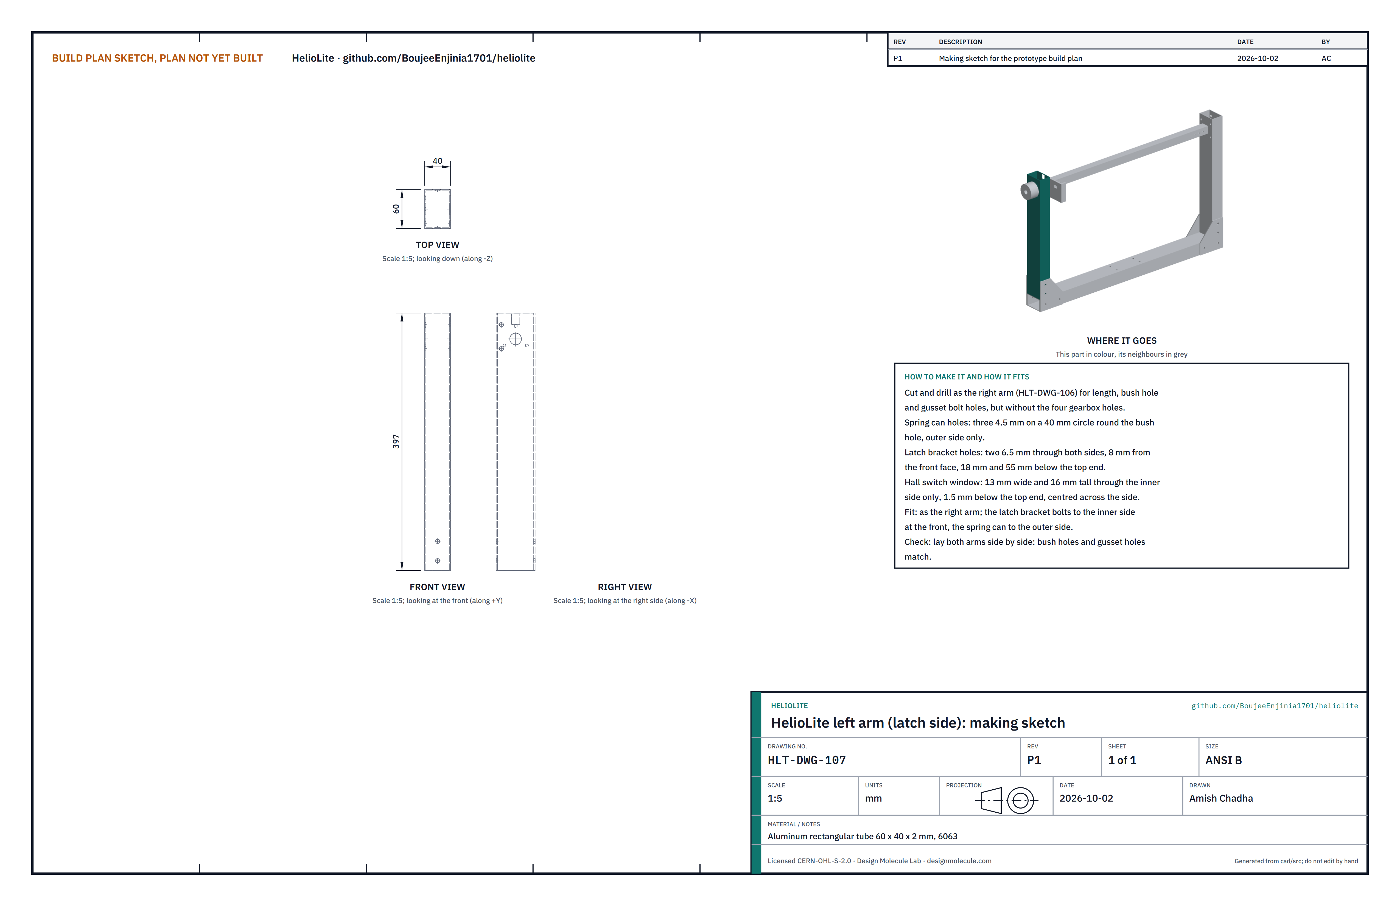
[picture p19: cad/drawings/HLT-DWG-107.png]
Figure 9. Making sketch of the left arm


*Figure 9. Left (latch side) arm making sketch (HLT-DWG-107).*

**What it is and what it is made from.** The two uprights of the yoke that carry the mirror's bushes. Aluminum rectangular tube 60 x 40 x 2 mm, 6063 class. The 60 mm faces are the sides (toward and away from the mirror); the 40 mm faces are the front and back.

**How to make it.**

1. Cut two 397 lengths; square and deburr.
2. Bush hole: 18 through both sides, centred, 40 below the top end. Drill a 6 mm pilot on a drill press, open with a step drill and ream so a 14 x 18 bush slides in.
3. Gusset bolt holes: 6.5 through the front and back faces, centred, 15 and 45 above the bottom end.
4. Right arm only: four 6.5 holes through both sides on a 44 square round the bush hole (22 each way), for the gearbox. Check the bought gearbox's output-face holes before drilling.
5. Left arm only: two 6.5 holes through both sides, 8 from the front face, 18 and 55 below the top end, for the latch bracket; three 4.5 holes in the outer side on a 40 circle round the bush hole, for the spring can; a window 13 wide and 16 tall through the inner side only, 1.5 below the top end and centred across the side, for the Hall switch.

**How it fits the parts next to it.** Each arm stands on a crossbar end, flush with it, clamped by two gusset plates (Figure 11). The bearing plug fills its top 75 and the bush passes through arm, plug and arm (Figure 13). The gearbox bolts to the right arm's outer side (Figure 14); the latch bracket to the left arm's inner side and the spring can to its outer side; the Hall switch sits in its window on the bearing plug, 1 mm proud of the arm, so the torque tube's end passes it as the mirror is lowered in.

**Check before moving on.** A 14 mm rod through the bush hole stands square to the arm; laid side by side, both arms' bush and gusset holes match.

### 3.8 Gusset plates (make 4)

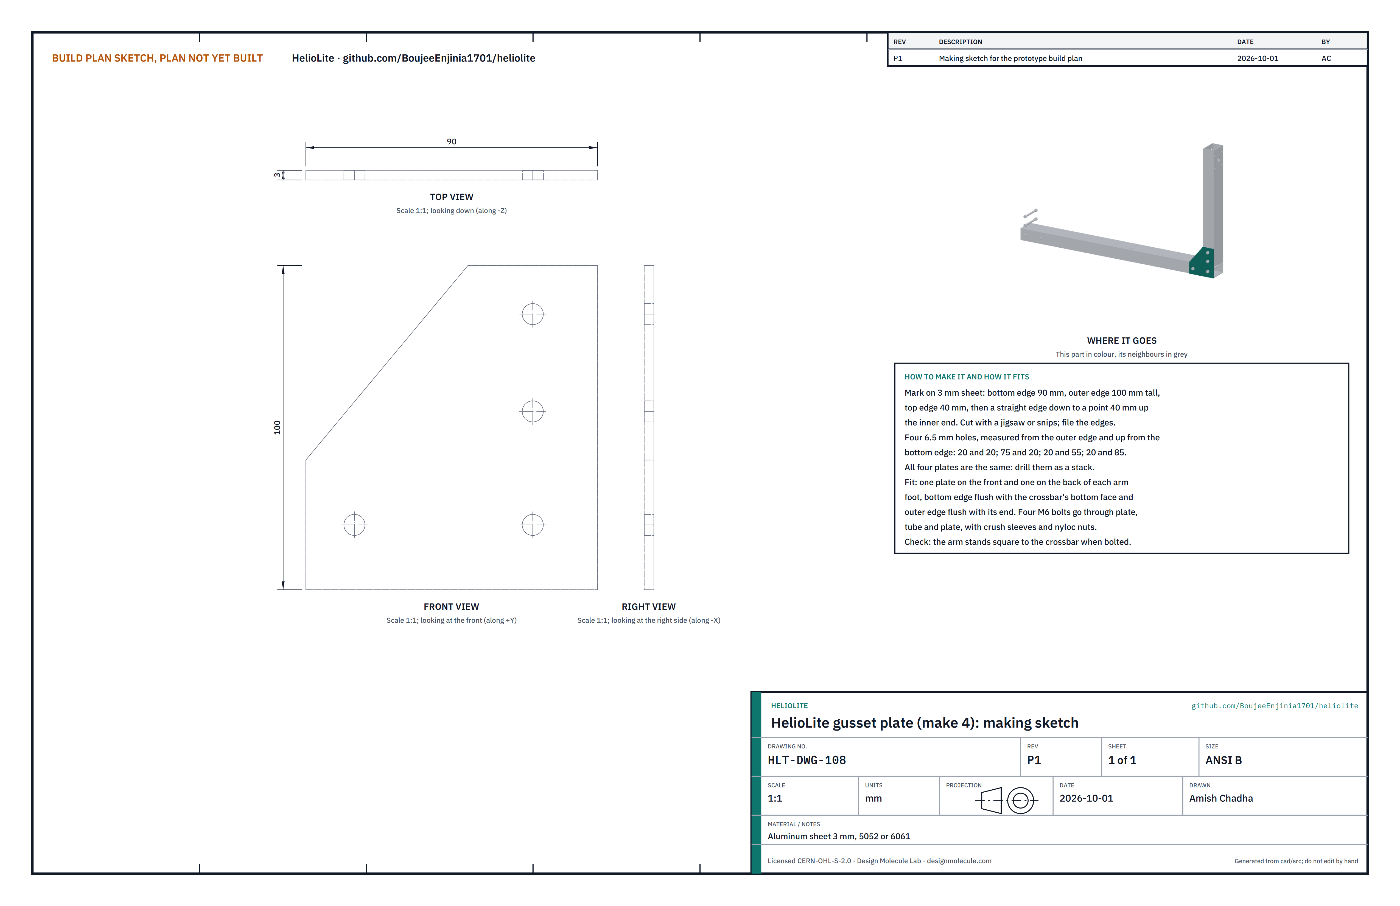
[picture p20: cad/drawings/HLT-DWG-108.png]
Figure 10. Making sketch of the gusset plate


*Figure 10. Gusset plate making sketch (HLT-DWG-108).*

**What it is and what it is made from.** The plates that make each arm-to-crossbar joint rigid. Aluminum sheet 3 mm, 5052 or 6061 class.

**How to make it.**

1. Mark the outline: bottom edge 90, outer edge 100 tall, top edge 40 in from the outer edge, then a straight edge down to a point 40 up the inner end.
2. Cut with a jigsaw or snips and file the edges straight.
3. Clamp the four blanks in a stack and drill four 6.5 holes, measured in from the outer edge and up from the bottom edge: 20 and 20; 75 and 20; 20 and 55; 20 and 85.

**How it fits the parts next to it.**

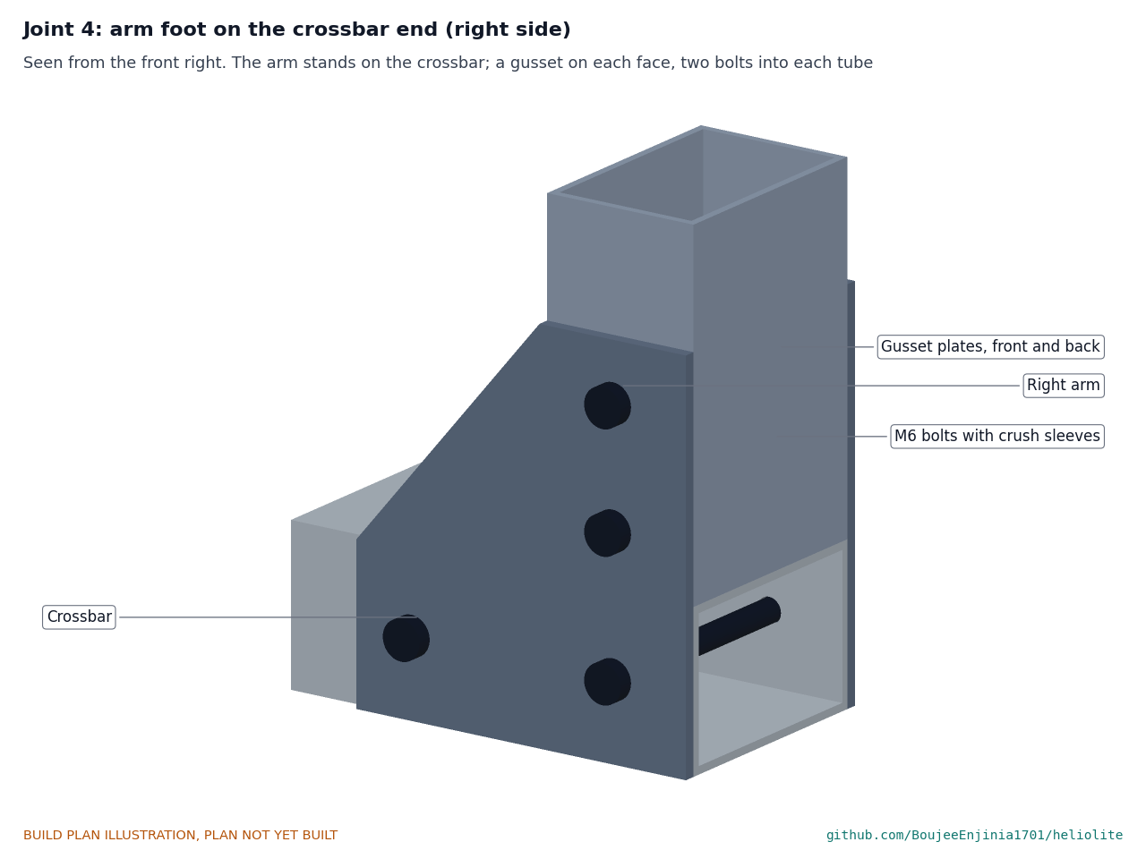
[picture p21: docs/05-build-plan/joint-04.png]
Figure 11. Joint 4: arm foot on the crossbar end


*Figure 11. A gusset on the front and one on the back of each arm foot; two bolts into the crossbar, two into the arm.*

One plate goes on the front face and one on the back face of each arm foot, bottom edge flush with the crossbar's bottom face and outer edge flush with its end. Four M6 bolts pass through plate, tube (through its crush sleeves) and plate, with nyloc nuts.

**Check before moving on.** With the four bolts tight, the arm stands square to the crossbar (check with a square both ways).

### 3.9 Bearing plugs (make 2, printed)

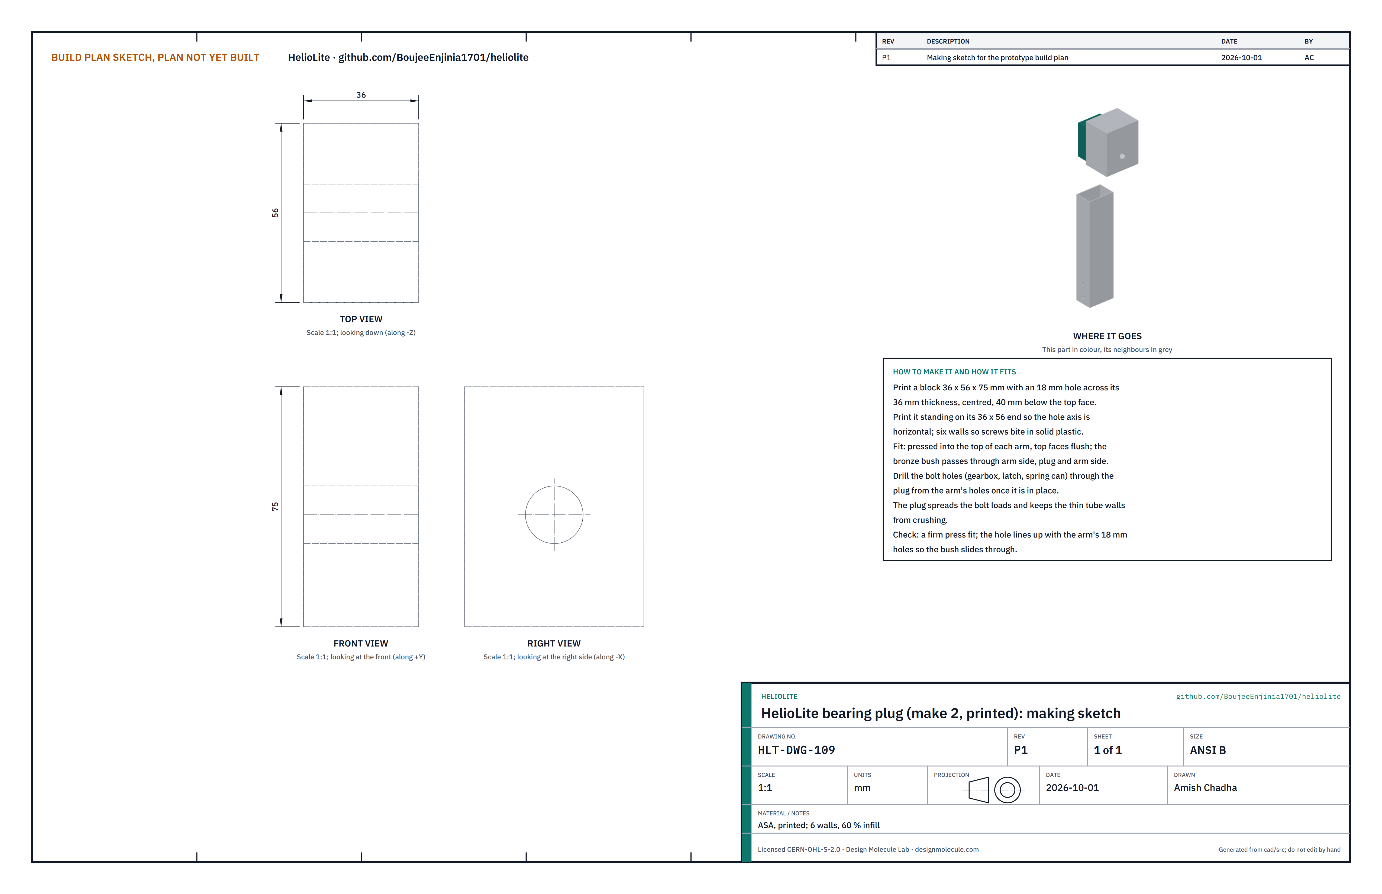
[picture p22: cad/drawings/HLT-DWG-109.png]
Figure 12. Making sketch of the bearing plug


*Figure 12. Bearing plug making sketch (HLT-DWG-109).*

**What it is and what it is made from.** A printed block that fills the top of each arm, so the bush, the gearbox bolts and the latch screws bear on solid plastic, not on the thin tube walls. ASA, six walls, 60 % infill.

**How to make it.**

1. Print a block 36 x 56 x 75 with an 18 hole across its 36 mm thickness, centred, 40 below the top face. Print it standing on its 36 x 56 end, in an enclosed printer.
2. Let it cool on the bed. Check it is a firm press fit in the arm.

**How it fits the parts next to it.**

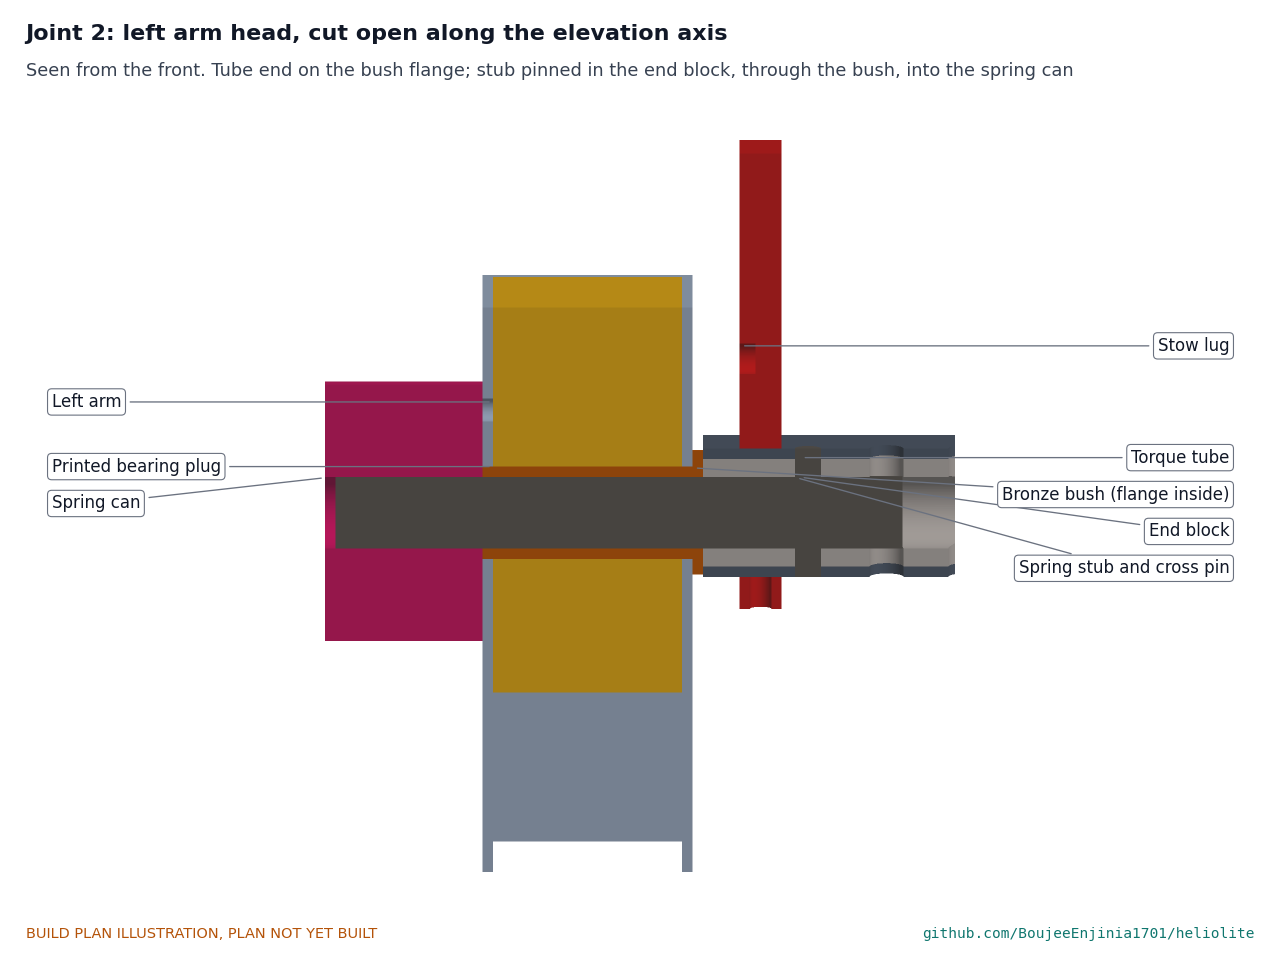
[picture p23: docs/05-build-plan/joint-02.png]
Figure 13. Joint 2: left arm head, cut open along the axis


*Figure 13. Tube end against the bush flange; the stub pinned in the end block, through the bush, into the spring can.*

Pressed into the top of each arm, flush (step 7). The bronze bush passes through arm side, plug and arm side with its flange inside, toward the mirror; the torque tube's end rests against the flange. Drill the bolt holes for the gearbox, latch and spring can through the plug from the arm's holes once it is in place.

**Check before moving on.** The bush slides through arm and plug without forcing.

### 3.10 Elevation gearbox and motor (bought)

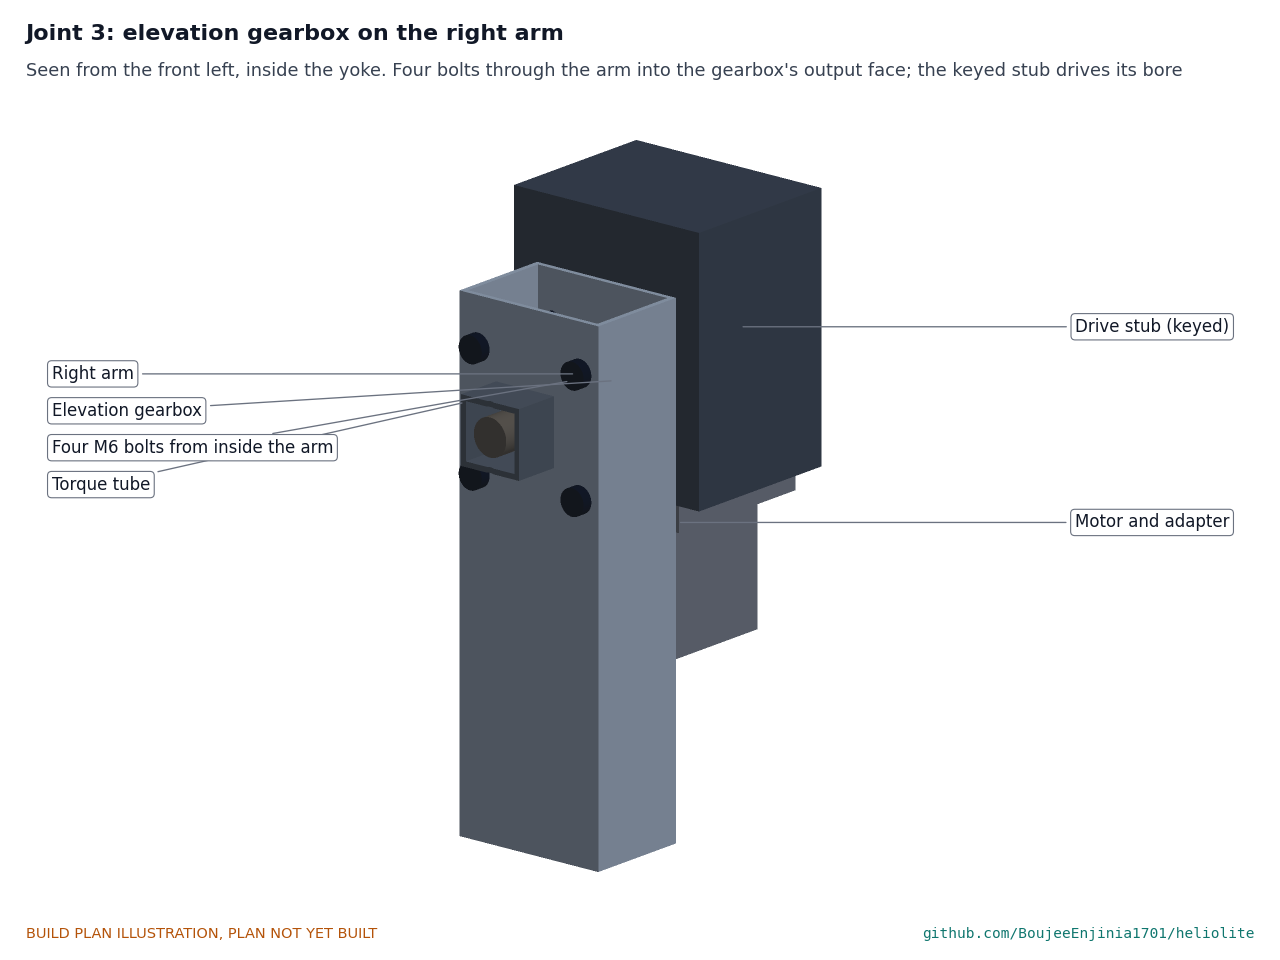
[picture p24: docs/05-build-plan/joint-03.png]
Figure 14. Joint 3: elevation gearbox on the right arm


*Figure 14. Seen from inside the yoke: four bolts through the right arm hold the gearbox's output face flat against it; the keyed drive stub runs through its hollow bore; the motor hangs below.*

**What to buy.** An NMRV030-class 50:1 worm gearbox with a 14 mm hollow bore and a NEMA17 input flange, a NEMA17 stepper (48 mm, about 0.45 N·m), the adapter plate and the 5 to 11 mm shaft sleeve; the same again for azimuth, plus that gearbox's 14 mm double output shaft with its key. **What to do to it.** Fit the motor to the gearbox with the adapter, as the maker describes. The elevation gearbox bolts to the right arm with four M6 bolts from inside the arm into its output-face holes; the azimuth gearbox screws to the cap plate (section 3.12).

### 3.11 Latch bracket, stop block and pawl

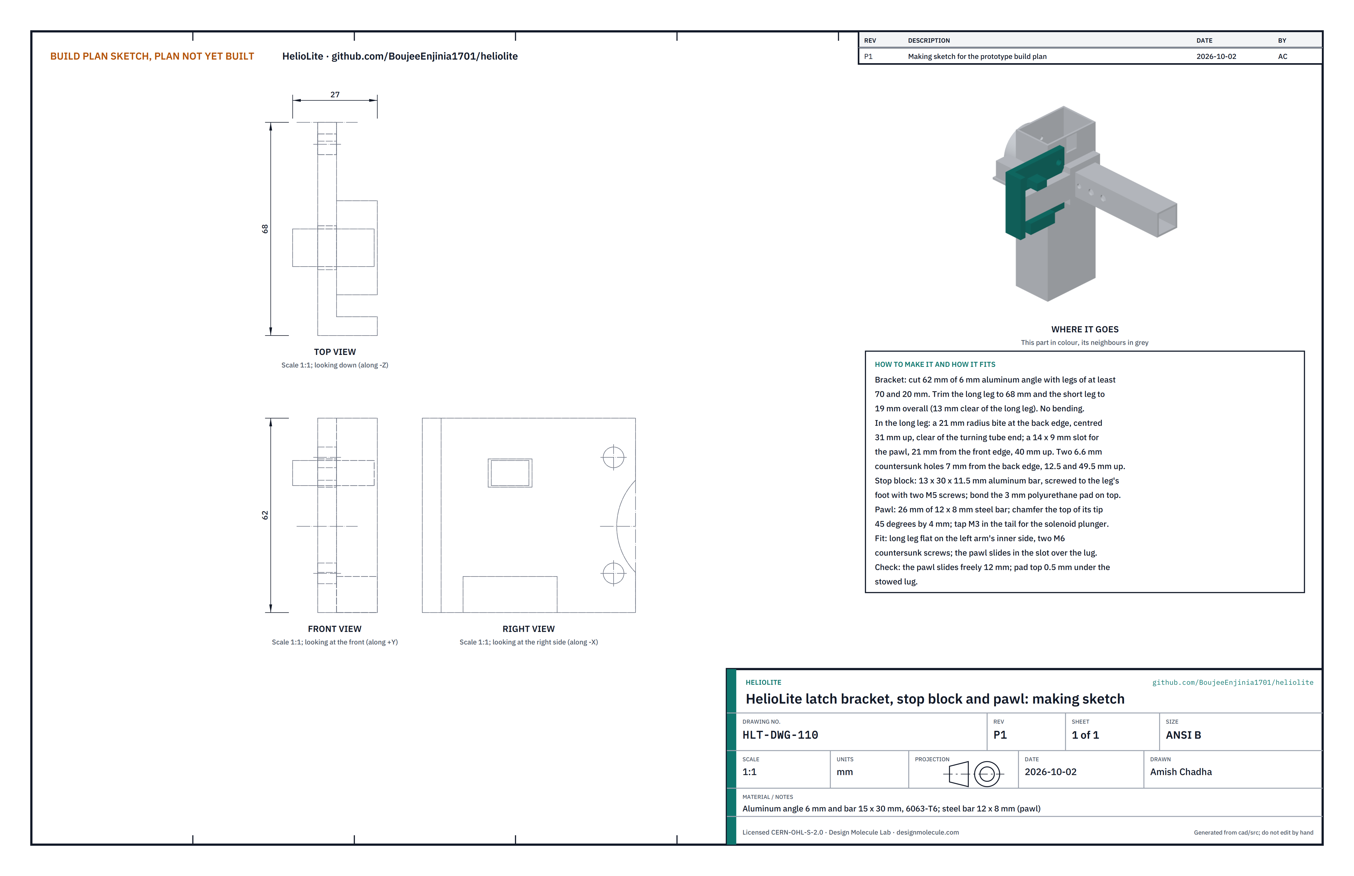
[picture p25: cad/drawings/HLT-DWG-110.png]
Figure 15. Making sketch of the latch bracket, stop block and pawl


*Figure 15. Latch bracket with its stop block and the pawl in its slot (HLT-DWG-110).*

**What it is and what it is made from.** The bracket on the left arm that carries the stop pad under the stowed lug and the pawl that closes over it. Aluminum angle 6 mm thick and aluminum bar 15 x 30, 6063-T6, left bare; steel bar 12 x 8 for the pawl, painted. The pad is 3 mm polyurethane, 90 Shore A.

**How to make it.**

1. Bracket: cut 62 of 6 mm aluminum angle with legs of at least 70 and 20. Trim the long leg to 68 and the short leg to 19 overall, so 13 stands clear of the long leg. No bending is needed.
2. In the long leg: cut a 21 radius bite out of the back edge, centred 31 up, so the turning tube end clears it; cut a 14 x 9 slot for the pawl, 21 from the front edge and 40 up; drill two 6.6 holes 7 from the back edge, 12.5 and 49.5 up, countersunk on the side away from the arm.
3. Stop block: cut 13 x 30 x 11.5 from aluminum bar; drill and tap two M5 holes in its 30 x 11.5 face; screw it to the foot of the leg from the arm side with two M5 screws. Bond the polyurethane pad on its top.
4. Pawl: cut 26 of 12 x 8 steel bar; chamfer the top edge of its tip 45 degrees by 4; tap M3 in its tail for the solenoid's plunger.

At the design storm load the pawl bends the aluminum leg to about a fifth of the metal's yield stress, and the 6 mm leg is a little stiffer than the 4 mm steel bracket it replaces, so the pad still sets how far the stowed mirror can move.

**How it fits the parts next to it.**

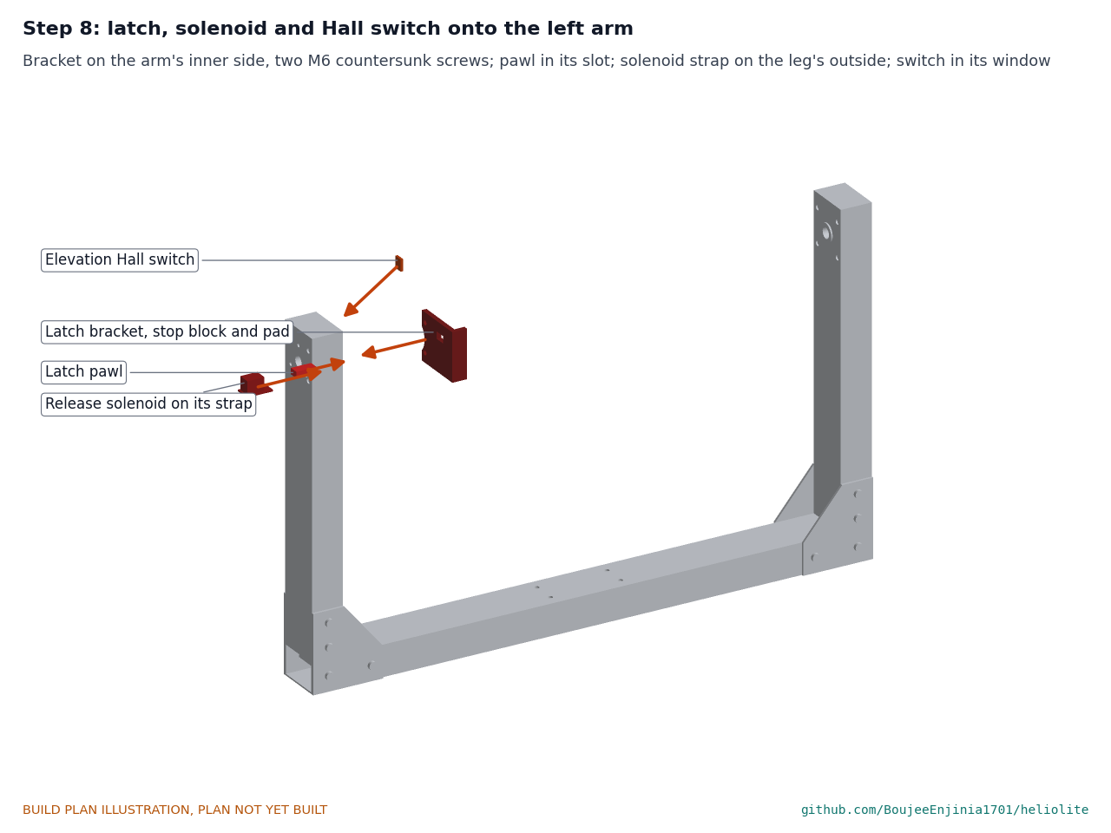
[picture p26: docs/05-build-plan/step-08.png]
Figure 16. Step 8 picture: latch, solenoid and Hall switch onto the left arm


*Figure 16. Where the bracket, pawl, solenoid and Hall switch go on the left arm.*

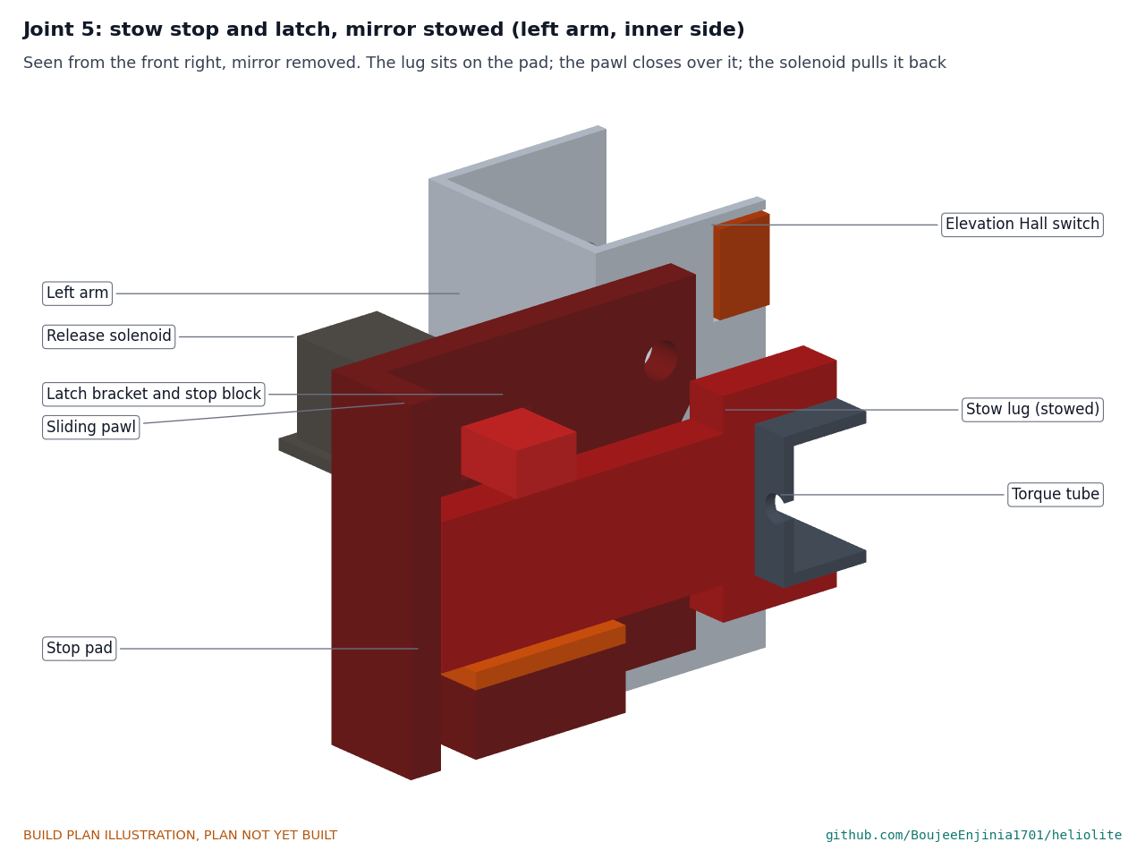
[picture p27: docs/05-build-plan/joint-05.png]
Figure 17. Joint 5: stow stop and latch, mirror stowed


*Figure 17. The lug rests on the pad; the pawl closes over it; the solenoid on the outside of the leg pulls the pawl back to release.*

The long leg lies flat on the left arm's inner side at the front, held by two M6 countersunk screws through the arm and plug with nyloc nuts on the outside. The pawl slides in its slot, its chamfer up, its tip 1 mm past the lug's far face when out and 3 mm clear of the lug when pulled back 12. The solenoid is screwed on a strap to the outside of the leg, beside the arm, its plunger screwed into the pawl's tail; its return spring pushes the pawl out. When the mirror stows, the lug's edge hits the chamfer, pushes the pawl back, passes under it and lands on the pad 0.5 below its resting place; the pawl springs out over it.

**Check before moving on.** The pawl slides freely through its full 12 stroke by hand and springs back out.

### 3.12 Mast cap plate

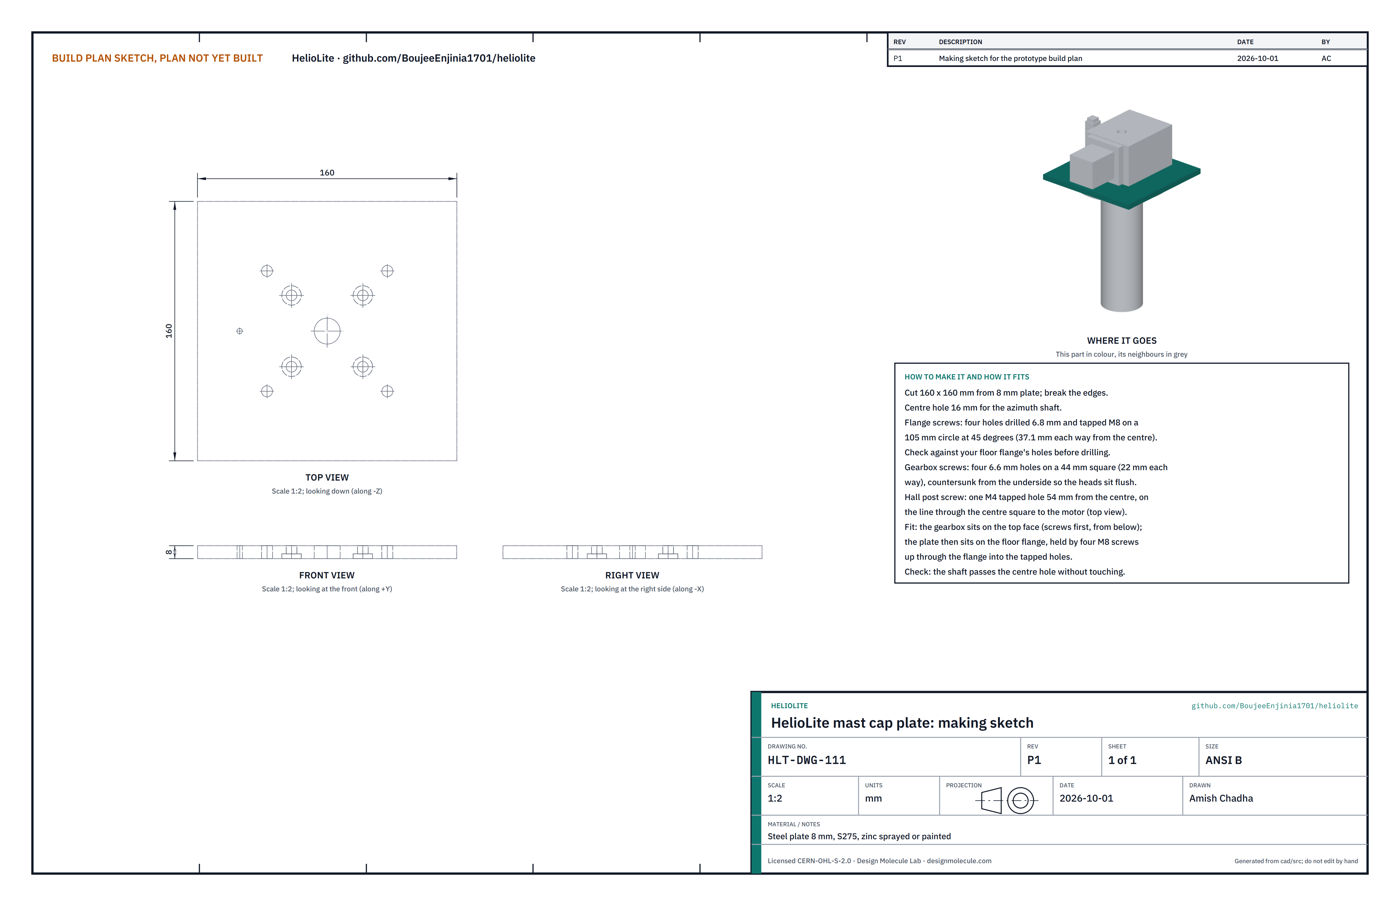
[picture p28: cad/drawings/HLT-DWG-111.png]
Figure 18. Making sketch of the mast cap plate


*Figure 18. Cap plate making sketch (HLT-DWG-111).*

**What it is and what it is made from.** The steel plate on the mast top that carries the azimuth gearbox. Steel plate 8 mm, S275 class, zinc sprayed or painted after drilling.

**How to make it.**

1. Cut 160 x 160 and break the edges.
2. Drill a 16 centre hole for the azimuth shaft.
3. Drill 6.8 and tap M8 four holes on a 105 circle at 45 degrees (37.1 each way from the centre) for the floor flange screws. Check the flange's own holes before drilling.
4. Drill four 6.6 holes on a 44 square (22 each way), countersunk from the underside, for the gearbox.
5. Drill 3.3 and tap M4 one hole 54 from the centre, on the line through the centre square to the motor's axis, on the side the drawing shows, for the Hall switch post.

**How it fits the parts next to it.** The azimuth gearbox sits on its top face, held by four countersunk M6 screws from below, fitted before the cap goes on the mast (step 14). The plate sits flat on the floor flange, held by four M8 screws up through the flange into its tapped holes (Figure 23).

**Check before moving on.** The shaft passes the centre hole without touching; the screw heads sit flush or below the underside.

### 3.13 Turntable disc

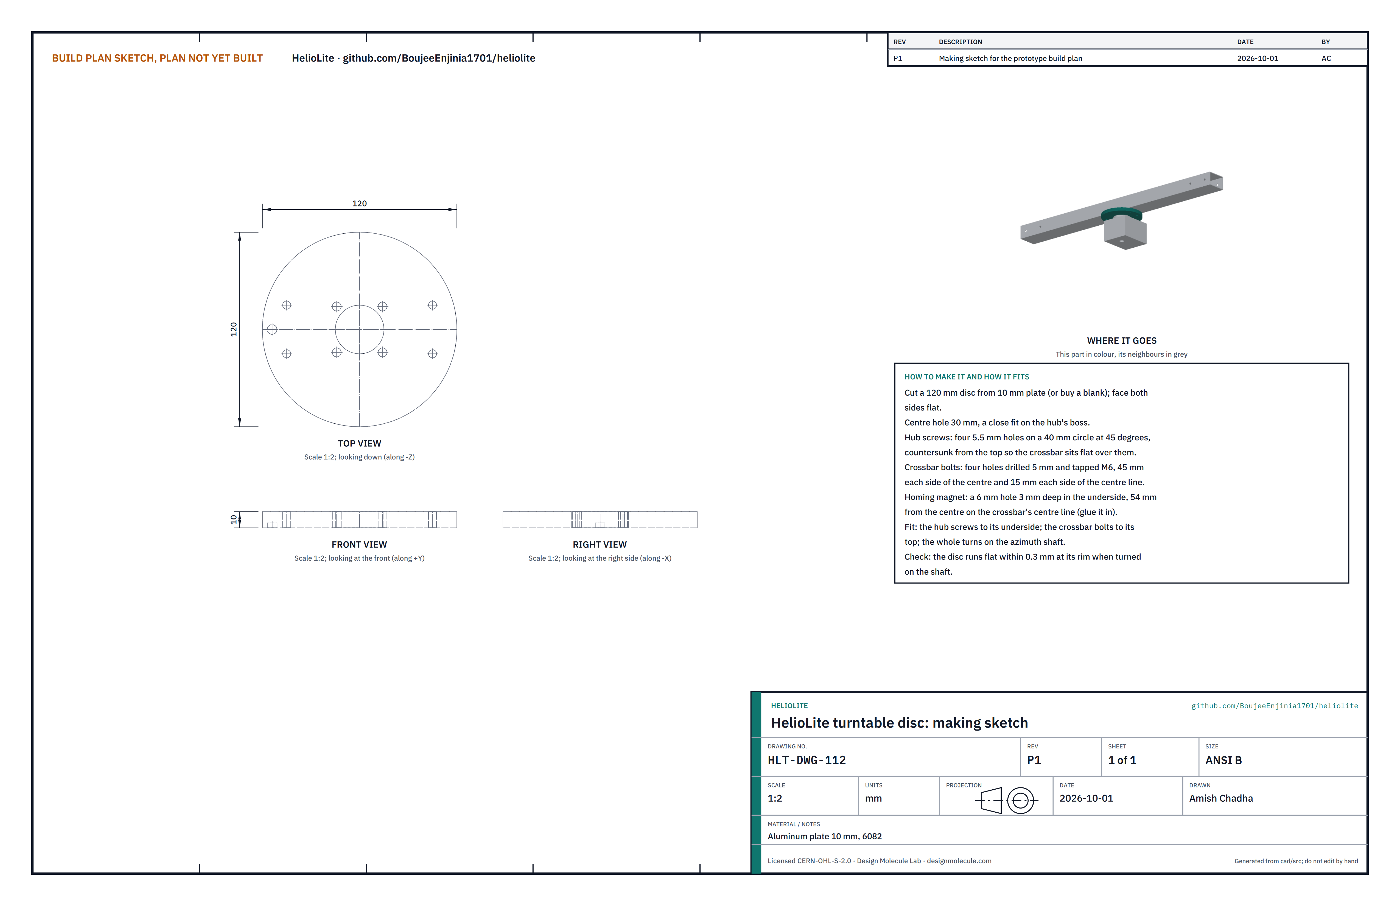
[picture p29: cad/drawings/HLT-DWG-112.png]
Figure 19. Making sketch of the turntable disc


*Figure 19. Turntable disc making sketch (HLT-DWG-112).*

**What it is and what it is made from.** The disc that joins the azimuth shaft to the yoke. Aluminum plate 10 mm, 6082 class.

**How to make it.**

1. Cut a 120 disc (or buy a blank) and face both sides flat.
2. Bore a 30 centre hole, a close fit on the hub's boss.
3. Four 5.5 holes on a 40 circle at 45 degrees, countersunk on the top, for the hub screws.
4. Drill 5 and tap M6 four holes, 45 each side of the centre and 15 each side of the centre line, for the crossbar bolts.
5. In the underside, 54 from the centre on the crossbar's centre line, drill a 6 mm hole 3 deep and glue in a magnet for the azimuth homing switch.

**How it fits the parts next to it.** The hub screws to its underside; the crossbar bolts to its top; it turns on the azimuth shaft 4 above the switch post (Figure 23).

**Check before moving on.** Turned on the shaft, the rim runs flat within 0.3 mm.

### 3.14 Spring cans (make 2, printed)

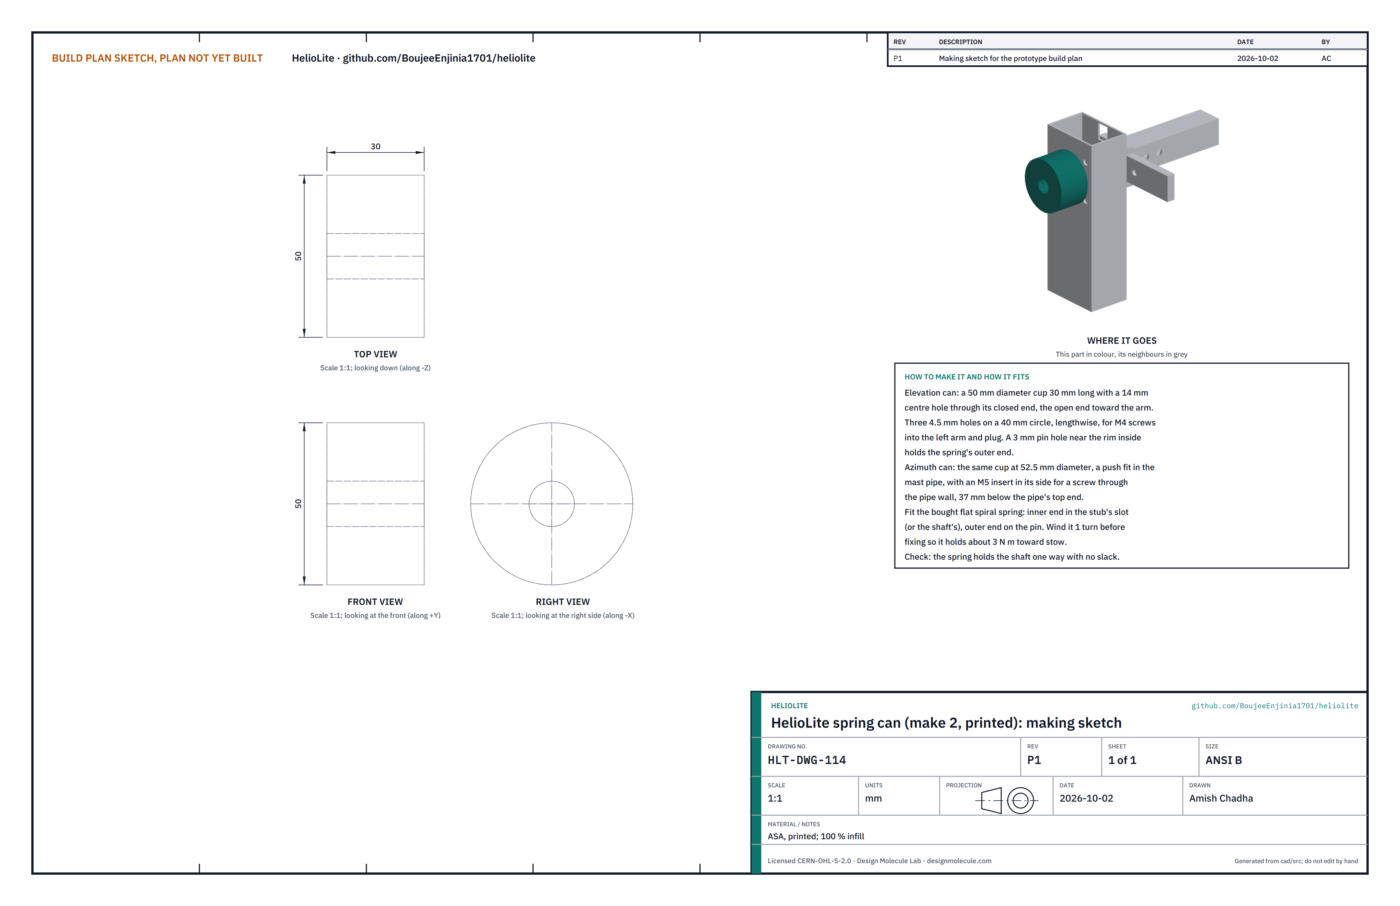
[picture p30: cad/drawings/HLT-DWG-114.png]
Figure 20. Making sketch of the spring can


*Figure 20. Spring can making sketch (HLT-DWG-114).*

**What it is and what it is made from.** A cup that holds each flat spiral preload spring. ASA, 100 % infill. The springs are bought: flat spiral (clock) springs of about 3 N·m over the axis travel.

**How to make it.**

1. Elevation can: print a 50 diameter cup 30 long, with a 14 hole through its closed end, three 4.5 holes lengthwise on a 40 circle and a 3 mm pin hole near the rim inside.
2. Azimuth can: the same cup at 52.5 diameter, a push fit in the mast pipe, with an M5 heat-set insert in its side.
3. Fit each spring: inner end in the stub's slot (or the shaft's), outer end on a 3 mm steel pin in the pin hole.

**How it fits the parts next to it.** The elevation can screws to the left arm's outer side with three M4 screws into the plug, over the spring stub (step 17). The azimuth can sits in the mast pipe on the shaft's lower end, held by an M5 screw through the pipe wall 37 below the pipe's top (step 14). Each spring is wound 1 turn before fixing so it holds about 3 N·m, the elevation spring toward stow.

**Check before moving on.** The spring holds the shaft one way with no slack.

### 3.15 Azimuth Hall switch post (printed)

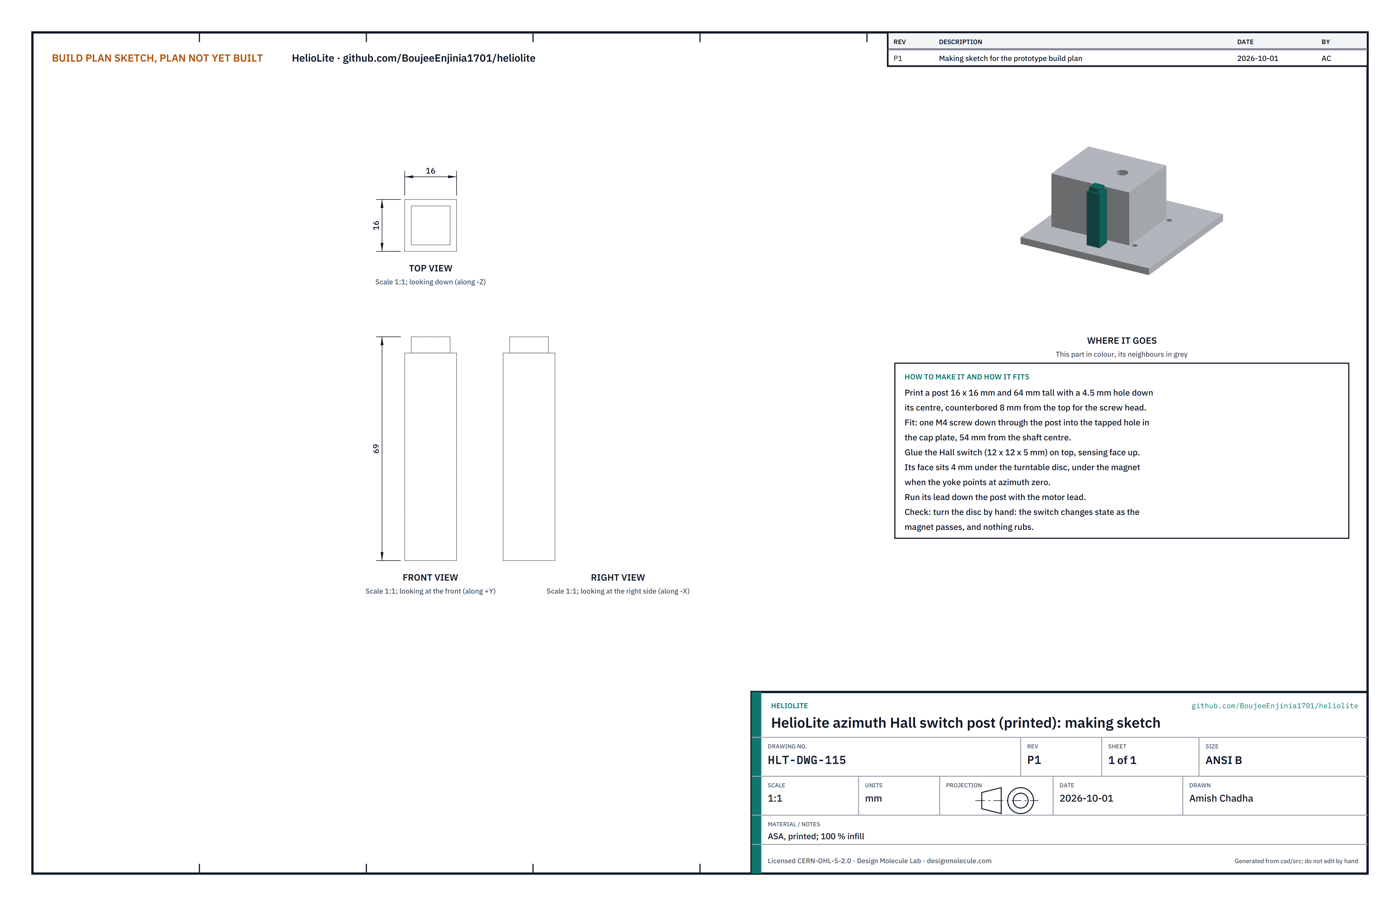
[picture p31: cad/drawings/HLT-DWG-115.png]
Figure 21. Making sketch of the Hall switch post


*Figure 21. Hall switch post making sketch (HLT-DWG-115).*

**What it is and what it is made from.** A printed post that holds the azimuth homing switch just under the turntable disc. ASA, 100 % infill.

**How to make it.** Print a 16 x 16 post 64 tall with a 4.5 hole down its centre, counterbored 8 from the top for the screw head.

**How it fits the parts next to it.** One M4 screw down through the post into the cap plate; the Hall switch glued on top, sensing face up, 4 under the disc's magnet when the yoke is at azimuth zero (Figure 23).

**Check before moving on.** Turning the disc by hand, the switch changes state as the magnet passes and nothing rubs.

### 3.16 Controller mounting plate

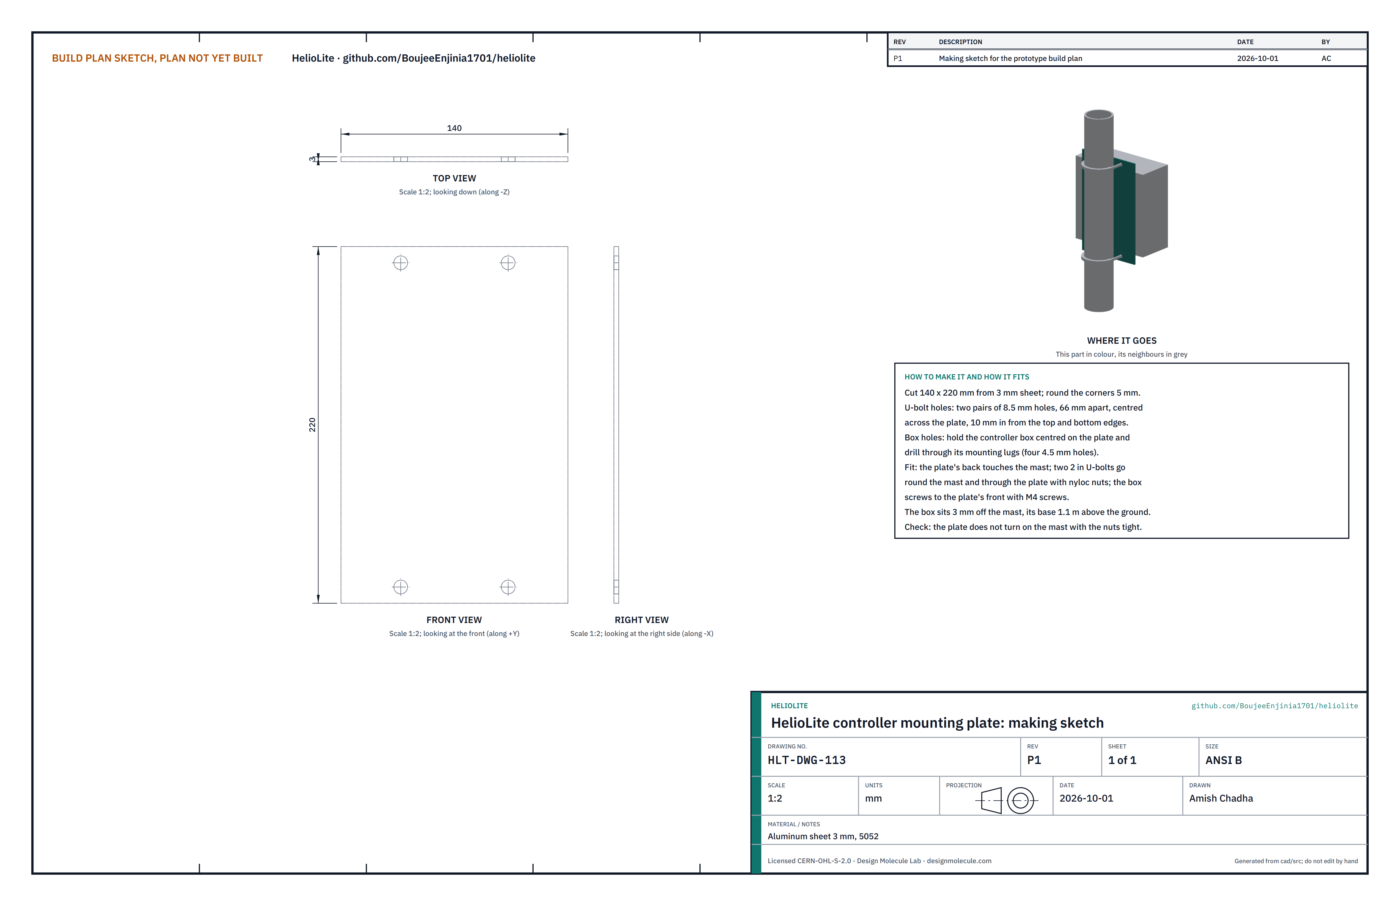
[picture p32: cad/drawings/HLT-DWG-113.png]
Figure 22. Making sketch of the controller mounting plate


*Figure 22. Controller mounting plate making sketch (HLT-DWG-113).*

**What it is and what it is made from.** The plate that holds the controller box on the mast. Aluminum sheet 3 mm, 5052 class.

**How to make it.**

1. Cut 140 x 220 and round the corners 5.
2. Two pairs of 8.5 holes for the U-bolts, 66 apart, centred across the plate, 10 in from the top and bottom edges.
3. Hold the controller box centred on the plate and drill through its mounting lugs (four 4.5 holes).

**How it fits the parts next to it.** The plate's back touches the mast; two 2 in U-bolts go round the mast and through the plate with nyloc nuts; the box screws to the plate's front (Figure 25). The box base is 1.1 m above the ground.

**Check before moving on.** With the nuts tight, the plate does not turn on the mast.

### 3.17 Mast top: floor flange, shaft, hub and thrust washer (bought)

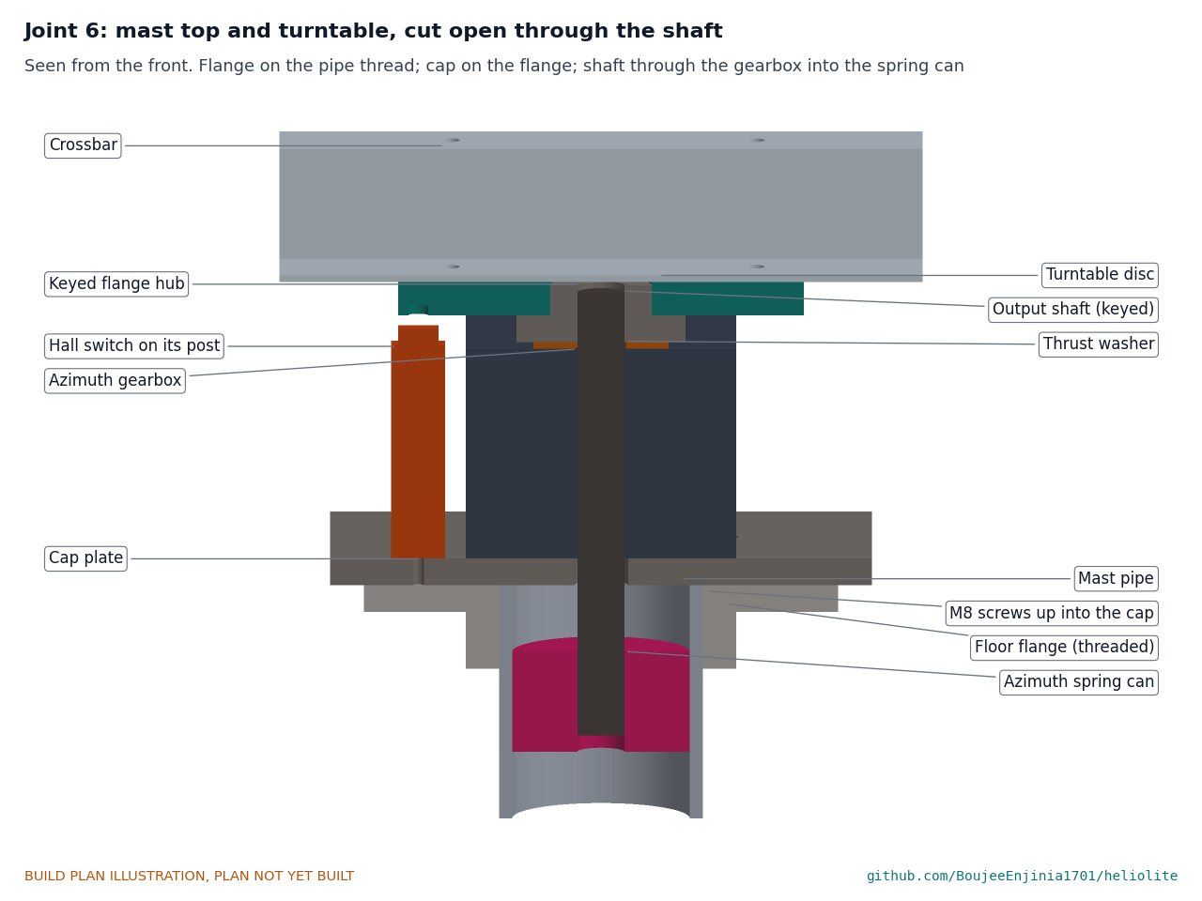
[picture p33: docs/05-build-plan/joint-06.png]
Figure 23. Joint 6: mast top and turntable, cut open


*Figure 23. Flange on the pipe thread; cap on the flange; shaft through the gearbox into the spring can; thrust washer, hub and disc on top.*

**What to buy.** A 2 in galvanized threaded floor flange and four M8 x 20 screws; the NMRV030 double output shaft (14 mm, keyed); a 14 mm keyed-bore aluminum flange hub about 50 diameter with a set screw and a 30 mm boss; a bronze thrust washer 15 x 40 x 2. **What to do to them.** The flange screws onto the pipe with thread sealant (step 13). The shaft goes through the azimuth gearbox's bore with its key and down through the cap into the spring can; the thrust washer sits on the gearbox's top face; the hub screws under the disc (step 9) and slides onto the shaft's key, its set screw tightened on the key (step 15).

### 3.18 Mast, ground anchor, controller and anemometer (bought)

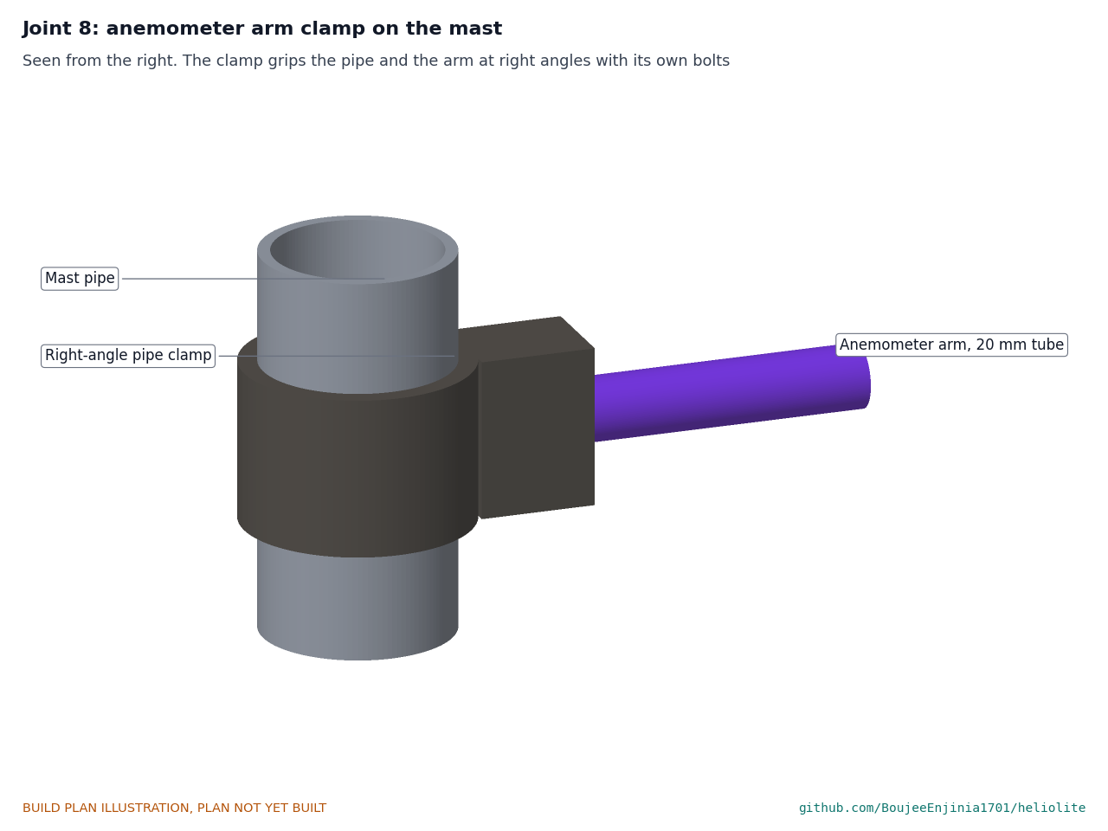
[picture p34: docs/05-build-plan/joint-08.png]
Figure 24. Joint 8: anemometer clamp


*Figure 24. The right-angle clamp grips the mast and the anemometer arm.*

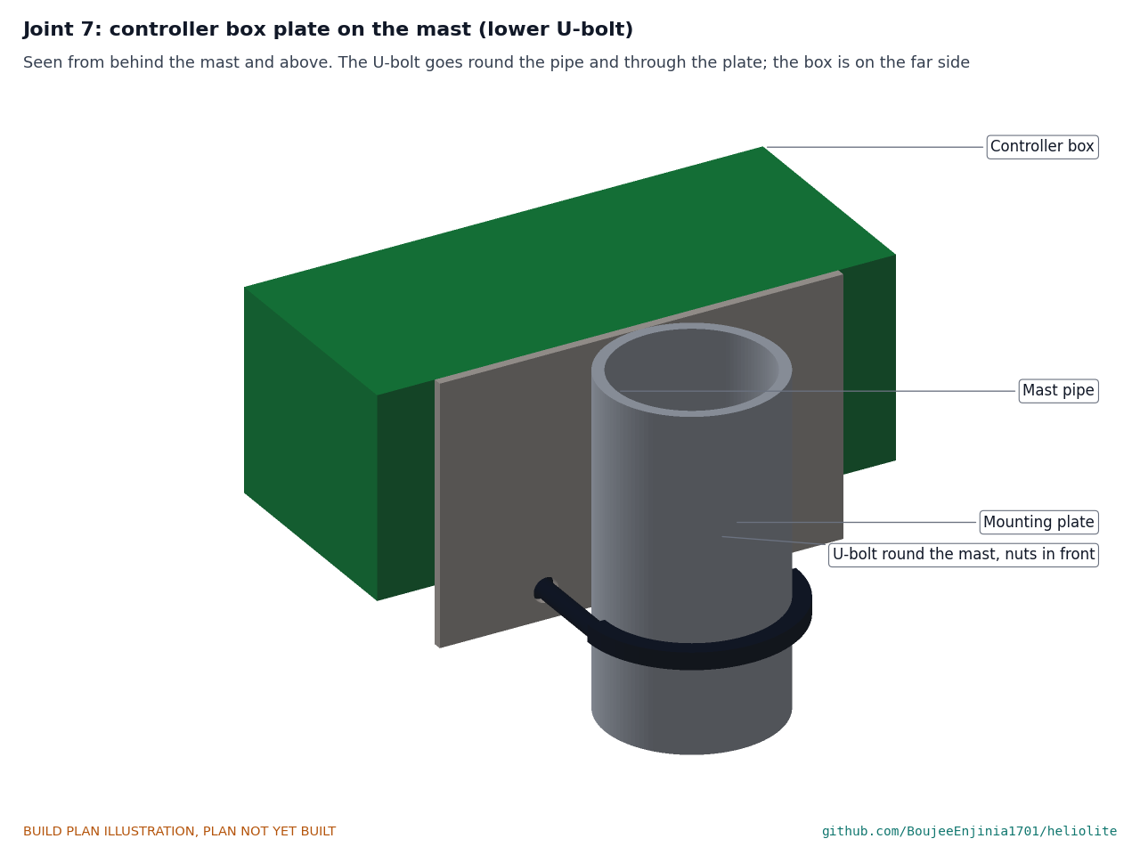
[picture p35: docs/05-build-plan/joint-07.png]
Figure 25. Joint 7: controller plate on the mast


*Figure 25. Seen from behind the mast: the U-bolt goes round the pipe and through the plate; the box is on the far side.*

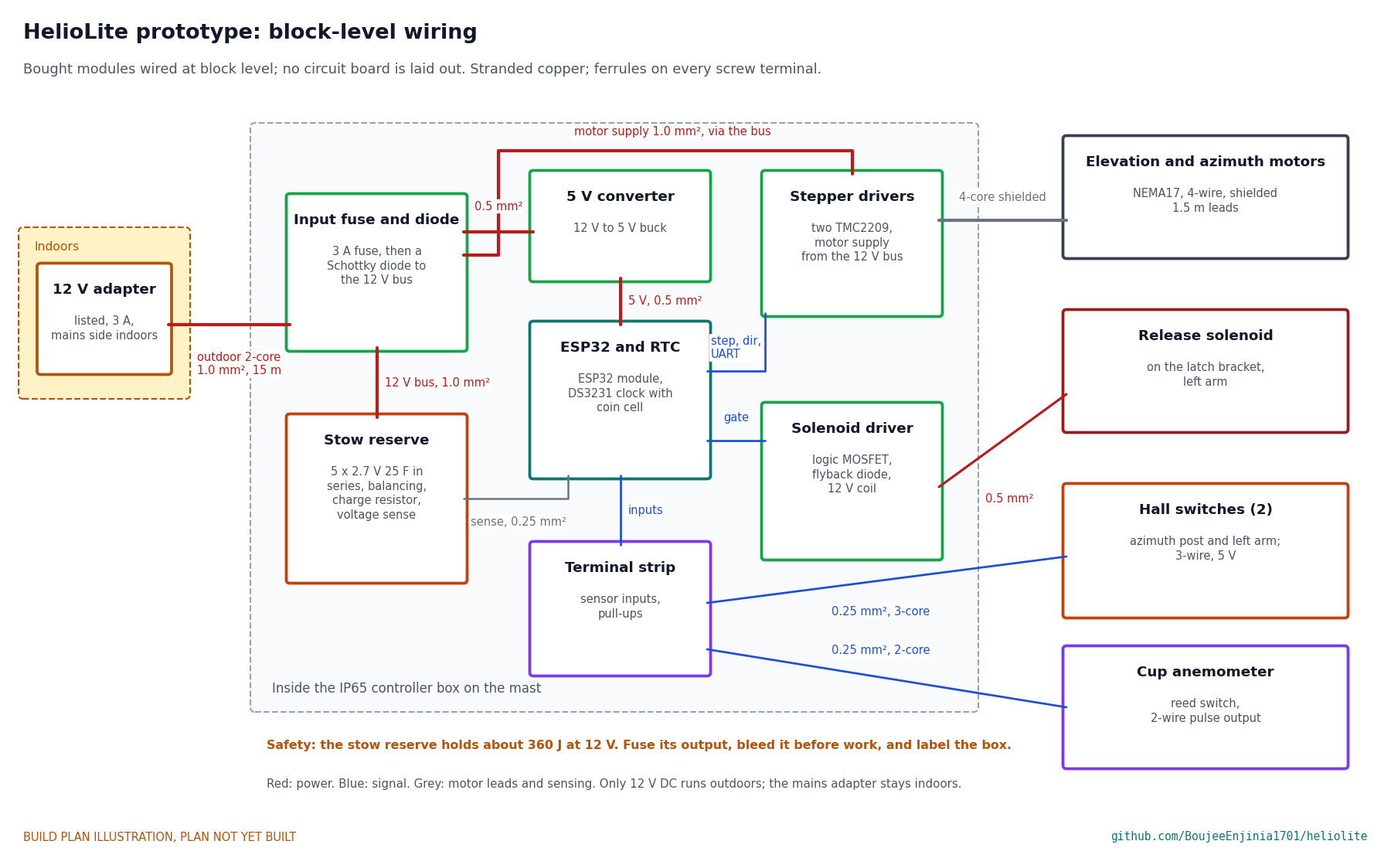
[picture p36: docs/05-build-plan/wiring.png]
Figure 26. Block-level wiring


*Figure 26. Block-level wiring with wire sizes. No circuit board is laid out at this stage; bought modules stand in.*

**What to buy.**

- **Mast (BOM line 7).** 60.3 mm (2 in schedule 40) galvanized steel pipe, 3.9 mm wall, 1.70 m, threaded at the top end.
- **Ground anchor (line 8).** A ground screw for 60 mm posts, about 800 mm long, with a socket for 60.3 mm pipe and a head flange, rated for at least 1.0 kN·m overturning; two M10 set bolts. A concrete footing with a bolted flange is the alternative.
- **Controller (lines 9 and 15).** An IP65 box 180 x 80 x 180 with glands; ESP32 module; DS3231 clock with coin cell; two TMC2209 stepper drivers; 12 V to 5 V buck converter; five 2.7 V 25 F supercapacitors with balancing resistors, input diode, charge resistor and voltage sense; a 3 A fuse; a logic-level MOSFET and flyback diode for the solenoid; two 2 in U-bolts.
- **Anemometer (line 14).** A pulse-output cup anemometer (reed switch) on a 20 mm aluminum arm 550 long, and a right-angle pipe clamp for 60.3 mm to 20 mm.
- **Switches, solenoid and springs (lines 10, 16, 17).** Two unipolar Hall switches with potted leads and two 6 x 3 mm magnets; a 12 V pull solenoid with a return spring and about 12 mm stroke; two flat spiral springs of about 3 N·m.
- **Cabling and power (lines 11, 12).** Two 1.5 m shielded 4-core motor leads; 15 m of 2-core 1.0 mm² outdoor cable; cable glands, clips and ties; a listed 12 V, 3 A indoor plug-in adapter.
- **Fixings (line 13).** Stainless: M6 bolts with nyloc nuts and crush sleeves for the yoke; M6 countersunk screws for the gearboxes and latch; M8 x 20 screws for the flange; M5 and M4 screws; 5 x 24 mm roll pins; medium threadlocker; thread sealant; anti-seize.

**What to do to them.** Wire the controller as Figure 26, with stranded copper and a ferrule on every screw terminal. Keep the stow reserve's fuse out until the first power checks (section 6). The clamp holds the anemometer arm level at 1.5 m, pointing away from the house (Figure 24).

## 4. Putting it together

In each picture the parts already fitted are grey and the part being fitted is in colour, with an arrow showing the way it goes in. Steps 1 to 10 are bench work; steps 11 to 18 are at the site. The head goes on the mast in two lifts from a stable platform: first the yoke with its drive and latch (step 15), then the mirror assembly (step 16).

### Step 1: bond the ribs to the back of the panel

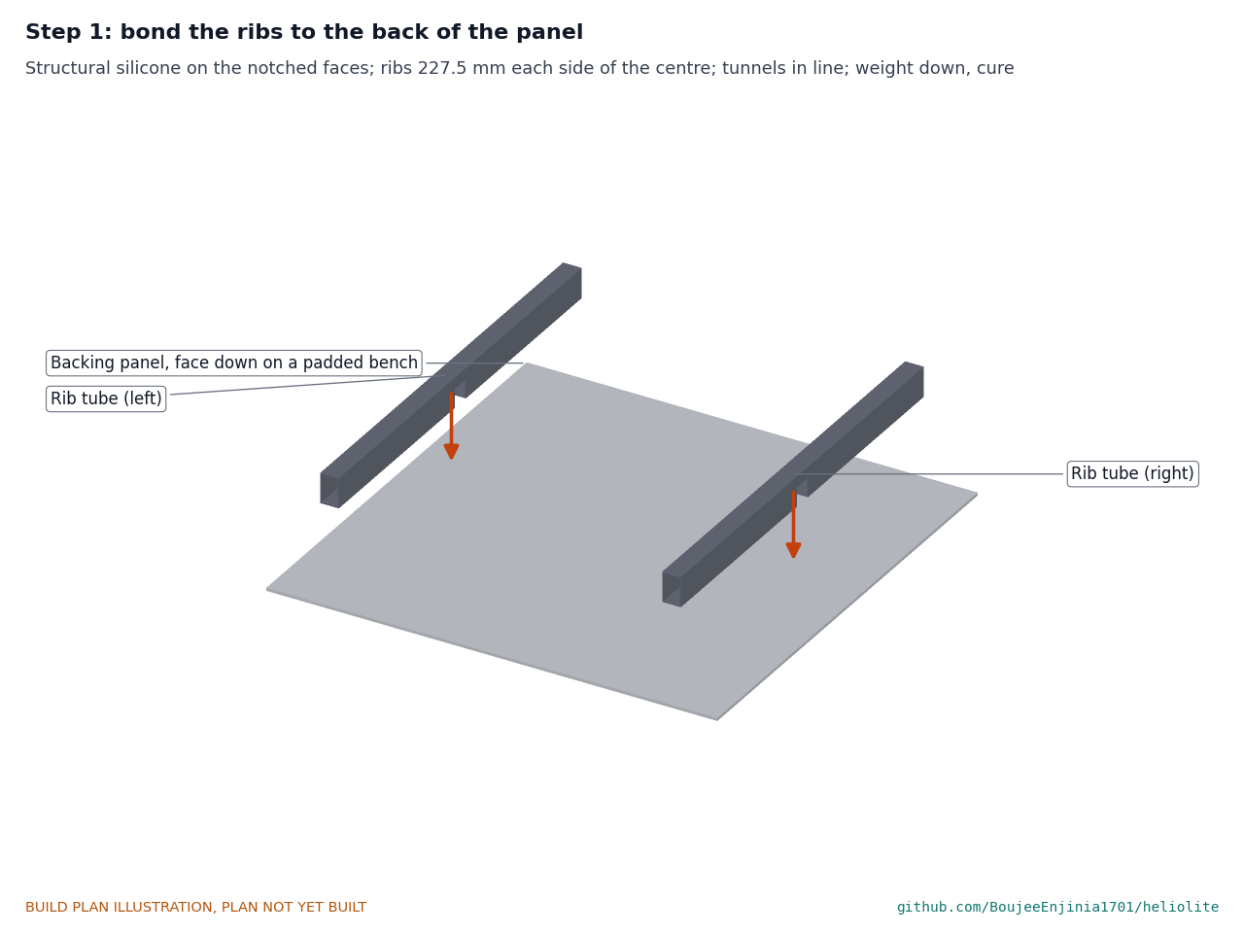
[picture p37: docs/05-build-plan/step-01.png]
Step 1


Panel face down on a padded bench. Structural silicone on each rib's notched face; ribs 227.5 each side of the centre line, ends 20 in from the edges, tunnels in line (check with a straight bar through both). Weight them down and let the silicone cure as its maker says.

### Step 2: slide the torque tube through the tunnels

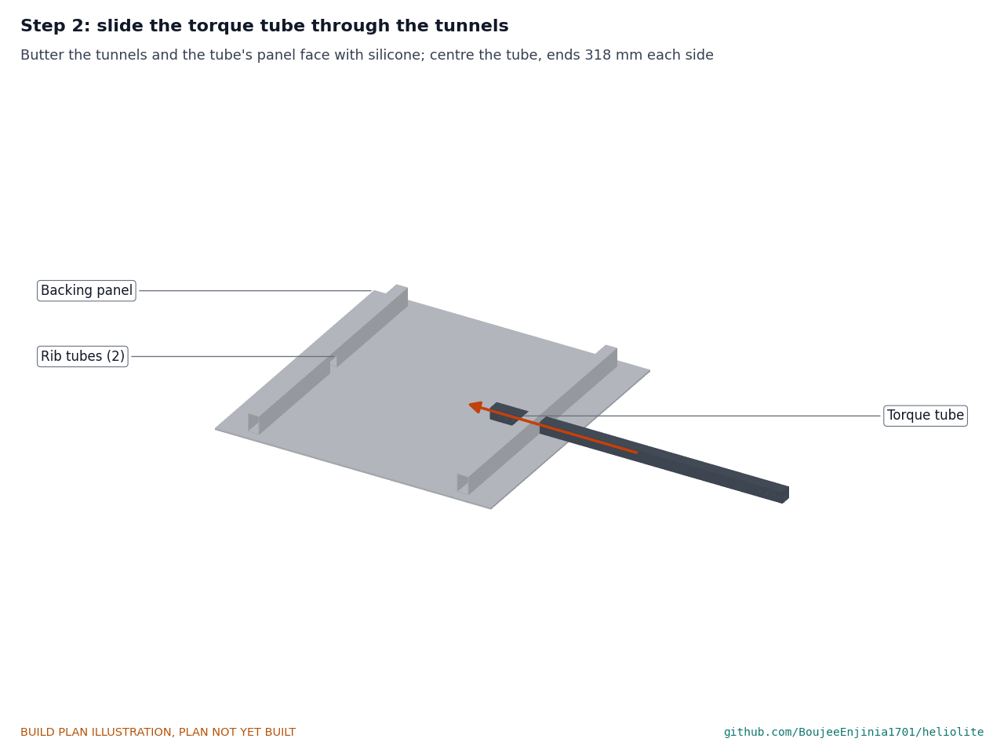
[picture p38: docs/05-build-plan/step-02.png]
Step 2


Butter the tunnels and the tube's panel face with silicone. Slide the tube through both tunnels, centred, its ends 318 each side of the centre. Wipe off the excess and let it cure.

### Step 3: end blocks into the tube ends

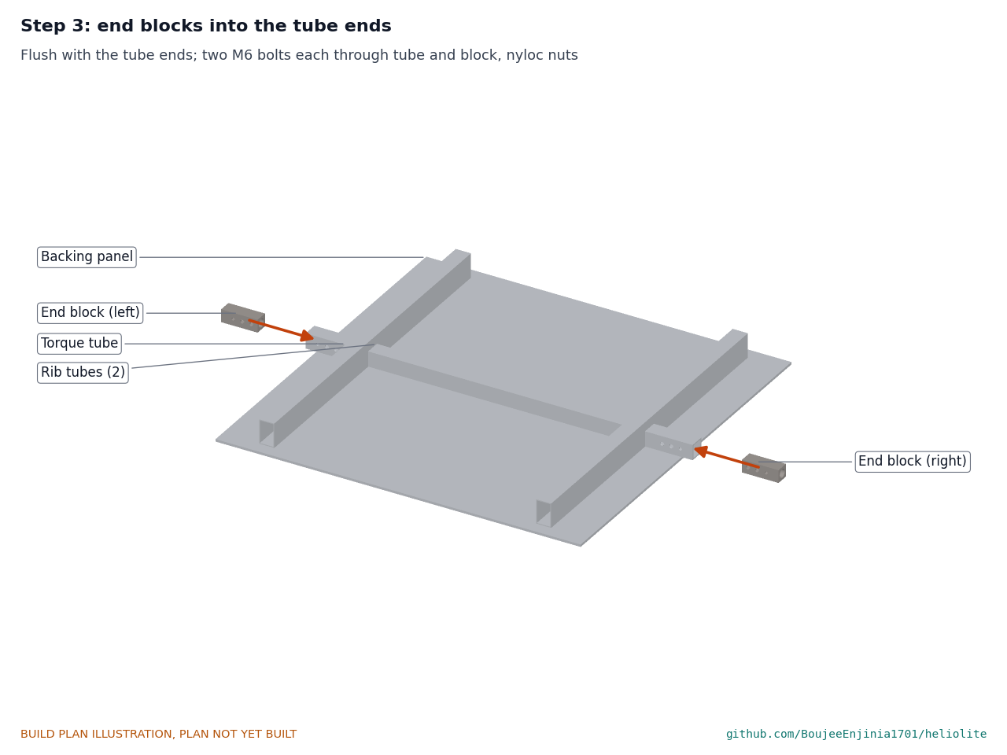
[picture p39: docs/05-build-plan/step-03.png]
Step 3


Slide a block into each end, flush. Two M6 bolts each through tube and block, nyloc nuts, snug.

### Step 4: stow lug onto the left end of the tube

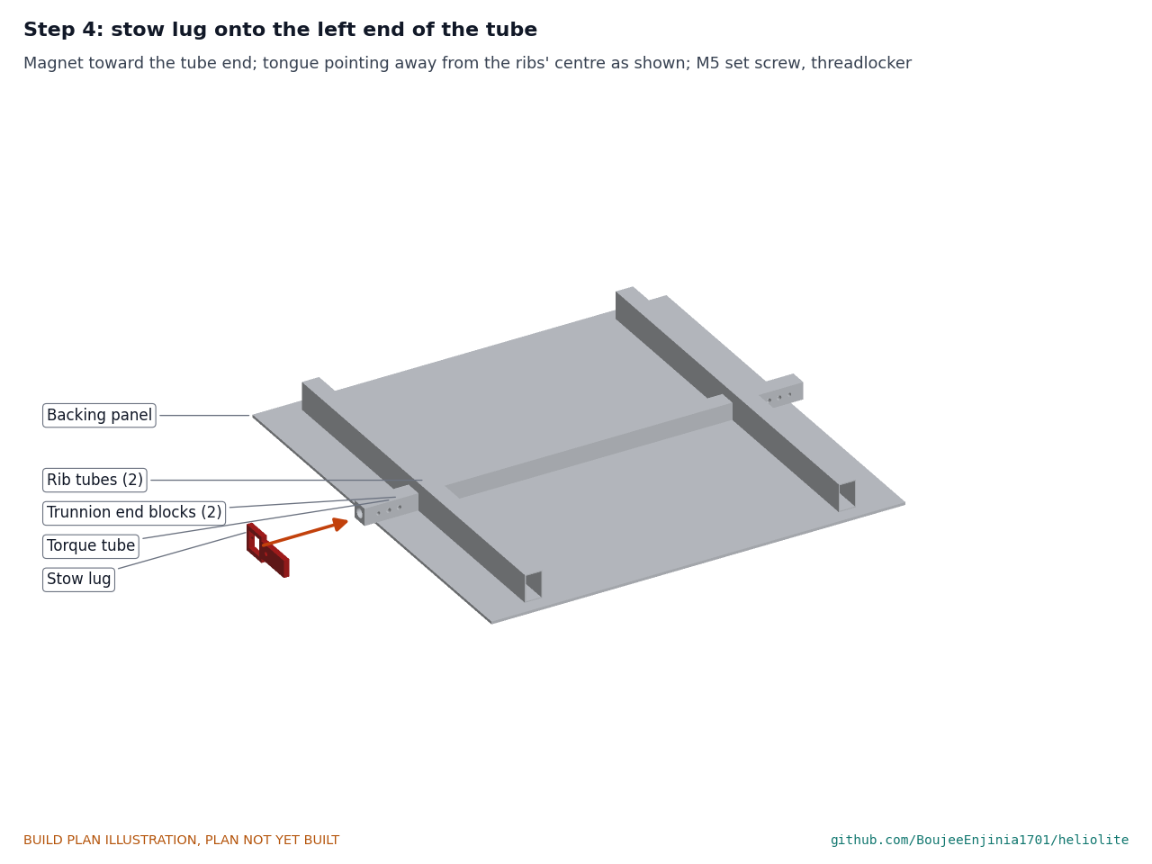
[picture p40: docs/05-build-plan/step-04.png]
Step 4


Slide the lug on, magnet toward the end, mid-plane 11 from the end. M5 set screw into the dimple with medium threadlocker.

### Step 5: bond the glass, then fit the edge channel

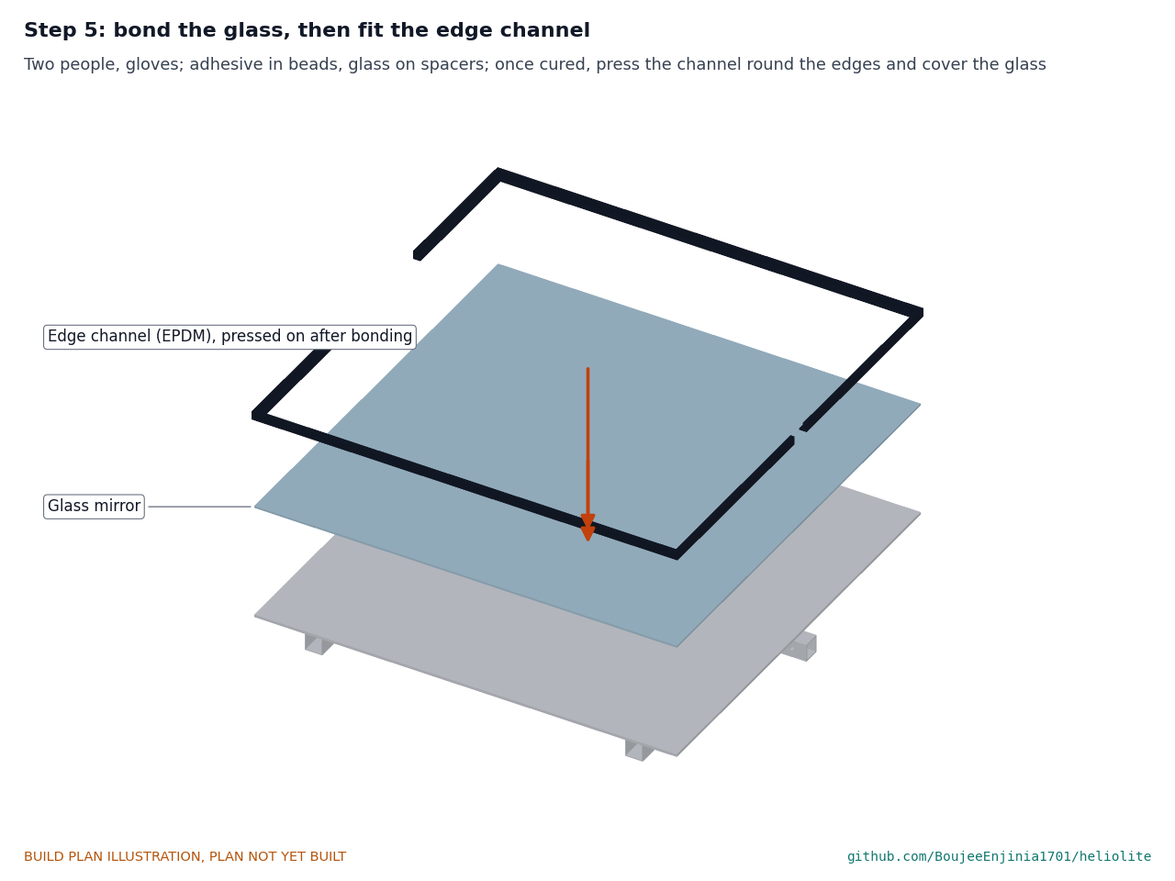
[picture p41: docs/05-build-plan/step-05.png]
Step 5


Turn the assembly face up on the padded bench. Two people, gloves and eye protection. Mirror adhesive in vertical beads on the panel, glass lowered onto spacers at the edges so it lies flat, not bowed. Once cured, press the black edge channel on round all four edges, lips over the glass front and the panel back, starting at a corner. Cut it back where the torque tube leaves the panel: 15 each side of the tube on the right edge, and 95 each side on the left (latch) edge, so the lug and latch pass. Then tape card over the glass and leave it there until calibration. **Hold point:** check the glass is flat with a straightedge in both directions; a bowed mirror concentrates sunlight.

### Step 6: arms and gussets onto the crossbar

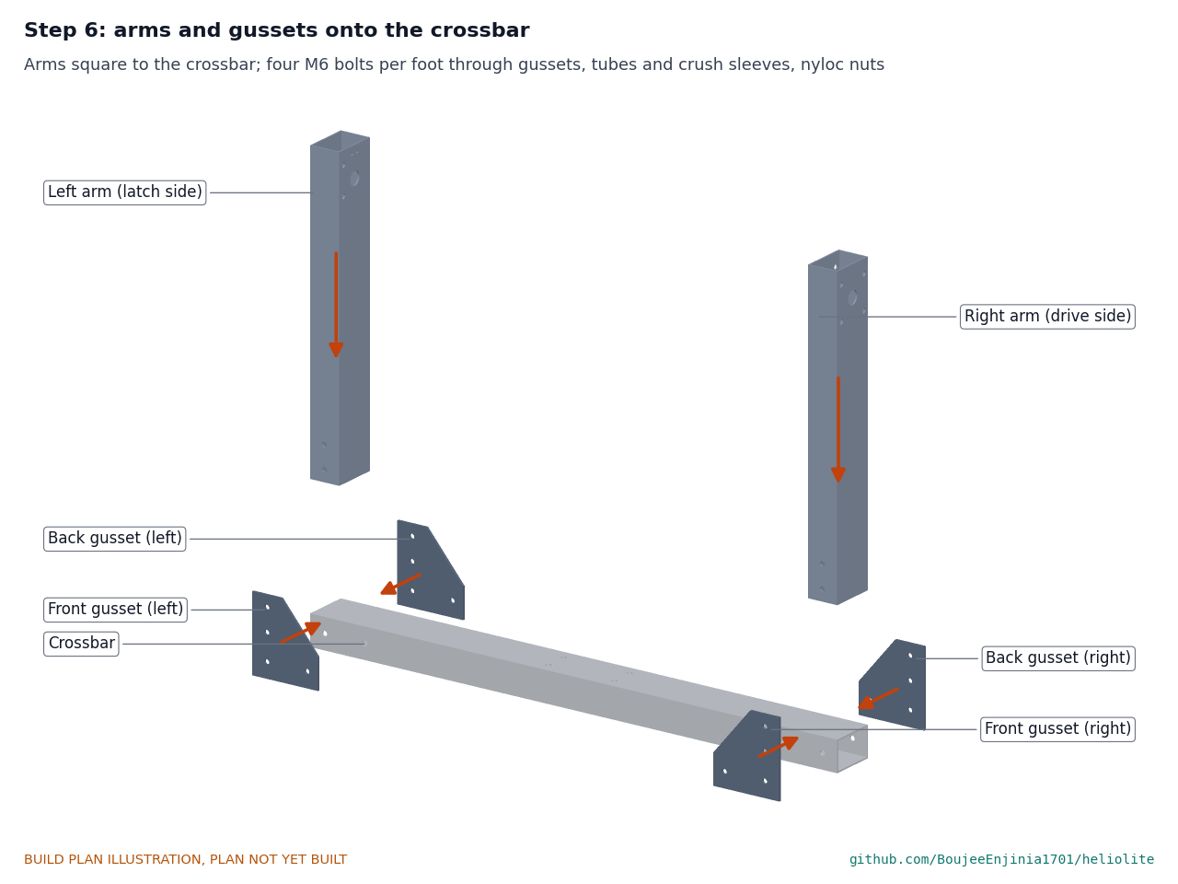
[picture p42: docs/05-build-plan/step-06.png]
Step 6


Stand each arm on a crossbar end, flush. A gusset on its front and back faces; four M6 bolts through gussets, tubes and crush sleeves, nyloc nuts. Square the arm to the crossbar before the last bolt is tight.

### Step 7: bearing plugs and bushes into the arms

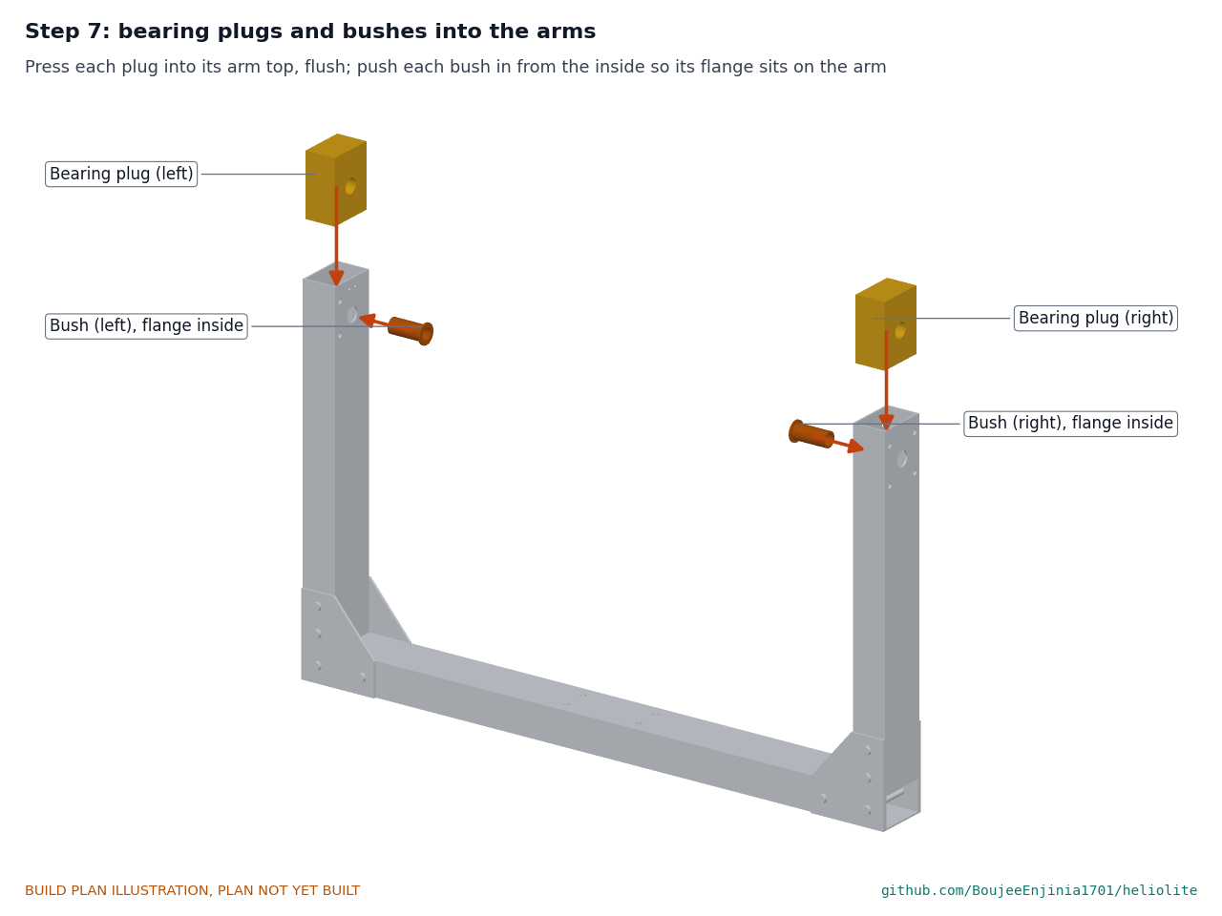
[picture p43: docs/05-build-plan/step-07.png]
Step 7


Press a plug into each arm top, flush, hole in line. Push each bush in from the inside, flange against the arm's inner side. Then drill the gearbox, latch and spring can holes through the plugs from the arms' holes.

### Step 8: latch, solenoid and Hall switch onto the left arm

Step 8

Bracket flat on the left arm's inner side at the front, two M6 countersunk screws, nyloc nuts outside. Pawl into its slot, chamfer up. Solenoid strap screwed to the outside of the leg, plunger screwed into the pawl's tail. Hall switch in the window in the arm's inner side, its back glued to the bearing plug, sensing face toward the mirror; lead taken down the back of the arm.

### Step 9: turntable disc and hub under the crossbar

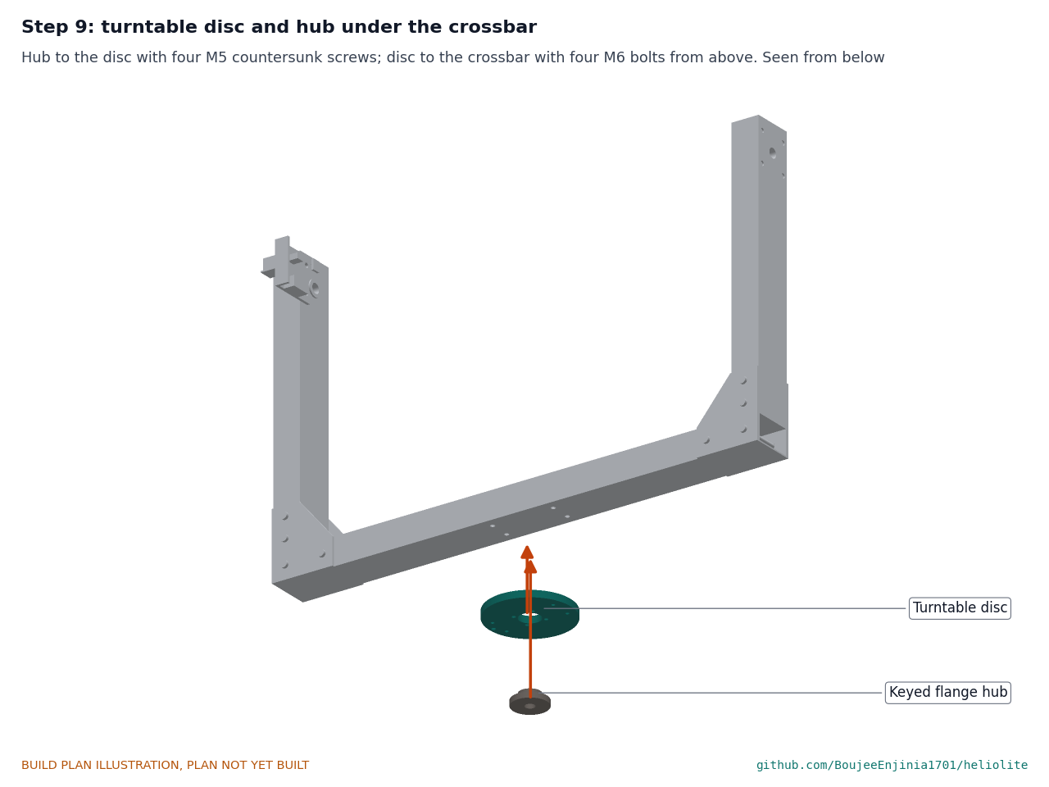
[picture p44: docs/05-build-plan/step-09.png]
Step 9


Hub to the disc's underside with four countersunk M5 screws, threadlocker. Disc to the crossbar with four M6 bolts from above, through the crush sleeves into the disc's tapped holes. The disc's magnet goes on the crossbar's centre line.

### Step 10: elevation drive onto the right arm

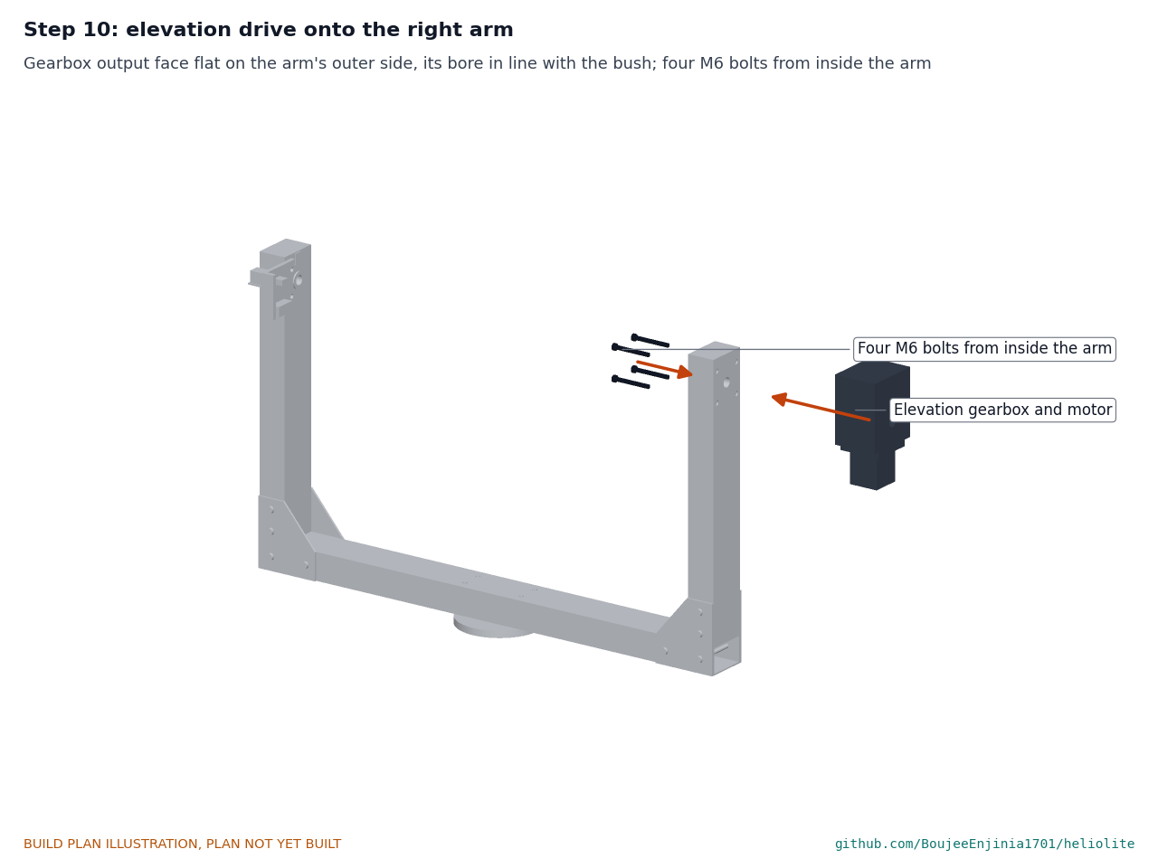
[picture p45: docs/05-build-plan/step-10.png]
Step 10


Gearbox output face flat on the right arm's outer side, its hollow bore in line with the bush; four M6 bolts from inside the arm, threadlocker. Motor and adapter plate on the gearbox's input. The yoke, its drive, latch, disc and hub now make the first lift, about 4.5 kg.

### Step 11: mast pipe into the ground anchor

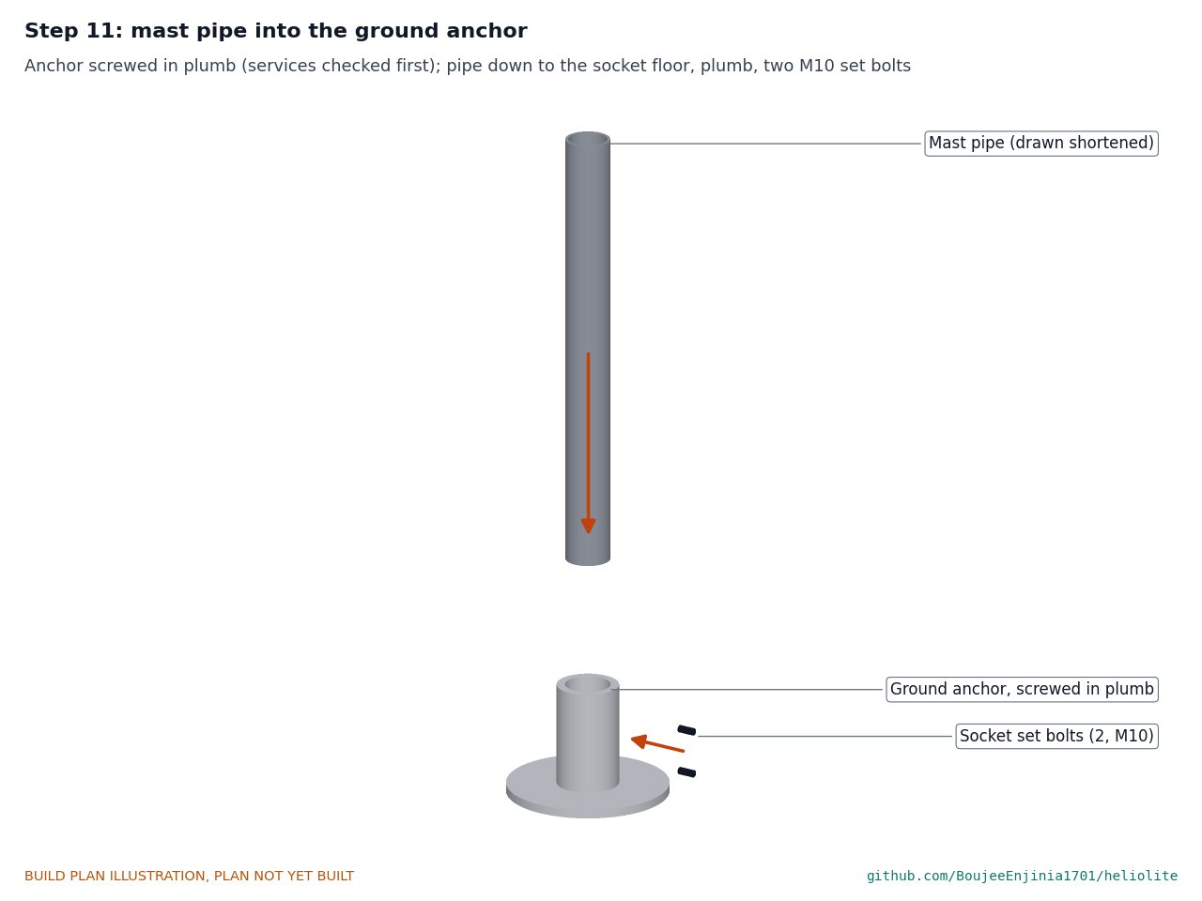
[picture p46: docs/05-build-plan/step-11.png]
Step 11


At the site, after checking for buried services, screw the anchor in plumb to the depth its maker gives. Lower the pipe into the socket to the socket's floor, plumb it with a level on two faces, and tighten the two M10 set bolts.

### Step 12: controller box and anemometer onto the mast

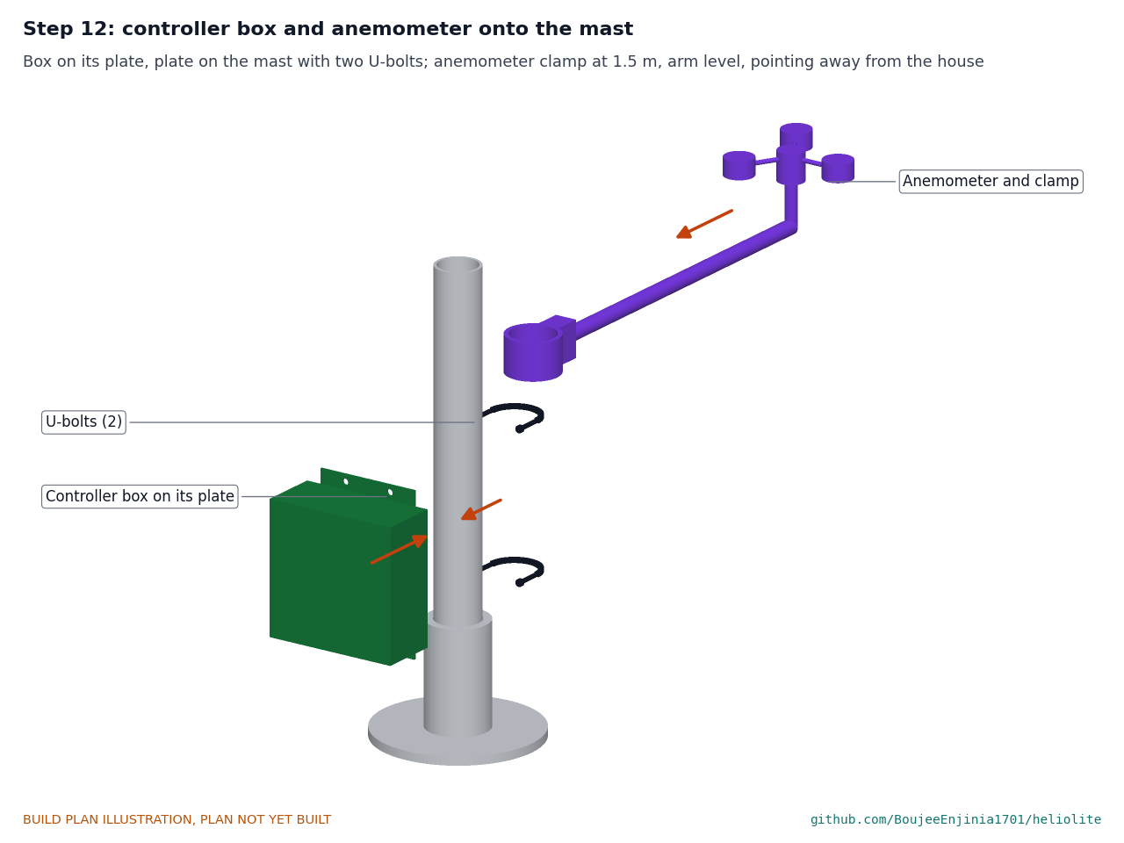
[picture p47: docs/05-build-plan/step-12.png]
Step 12


Controller box screwed to its plate; plate on the mast with two U-bolts, box base 1.1 m up, facing where you will service it. Anemometer clamp at 1.5 m, arm level, pointing away from the house.

### Step 13: floor flange onto the mast top

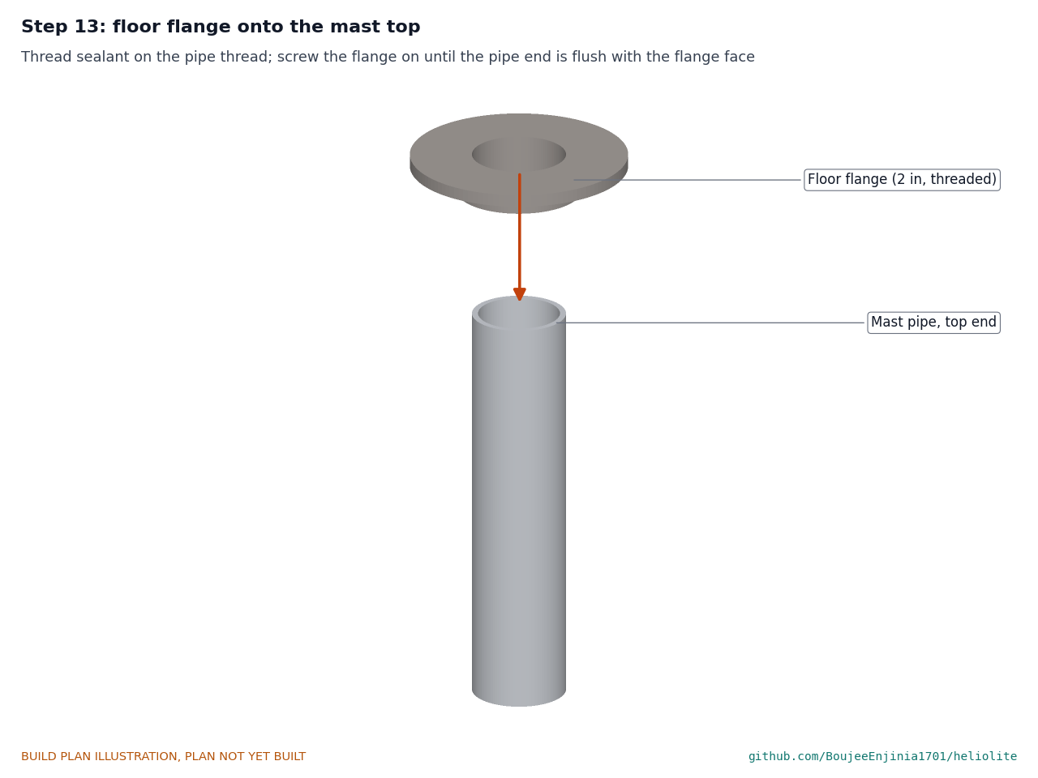
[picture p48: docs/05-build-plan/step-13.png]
Step 13


Thread sealant on the pipe thread. Screw the flange on with a pipe wrench until the pipe end is flush with the flange face.

### Step 14: cap and azimuth drive onto the floor flange

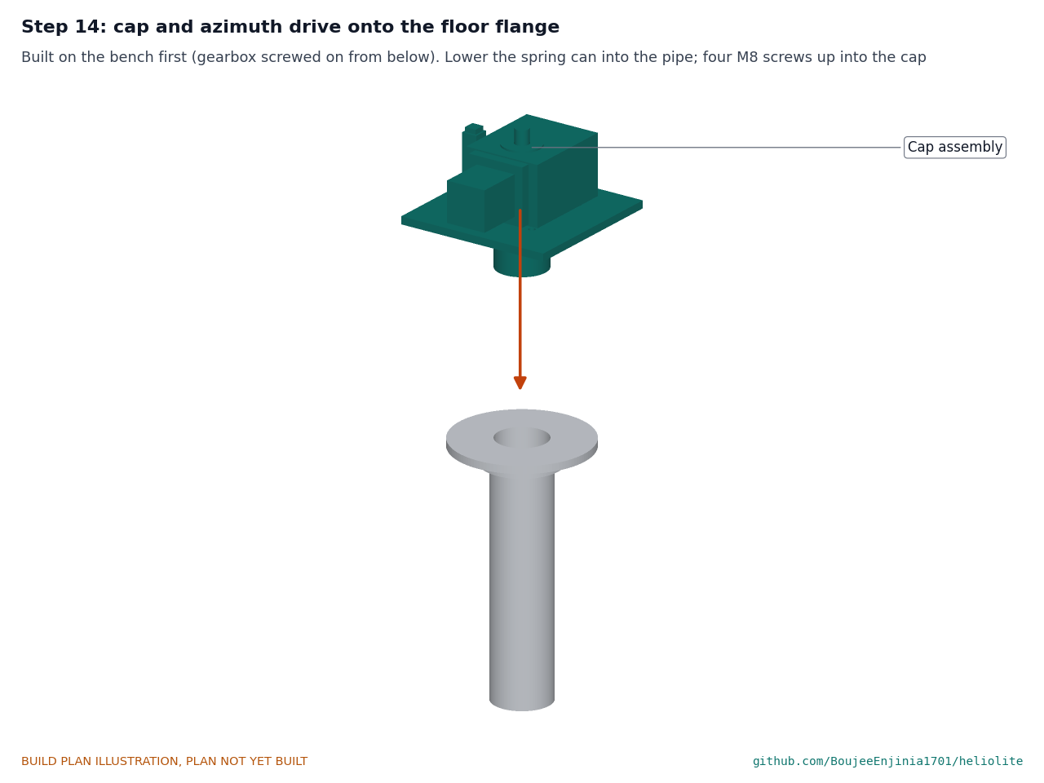
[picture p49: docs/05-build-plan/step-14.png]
Step 14


On the bench first, build the cap assembly: gearbox and motor to the cap with four countersunk M6 screws from below; shaft through the gearbox with its key; Hall post and switch on the cap; spring on the shaft's lower end in its can, wound 1 turn; thrust washer on the gearbox's top face. At the mast, lower the spring can into the pipe and seat the cap on the flange, motor away from the controller side as the picture shows. Four M8 screws up through the flange into the cap; one M5 screw through the pipe wall into the spring can.

### Step 15: first lift, the yoke and drive onto the azimuth shaft

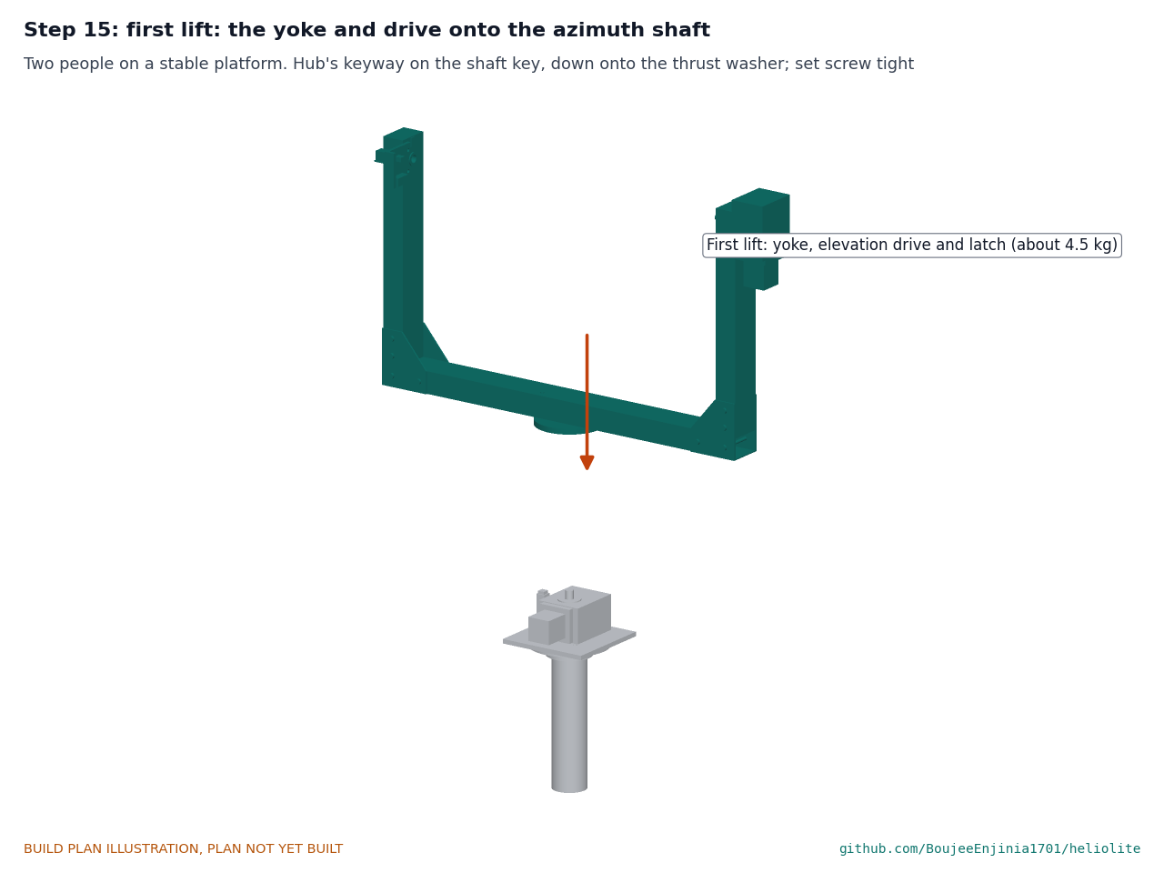
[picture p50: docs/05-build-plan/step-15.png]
Step 15


Two people, working from a stable platform with the deck about 1 m below the cap. Lift the yoke with its elevation drive, latch, disc and hub (about 4.5 kg) and lower it so the hub's keyway slides down the shaft's key until the hub sits on the thrust washer; tighten the hub's set screw on the key. Turn the yoke so the latch side faces the platform. **Hold point:** safety stop S6 in section 6.

### Step 16: second lift, lower the mirror assembly into the yoke

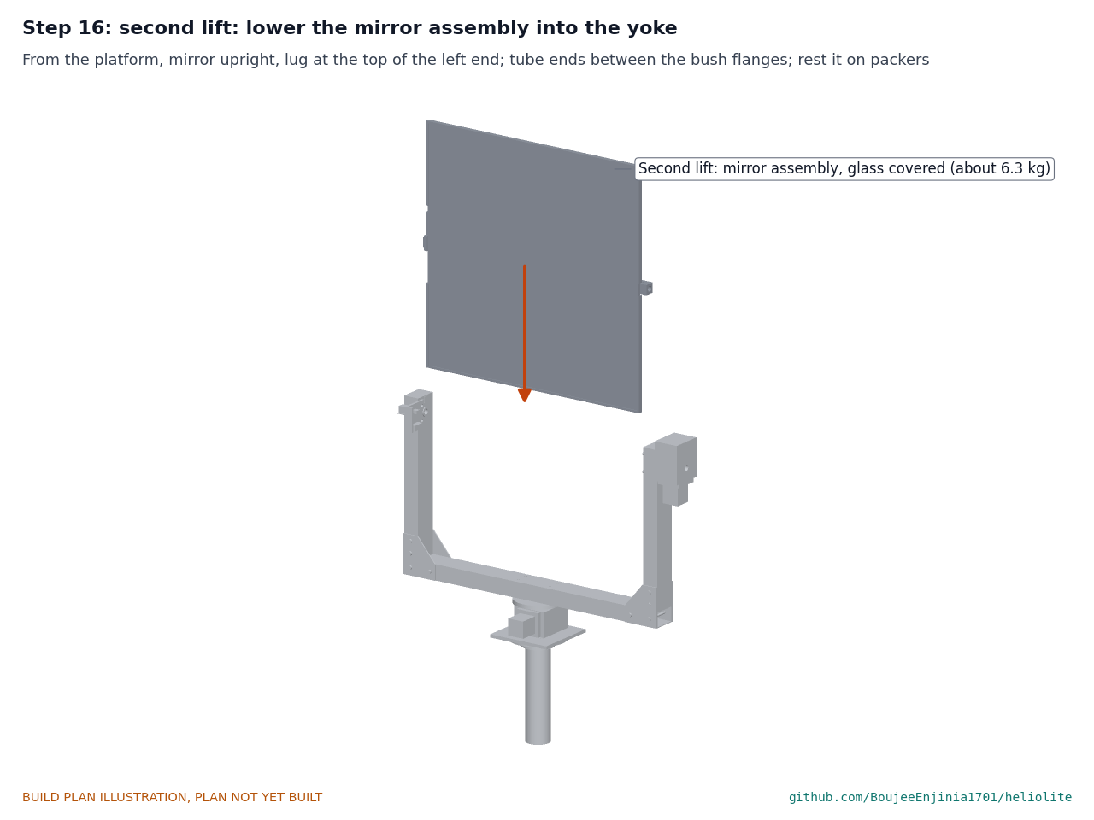
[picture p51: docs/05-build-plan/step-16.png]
Step 16


Lay two timber packers 54 tall on the crossbar, about 150 each side of the centre. Two people on the platform, gloves on, glass covered. Hold the mirror assembly (about 6.3 kg) upright, glass to the front and the lug at the top of the left end, and lower it between the arms until its bottom edge rests on the packers: the tube ends then sit between the bush flanges, in line with the bushes. The tube is 1 mm shorter than the gap between the flanges and passes the Hall switch with 1 mm to spare.

### Step 17: trunnion stubs, cross pins and spring can

Step 17

Slide the drive stub in from outside through the gearbox's bore and the right bush, key engaged, 38 into the end block; slide the slotted spring stub through the left bush 38 into its block. Drill 5 mm through tube, block and stub 20 from each tube end and drive in the roll pins. Lift the mirror off the packers and remove them. On the left, fit the spring's inner end in the stub's slot, wind the can 1 turn so the spring pulls the mirror toward stow, and screw the can to the arm with three M4 screws. Turn the mirror slowly into stow by hand until the lug pushes the pawl aside and lands on the pad. **Hold point:** the mirror turns freely by hand through its whole range with no rub at either bush, and it latches face-down; the spring now holds stored energy, so keep fingers out of the mirror, tube and yoke gaps from here on.

### Step 18: cabling and the service loop

Step 18

Run the motor leads, Hall switch leads, solenoid lead and anemometer lead to the controller box through its glands. Clip the riser to the mast with stand-off clips, step it out round the floor flange and cap, and leave a loop from beside the azimuth motor to the crossbar long enough for the yoke to turn 135 degrees each way without pulling. Tie the leads along the crossbar's top and up the back of each arm. Run the outdoor 12 V cable from the box to the house, low and clipped.

## 5. First checks

These are the checks a TRL 4 test report would record; this plan only lists them. Requirement numbers are those of HLT-REQ-001.

*Table 2. First checks.*

| Check | Requirement | How | Pass when |
| --- | --- | --- | --- |
| Mirror flat | Safety, R1 | Straightedge across the glass both ways and diagonally, before covering it | No gap over 0.5 mm |
| Elevation range | R8 | Drives off, turn the mirror by hand from face-down to face-up | No rub anywhere; the lug clears the bracket, pad and switch at every angle |
| Latch engages unpowered | R9, R10 | Turn the mirror into stow by hand | The lug pushes the pawl aside, lands on the pad and the pawl springs out over it |
| Latch holds | R9 | Push the stowed mirror's edge up by hand | The lug stays between pad and pawl |
| Latch releases | R10 | 12 V to the solenoid through its driver | The pawl pulls back fully; the mirror can leave stow |
| Azimuth range | R8 | Drives off, turn the yoke by hand 135 degrees each way | The service loop does not pull; nothing rubs |
| Homing switches | R5 | Meter on each switch output while turning each axis through home | Each switch changes state once, at home |
| Preload | R4 | Push the mirror and yoke gently against the springs | Each returns to the same side of its backlash |
| Stow on stored energy | R10 | Charge the reserve, remove the 12 V feed with the mirror at 45 degrees | The mirror reaches face-down and latches within 60 s |
| Standby power | R14 | Meter in the 12 V feed for 1 h | 3 W average or less |
| Mast plumb and tight | R13, safety | Level on two faces; set bolts and flange screws checked | Within 1 degree; nothing moves by hand |
| Mass on the mast top | R13 | Weigh the yoke with its drive and the mirror assembly before each lift | 13 kg or less together (12.99 kg estimated: 4.5 kg and 6.3 kg) |

## 6. Safety stops

Stop at each point. Carry on only when everything listed is true.

- **S1. Before handling the glass (step 5).** Two people; cut-resistant gloves and eye protection; a padded bench; the edges seamed; the backing film intact.
- **S2. Once the glass is bonded.** Card taped over the glass, and kept there through every step until calibration. An uncovered mirror can put a beam nearly as bright as the sun on a person, a road or an aircraft.
- **S3. Before the springs are wound (steps 14 and 17).** Drives disconnected; hands out of the gaps between mirror, tube and yoke (20 to 56 mm) and between the lug and the latch bracket. A wound spring turns its axis if the drive is disconnected.
- **S4. Before the stow reserve is charged.** Its output fuse fitted, its bleed resistor fitted, the box labelled. Bleed it before any work in the box.
- **S5. Before power reaches the drives.** The 12 V feed comes from the listed indoor adapter only; no mains outdoors. The mirror is latched face-down and covered; the motor leads are checked for polarity at the drivers.
- **S6. Before each lift onto the mast (steps 15 and 16).** The mast is plumb and its set bolts tight; the cap screws tight; two people working from a stable platform, never from steps or a ladder alone; the yoke and drive fitted first and the mirror assembly lowered into it; no wind above a gentle breeze; the glass covered.
- **S7. Before the mirror is uncovered (outside this plan).** The local building and planning rules are checked and a simple glare study shows the beam stays inside the property in every state; the site check of HLT-PRC-001 is done: the beam path crosses no path, road, neighbour's window or flight approach; calibration is done standing beside, never in, the beam.
- **S8. Before a storm.** Until the latch is tested at TRL 4, remove the mirror if gusts above about 29 m/s are forecast.

## 7. Tools, skills and workspace

**Tools.** Hacksaw with a 24 teeth per inch blade (or a bandsaw); bench vice with soft jaws; drill press; drills 2.5 to 16 mm; step drill to 20 mm; 14 and 18 mm hand reamers; countersink; M3, M4, M5, M6 and M8 taps and tap drills; jigsaw with a metal blade; flat and square files; deburring tool; scriber, engineer's square, steel rule and calipers; caulking gun for silicone; 3D printer with an enclosure that prints ASA, bed at least 100 x 100; pipe wrench; spirit level; torque wrench covering 5 to 25 N·m; soldering iron; ferrule crimper and wire strippers; multimeter; bench power supply (0 to 15 V, 0 to 3 A, adjustable current limit); bathroom or hanging scale to 20 kg; a stable work platform with guard rails and its deck about 1 m below the mast top; two timber packers 54 mm tall.

**Skills.** No certified trade is needed. Basic metalwork (marking out, sawing, drilling, reaming, tapping, filing), bonding with silicone, printing ASA, crimping and screw-terminal wiring, safe handling of glass and of supercapacitors. All outdoor circuits are extra-low voltage (12 V DC); the mains adapter is a listed product used indoors and no mains wiring is part of this build.

**Workspace.** A bench about 2 x 1 m with a padded top for the mirror; a metalwork corner kept apart from the electronics; a ventilated place for the printer; at the site, clear ground round the mast and a sunny day only once the mirror is uncovered.

**Personal protective equipment.** Safety glasses for cutting, drilling and soldering; cut-resistant gloves for glass and sheet; hearing protection when sawing; no gloves near a turning drill; dark glasses rated for sun viewing are not a substitute for keeping out of the beam.

## 8. Where the numbers come from

- Model and constructability checks: `cad/src/model.py` (`python cad/src/model.py --check`, 3,634 checks, including lowering the mirror assembly into the yoke at height); STEP and STL exports in `cad/step/` and `cad/stl/`.
- Pictures: `cad/src/build_plan_media.py`, using `.kit/build_views.py`; written to `docs/05-build-plan/` and `cad/drawings/HLT-DWG-101` to `HLT-DWG-115`.
- General arrangement: `cad/drawings/HLT-DWG-001.pdf`, Rev P5.
- Calculations: `docs/04-calcs/01-sizing.md` (HLT-CAL-001 v0.5) and `docs/04-calcs/sizing.py`; mass and the two lifts [H1] to [H3], balance [H4], arm stiffness [C4], pointing [D5], latch [E7] to [E9], cost [J1].
- Bill of materials: `bom/bom.csv`.
- Decisions: `docs/decisions/0003-design-for-construction.md` (HLT-DDR-003), with HLT-DDR-001 and HLT-DDR-002; open items in `docs/06-design-decisions.md` (HLT-DEC-001).
- Requirements: `docs/03-requirements.md` (HLT-REQ-001 v0.8).

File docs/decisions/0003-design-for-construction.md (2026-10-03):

---
doc_id: HLT-DDR-003
title: HelioLite design for construction
project: HelioLite
doc_type: Design decision record
version: "0.3"
status: Draft
date: '2026-10-02'
author: Amish Chadha
license: CERN-OHL-S-2.0
revisions:
- version: "0.1"
  date: '2026-10-01'
  author: Amish Chadha
  change: Changes that make the concept physically buildable, with the reason for each; made under Amish's 2026-09-30 instruction to make the design physically buildable; open for his review
- version: "0.2"
  date: '2026-10-02'
  author: Amish Chadha
  change: "Table 3 items decided by Amish on 2026-10-02: A1 aluminum latch bracket (changed), A2 two-lift head fitting from a platform (changed), A3 renders updated; Table 1 acceptance still to be put to Amish"
- version: "0.3"
  date: '2026-10-02'
  author: Amish Chadha
  change: "Table 1 changes (P1 to P14) accepted by Amish on 2026-10-02"
---

# 0003: Design for construction

- **Date:** 2026-10-01
- **Status:** accepted. Amish, 2026-10-02: "APPROVED: Design-for-construction changes in 10 repos (CityTwin, CoolShade, PalletPilot, Heliolite, PotholeLog, EarthPress, ReadyKit, CellCheck, CargoMule and ThermaCart)". This covers the whole change table, Table 1 (P1 to P14), made under Amish's 2026-09-30 instruction to make the design physically buildable, and is recorded in the design decisions register (`docs/06-design-decisions.md`, HLT-DEC-001). The items in Table 3 were decided by Amish earlier the same day ("i approve your recommendations for all 555 open decisions."), A1 and A2 on changed recommendations, and are recorded in the register too.

## Context

On 2026-09-30 Amish asked for a build plan that shows how each component is made and how it fits the next, with pictures, and wrote: "If you are realising that the design cannot be built as per concept - fix the design assumptions to match and be physically feasible as you draw the illustrations." The TRL 3 model of HLT-DDR-002 showed what HelioLite does, but it was a massing model: some parts overlapped, some floated with no fixing, one could not be made by its stated process, and the trunnion could not be fitted once the mirror was in the yoke. Checking the model with build123d (intersections, distances and an elevation sweep from stow to face-up) found the fourteen problems in Table 1.

The changes keep what HelioLite does: the same 600 x 600 mm mirror, elevation axis 2.2 m up, arm spacing and mirror clearances, the same drives, mast, anchor, controller, anemometer, preload springs and stow latch, the same face-down stow and the same pitch. Nothing here changes the safety case. Every change is in `cad/src/model.py`, which now builds each part separately and runs 1,583 constructability checks (`python cad/src/model.py --check`): parts that must touch do touch, parts that must stay apart keep their stated gap, no two parts overlap, and the mirror, tube and lug clear the yoke and latch at every elevation from -90 to +90 degrees in 15 degree steps. All pass.

## Decision

*Table 1. Changes made to the model, the BOM and the calculations.*

| # | Problem in the concept | Change made | Why this way |
| --- | --- | --- | --- |
| P1 | The two 25 x 20 mm rib tubes crossed the 25 mm torque tube in the same space: each overlapped the tube by 25 x 25 x 20 mm, so neither could be made as drawn. | Ribs are 25 x 40 x 1.5 mm aluminum tube, each with a 25.5 mm square tunnel cut at mid-length from the panel face. The torque tube slides through both tunnels and touches the panel; all three are bonded to the panel with structural silicone. | Keeps the elevation axis where the concept put it, so the mirror's balance (center of mass 12.4 mm in front of the axis, was 13.7 mm) and the preload check are unchanged in substance. A square tube in a square tunnel passes the hinge moment into the ribs by bearing, not through the silicone alone. |
| P2 | One 14 mm trunnion rod ran through the 21 mm bore of the square tube with nothing holding it, and it could not be fitted once the mirror was between the arms. | Two aluminum end blocks (21 x 21 x 60 mm, bored 14 mm) bolted into the tube ends with two M6 bolts each; two separate 14 mm keyed steel stubs (148 mm drive side, 108 mm spring side) slid in through the bushes after the mirror is in the yoke and held by a 5 mm roll pin through tube, block and stub. | The mirror can be lowered into the yoke first and the stubs fitted from outside. The pin and the square block carry the drive torque into the tube. |
| P3 | The one-piece printed ASA yoke (base plate, 720 mm crossbar and two arms about 440 mm tall) cannot be printed: the crossbar is twice the bed of common printers and the arms do not fit a 350 mm bed even diagonally. | An aluminum frame from one stock size, 60 x 40 x 2 mm rectangular tube: a 720 mm crossbar and two 397 mm arms standing on its ends, each foot clamped by two 3 mm aluminum gusset plates and four M6 bolts with crush sleeves. A printed ASA bearing plug fills the top 75 mm of each arm. The printed base plate is gone; the crossbar bolts straight to the turntable. | Buildable from stock with a saw and drill. Arm positions, the 20 mm arm gap and the mirror sweep are unchanged; the crossbar gap grows from 46 to 56 mm. The aluminum arms are stiffer (arm flex 0.006 degrees at 8 m/s, was 0.040) and the yoke is lighter (2.27 kg, was 2.72 kg). Printed parts stay where printing suits them: the plugs, spring cans and Hall post. |
| P4 | The two 14 mm bearings had no housing; the trunnion passed through a solid arm. | A flanged bronze bush 14 x 18 x 40 mm through each arm and its plug, flange on the inside. The torque tube ends rest against the flanges, which locate the mirror sideways. | A bush suits a slow, oscillating axis and fits a reamed 18 mm hole; the flange gives end float control for free. |
| P5 | The elevation gearbox hung beside the +X arm with no fixing. | Its output face bolts flat to the arm's outer side with four M6 bolts through the arm and plug into the gearbox's tapped holes; the keyed drive stub runs through its hollow bore. | The gearbox body is held against its own reaction torque, and the plug stops the bolts crushing the tube. |
| P6 | The elevation spring can stood 5 mm off the -X arm and the trunnion stopped short of it. | The printed can screws to the arm's outer side with three M4 screws; the spring stub reaches into it, and the spiral spring's inner end sits in a slot across the stub's end. | The spring now acts between the arm and the mirror, as the preload decision (HLT-DDR-002 N2) needs. |
| P7 | The turntable sat directly on the azimuth gearbox with no shaft, no bearing and no fixing; the azimuth spring can inside the mast had nothing to turn it. | A bought double output shaft (14 mm, keyed) passes through the gearbox and the cap plate into the spring can in the pipe. On top: a bronze thrust washer, a keyed aluminum flange hub and a 120 x 10 mm aluminum disc (was a 150 x 20 mm disc), held by four countersunk M5 screws. The crossbar bolts to the disc with four M6 bolts. | Every part in the stack is now fixed and the stack height is unchanged (20 mm), so the elevation axis stays at 2.2 m. The smaller disc saves mass for P1 to P9. |
| P8 | The cap plate was "welded or bolted to a pipe socket", with neither shown. | A bought 2 in threaded floor flange screws onto the threaded pipe top; four M8 screws go up through the flange into tapped holes in the 8 mm cap. The gearbox is held by four countersunk M6 screws from under the cap, fitted before the cap goes on the flange. | No welding. The cap's top stays flat under the gearbox, so no screw head clashes with it. |
| P9 | The stow latch could not work as drawn: the lug floated 2.5 mm off the tube with no fixing; the pawl lifted upward but sat inside the lug's swing, so lifting it could never let the lug out; the bracket reached 55 mm past the arm's front face with 10 mm on the arm and nothing under the stop pad; its back wall stood inside the swing of the lug's corners (76 mm radius); the solenoid floated 2 mm from it. | Lug: an 8 mm steel collar that slides on the tube's left end with an M5 set screw, and its tongue. Bracket: 4 mm steel bent into a leg and a flange, clear of the turning tube end by a 21 mm radius bite and of the lug's corners (flange 79 mm from the axis), held to the arm and plug by two M6 countersunk screws; a steel stop block screwed under the pad. Pawl: a 12 x 8 mm steel bar that slides sideways 12 mm in a slot in the leg, pushed out by the solenoid's return spring and pulled back by the coil; its chamfered tip lets the lug push it aside on the way into stow. Solenoid: on a strap screwed to the leg's outer face, beside the arm. | Keeps the decided function (HLT-DDR-002 N1): the lug is trapped between the pad and the pawl in both directions, the latch engages with no power and the solenoid releases it. A sideways pawl can leave the lug's swing; a lifting one cannot. Pawl bending 90 MPa and bracket screw load 1.2 kN at the 48.6 N·m design moment (HLT-CAL-001 [E8]). |
| P10 | The homing switches sensed nothing: the azimuth switch sat 48 mm under the turntable, and the elevation switch sat 190 mm from the axis, where no moving part passes. | Azimuth: the switch on a printed post on the cap, 4 mm under a magnet set in the disc. Elevation: the switch on the left arm's inner side, 6 mm from a magnet set in the lug's tongue. Home is azimuth zero and elevation zero (mirror upright). | Each switch now sees a magnet once per turn of its axis. |
| P11 | The controller box floated 5 mm off the mast with no fixing. | A 3 mm aluminum plate on the box's back and two 2 in U-bolts round the mast; the box stands 3 mm off the pipe. | Standard pole mounting; no holes in the mast. |
| P12 | The anemometer arm touched the mast at a single point. | A bought right-angle pipe clamp (60.3 mm to 20 mm) holds the 20 mm arm to the mast. | Standard part; the height and reach stay at 1.5 m and 550 mm. |
| P13 | The cable ran through the anchor flange and, after P8, through the floor flange; no cable reached the turning yoke, which carries the elevation motor, Hall switch and solenoid. | The feed leaves the mast 30 mm above the anchor flange; the riser steps out round the floor flange and cap; a service loop runs from beside the azimuth motor to the crossbar and along its top. | The loop takes the decided azimuth travel of plus or minus 135 degrees without a slip ring. |
| P14 | The mast pipe sat loose in the anchor socket. | Two M10 set bolts through the socket wall. | Usual practice with ground screw sockets; makes the mast plumb and stops it turning. |

*Table 2. Knock-on changes.*

| Item | Change | Reason |
| --- | --- | --- |
| Mass | 12.94 kg on the mast top against the 13 kg limit of R13 (0.06 kg margin, was 0.05 kg) [H3]. Mirror assembly 6.18 kg, yoke 2.27 kg, turntable stack 0.51 kg, latch 0.43 kg. | P1 to P14 add ribs, end blocks, bushes, bolts, a shaft and a hub; the aluminum yoke, the smaller disc, an aluminum hub and compact gussets take it back. |
| Pointing | Arm flex 0.006 degrees (was 0.040); root sum square 0.148 degrees on the normal and 0.30 degrees on the beam (was 0.153 and 0.31); 0.50 degrees at the 95th percentile of calibration, unchanged [C4, D5]. R4 stays at risk. | P3. |
| Wind and latch | Unchanged loads; the pawl and bracket screws checked at the 48.6 N·m design moment [E8]. | P9. |
| Cost | BOM lines 2, 3, 5, 6, 9, 13, 14 and 17 repriced. Value-engineering target: USD 455. Estimated cost of the constructable design: USD 492 (USD 37 over the target) [J1]. | Parts added for construction. `budget_usd` is a hypothetical control target and is unchanged; the design decisions register lists the cost drivers and savings worth trying. |
| Drawing | HLT-DWG-001 Rev P4; making sketches HLT-DWG-101 to 115 added. | Follows the model. |
| Documents | HLT-CAL-001 v0.4, HLT-PRC-001 v0.6, HLT-REQ-001 v0.6. R13 stays met (0.06 kg margin); R15 is reported against the value-engineering target, USD 37 over it. | Follows the model. |

*Table 3. Proposed, then decided by Amish on 2026-10-02.*

| # | Question | Options | Recommendation |
| --- | --- | --- | --- |
| A1 | The R13 mass margin is now 0.06 kg, on an assumed gearbox mass of 1.2 kg each. | (a) accept and weigh the parts at TRL 4; (b) look for more mass now (for example an aluminum latch bracket, about 0.1 kg). | (a). Decided 2026-10-02 on a changed recommendation: (b), the aluminum latch bracket now (about 0.1 kg), with the parts weighed at TRL 4; the EPDM edge guard decided the same day uses up most of the saving. |
| A2 | How the head goes on the mast. The plan builds the head (yoke, mirror, drive and latch, about 11 kg with the turntable disc) on the bench and lifts it onto the azimuth shaft at 1.8 m. | (a) two people on stable steps lift the head on, glass covered; (b) fit the yoke at height and lower the mirror assembly into it there; (c) a hinged mast base so the head is fitted at waist height. | (a) for the prototype, with the mirror covered; (c) is worth a look before any second build. Decided 2026-10-02 on a changed recommendation: (b) for the prototype, the yoke and drive fitted at height first and the mirror assembly (about 6.2 kg) lowered into it, glass covered, from a stable platform rather than steps; (c) looked at before any second build. |
| A3 | The appearance model (`cad/src/product_model.py`) and the photoreal renders still show the printed yoke, the concept latch and two bolted torque tube saddles (render item 4 of 2026-09-26), which P1 replaces. | (a) update the appearance model to the constructable design on Amish's Mac; (b) keep the concept renders as they are. | (a), and drop the saddles. Decided 2026-10-02. |

## Consequences

- `design_state: constructable` in `project.yaml`. The build plan HLT-BLD-001 shows every component and step in pictures generated from the model (`cad/src/build_plan_media.py`).
- Requirement status: none not met, R15 over the value-engineering target by USD 37, 2 at risk (R3, R4), 11 met on paper, 1 not verifiable at TRL 3 (HLT-CAL-001 v0.4).
- The photoreal renders (`media/render-*.png`), `media/card.png` and `media/social-preview.png` still show the concept yoke and latch; they are stale until regenerated on Amish's Mac, where Blender is.
- The gearbox bolt pattern, the double output shaft, the floor flange holes, the solenoid stroke and the spring torque are chosen when parts are bought (TRL 4); the design decisions register lists what to confirm then.
- With A1 and A2 decided, the latch bracket becomes aluminum and the head goes on the mast in two lifts from a stable platform; the model, the latch making sketch, the build plan steps 10 to 17 and their pictures, the BOM and the mass estimate are still to be changed to match (follow-up actions in `docs/REVIEW.md`, 2026-10-02).
- TRL 4 work (building and testing) stays on hold by Amish's instruction.

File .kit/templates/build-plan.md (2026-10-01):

---
doc_id: PRJ-BLD-001
title: Project prototype build plan
project: Project name
doc_type: Build plan
version: "0.1"
status: Draft
date: YYYY-MM-DD
author: Amish Chadha
license: CERN-OHL-S-2.0
revisions:
  - version: "0.1"
    date: YYYY-MM-DD
    author: Amish Chadha
    change: First build plan; design made constructable
---

# Project prototype build plan

**Plan, not yet built.** How to build the first proof-of-concept prototype, component by component. Building and testing to it is TRL 4 work. Decisions still to be made are kept in the design decisions register (`docs/06-design-decisions.md`), not here.

## 1. What you are building

Every component, pulled apart and numbered in build order

One short paragraph: what the prototype is, how many components, which are made and which are bought, and the main ways they are made.

## 2. What changed to make it buildable

| Component | The concept had | The buildable design has | Why |
| --- | --- | --- | --- |

## 3. Making the components

### 3.1 Component name

Making sketch

**What it is and what it is made from.**

**How to make it.**

1. Mark out ...
2. Cut ...

**How it fits the parts next to it.**

Close-up of the joint

**Check before moving on.**

## 4. Putting it together

### Step 1: ...

Step 1

## 5. First checks

| Check | Requirement | How | Pass when |
| --- | --- | --- | --- |

## 6. Safety stops

## 7. Tools, skills and workspace

## 8. Where the numbers come from

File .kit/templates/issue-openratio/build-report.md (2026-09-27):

---
name: Build report
about: Tell us what happened when you built, printed or tested part of this design
title: "Build report: "
labels: build-report
---

This is a research and educational prototype, not a medical device. It is a TRL 3 concept and is not released for fabrication. If you build any part of it, you do so at your own risk. Reports help everyone.

**What you built** (part, sub-assembly or test)

**Materials, tools and settings**

**What worked**

**What did not work, with photos or measurements if you have them**

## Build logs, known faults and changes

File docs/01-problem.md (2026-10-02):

---
doc_id: HLT-PRB-001
title: HelioLite problem statement
project: HelioLite
doc_type: Problem statement
version: "0.5"
status: Draft
date: '2026-10-02'
author: Amish Chadha
license: CERN-OHL-S-2.0
revisions:
- version: "0.1"
  date: '2026-09-24'
  author: Amish Chadha
  change: Initial scaffold
- version: "0.2"
  date: '2026-09-25'
  author: Amish Chadha
  change: Populate to TRL 2 (users, context, siting, constraints, out of scope, cited prior work)
- version: "0.3"
  date: '2026-09-25'
  author: Amish Chadha
  change: TRL 3 update; budget $430 and no-sun-sensor constraint as decided by Amish (HLT-DDR-001); siting findings from HLT-CAL-001; open items listed; EN 17037 sunlight citation corrected
- version: "0.4"
  date: '2026-09-26'
  author: Amish Chadha
  change: Stronger sources
- version: "0.5"
  date: '2026-10-02'
  author: Amish Chadha
  change: "First site, glare check and daylight-first wording recorded from the decisions of 2026-10-02"
---

# HelioLite problem statement

Rooms that face away from the equator (north-facing in the Northern Hemisphere) and the shaded back of many greenhouses never receive direct sun in winter, so they stay dim and cold while sunlight falls a few meters away. A small two-axis mirror that follows the sun can send that sunlight through a chosen window all day, but the heliostats on the market are either large power-plant or civic installations or discontinued consumer products. HelioLite aims to be a garage-buildable, open design at about $455 in parts.

## The problem

In the Northern Hemisphere a north-facing window sees only diffuse skylight. At 45° N the noon sun stands only about 21.6° above the horizon at the winter solstice (90° minus latitude minus 23.44°), so neighboring buildings, trees and the house itself also shade many south, east and west openings for much of the winter. The result is:

1. **Too little daylight.** People in the United States spend, on average, about 90 % of their time indoors ([US EPA](https://www.epa.gov/report-environment/indoor-air-quality)), so a room without winter sun leaves its occupants with little daylight for much of the season.
2. **No passive solar gain.** Those rooms get no free winter heat, and greenhouse beds on the north side grow slowly.
3. **Electric light as the fallback.** Occupants turn on lamps during the day.

A heliostat is a mirror turned by two motors so that the reflection of the sun stays on a fixed target as the sun moves. The physics is well proven. What is missing is a small, low-cost, repairable unit that a homeowner, school or community garden can build, site and calibrate without special tools, and that is safe to run next to people.

## Users and context

| User | Need | Context |
| --- | --- | --- |
| Homeowner or tenant with a dark north room | Sunlight in a living room, kitchen or home office on clear winter days | Suburban yard or courtyard, target window 3 to 20 m away |
| Small greenhouse or community garden | Light and some heat on shaded beds in winter and spring | Hoop house or lean-to, target is a glazed end wall |
| School or makerspace | A teaching project in astronomy, optics and control that does real work | Rooftop or yard, supervised use |
| Maker who builds and maintains it | Buy common parts, print the gimbal, flash firmware, calibrate from a phone | Home workshop, hand tools, a 3D printer |

### Operating environment

- **Latitude:** 30° to 55° N (and the mirror image in the Southern Hemisphere). Winter sun elevations at noon from about 12° to 37°.
- **Sun:** direct normal irradiance (DNI) of about 700 to 900 W/m² on clear winter days; nothing useful on overcast days.
- **Weather:** outdoor all year, -20 to +45 °C ambient, rain, snow, hail, UV and wind gusts that can exceed 30 m/s (108 km/h) in storms.
- **Siting:** the mirror must see the sun during the useful hours and see the target. A unit placed directly north of a house must stand outside the house's winter shadow (about 15 m for 6 m eaves at 45° N), so many sites will use a side yard, a roof or a garage.
- **Power:** a 12 V supply fed from an indoor outlet; Wi-Fi often available but not guaranteed.
- **People:** the beam crosses gardens, paths and windows where people, pets, drivers and neighbors may look into it.

## Constraints

- Garage-buildable prototype, about $455 USD in parts (`project.yaml` budget, raised from $400 to $430 by Amish on 2026-09-25, HLT-DDR-001 D4, then to $455 by a top-up he approved on 2026-09-26, HLT-DDR-002 P1).
- Open-loop tracking from time and location (a sun-position algorithm), with no sun sensor or camera. Homing switches for the axes and a weather anemometer for storm stow are allowed (HLT-DDR-001 D2, D5).
- Only extra-low voltage (12 V DC) outdoors; the mains adapter stays indoors.
- Parts available from general hardware, electronics and 3D-printing suppliers; one mirror cut to size by a local glazier.
- Install by two people with hand tools, without a crane or permanent roof penetration.
- Must not create a hazard to people, vehicles or aircraft from the reflected beam, including when stowed or unpowered.

## Out of scope

- Concentrating sunlight for heating water, cooking or power (a flat mirror only redirects about one sun).
- Arrays of heliostats aimed at one target.
- Light pipes, fibers or daylight-redirecting films inside the building.
- Commercial product certification.

## Prior work

- **Civic heliostats.** Since 2013, three computer-driven heliostats with 51 m² of mirror in total, about 450 m above the town of Rjukan, Norway, reflect sunlight onto an ellipse of about 600 m² in the market square during the months when the valley is in shadow ([Visit Rjukan](https://visitrjukan.com/en/p/the-giant-sun-mirrors-in-rjukan/)). The project shows the social value of redirected winter sun at a scale far above a house.
- **Home heliostats.** The Sunflower home heliostat was marketed around 2012 as a self-powered unit redirecting up to about half a square meter of sunlight, described as up to 500 W, into a home ([Inhabitat](https://inhabitat.com/easy-to-use-sunflower-heliostat-provides-up-to-500-watts-of-sun-energy-for-homes/); [Solar Power World](https://www.solarpowerworldonline.com/2012/04/home-heliostats/)). It confirms the use case; it does not appear to be widely available today, and its design is not open.
- **Open maker heliostats.** Open Arduino projects compute the sun's position from a clock and drive a mirror in altitude and azimuth, for example [jremington/Arduino_heliostat](https://github.com/jremington/Arduino_heliostat) (steppers with gear reduction, about 0.1° step resolution, and a warning that the Arduino's own crystal is not accurate enough for long unattended tracking) and the Cerebral Meltdown [Open Sun Harvesting Project](https://github.com/FrodgE/sun-harvester). The [Open Source Ecology heliostat page](https://wiki.opensourceecology.org/wiki/Heliostat) collects further examples. HelioLite builds on this approach but targets an outdoor-rated, calibrated, safe unit rather than a bench model.
- **Sun-position algorithms.** NREL's Solar Position Algorithm computes the sun's position with an uncertainty of ±0.0003° for the years -2000 to 6000 ([Reda and Andreas, NREL/TP-560-34302](https://www.nrel.gov/docs/fy08osti/34302.pdf); [NREL MIDC SPA page](https://midcdmz.nrel.gov/spa/)). Grena's five lighter algorithms, valid for 2010 to 2110, have maximum errors from 0.19° down to 0.0027° and suit small microcontrollers ([Grena 2012, Solar Energy 86](https://www.sciencedirect.com/science/article/abs/pii/S0038092X12000400)). Either is far more accurate than the mechanics of a low-cost unit.
- **Heliostat wind loads.** Wind-tunnel data and design methods for ground-mounted heliostats are given in Sandia report SAND92-7009 ([Peterka and Derickson 1992](https://www.osti.gov/biblio/7105290)) and updated by the Heliostat Consortium ([NREL 2025](https://docs.nrel.gov/docs/fy25osti/96375.pdf)). HelioLite uses these only for first-order estimates.
- **Glare and eye hazard.** Sandia's analytical method for glint and glare from solar mirrors relates retinal irradiance and subtended angle to after-image and retinal burn risk ([Ho, Ghanbari and Diver 2011](https://www.sandia.gov/app/uploads/sites/167/2025/03/Methods_Ho_2011.pdf)). It is the basis for the beam-safety requirements in HLT-REQ-001.

## Open questions

- Which first site and user (a house with a north room, a greenhouse or a school)? This sets latitude, distance to target and siting. Decided 2026-10-02 (HLT-DEC-001): a house first, owned by a contributor or someone in the team's network, chosen by the siting check below; schools only after glare safety is shown.
- How common is a site where the mirror can see the winter sun and the north window at the same time, without standing in the house's shadow? The hourly model in HLT-CAL-001 (section B) shows the answer matters more than any hardware choice: the same unit delivers 0.40 to 1.00 kWh on the solstice at three illustrative sites. A short siting survey of real yards is needed (O3).
- Is daylight or heat the main benefit users value? The calculations suggest daylight is substantial (about 500 lx) and heat is modest (about 150 W while sunny). Until co-design shows otherwise, public copy leads with daylight and treats heat as a bonus (decided 2026-10-02).
- What local rules on glare, setbacks and structures on a lot or roof apply at the first site (O2)? They are checked, with a simple glare study, before the mirror is uncovered (decided 2026-10-02).

## User research and co-design

This design is for households and growers the author does not know yet, so requirements should be checked with them.

- [ ] Identify two or three candidate sites (house, greenhouse, school) and their owners
- [ ] Record latitude, target size and distance, shading, and where people walk
- [ ] Ask users whether they want light, heat or both, and for how many hours
- [ ] Revise requirements (REQ) from findings before freezing the design

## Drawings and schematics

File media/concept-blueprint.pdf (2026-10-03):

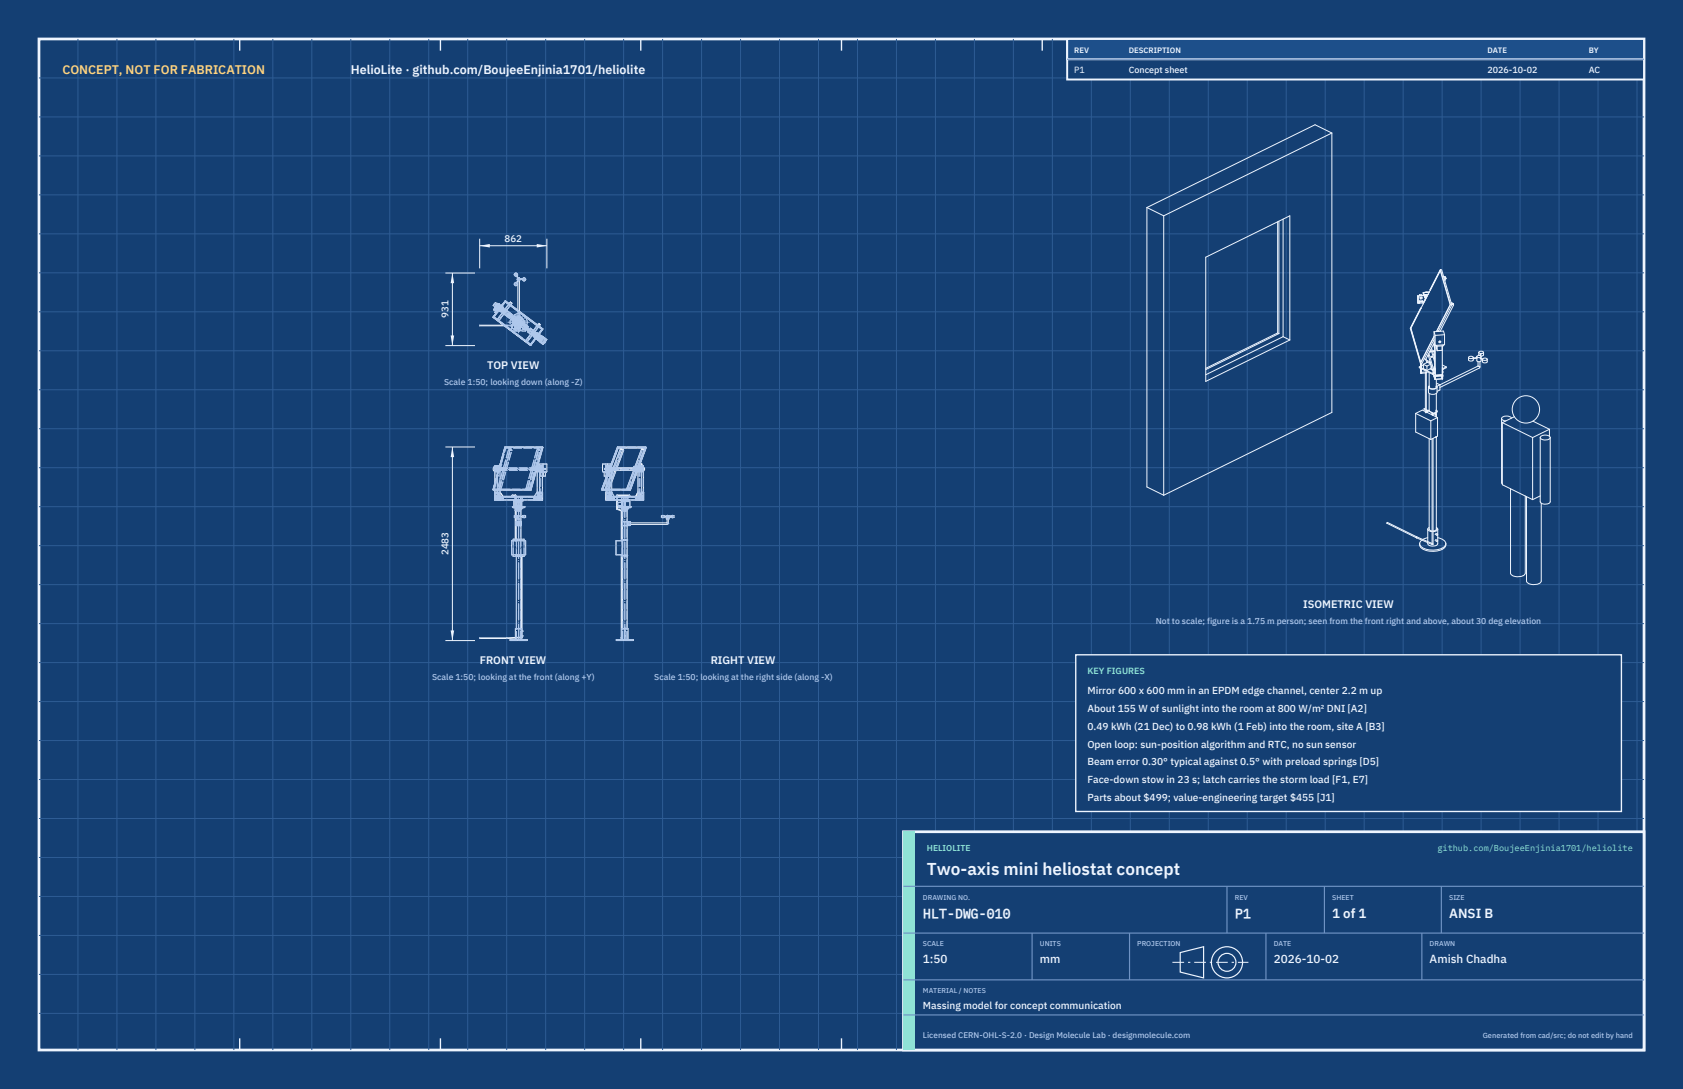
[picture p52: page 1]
CONCEPT, NOT FOR FABRICATION; HelioLite · github.com/BoujeeEnjinia1701/heliolite; FRONT VIEW; TOP VIEW; RIGHT VIEW; ISOMETRIC VIEW; REV; DESCRIPTION; DATE; Concept sheet; HELIOLITE; github.com/BoujeeEnjinia1701/heliolite; DRAWING NO. HLT-DWG-010; REV P1; SHEET 1 of 1; SIZE ANSI B; SCALE 1:50; UNITS mm; PROJECTION; DRAWN Amish Chadha; Licensed CERN-OHL-S-2.0 · Design Molecule Lab · designmolecule.com; Generated from cad/src; do not edit by hand

Scale 1:50; looking down (along -Z)

Not to scale; figure is a 1.75 m person; seen from the front right and above, about 30 deg elevation

KEY FIGURES
Mirror 600 x 600 mm in an EPDM edge channel, center 2.2 m up
About 155 W of sunlight into the room at 800 W/m² DNI [A2]
0.49 kWh (21 Dec) to 0.98 kWh (1 Feb) into the room, site A [B3]
Open loop: sun-position algorithm and RTC, no sun sensor
Beam error 0.30° typical against 0.5° with preload springs [D5]
Face-down stow in 23 s; latch carries the storm load [F1, E7]
Parts about $499; value-engineering target $455 [J1]

Scale 1:50; looking at the front (along +Y)

Scale 1:50; looking at the right side (along -X)

Two-axis mini heliostat concept

MATERIAL / NOTES
Massing model for concept communication

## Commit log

2026-09-24 Initial scaffold: standard open hardware layout, CERN-OHL-S v2 + MIT licenses
    Claude-Session: https://claude.ai/code/session_01XuhhSU4W6fYhgCfURbrkut
    [bom.csv]
2026-09-25 Adopt portfolio kit v1.3.0: session commands, scale figure, 3D viewer, flow diagrams
    Adds .claude/commands (/populate, /advance-trl3, /rein-in, /refresh-media)
    so every Claude Code session starts from the standard prompts, and extends
    concept media with a 1.75 m scale figure, an interactive glTF viewer and
    system or energy flow diagrams. TRL cap 3 unchanged.
    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
2026-09-25 Kit v1.3.1: renderer fixes from the TremorTrace pilot
    Context scale parts for small objects, cutaway exclusions, and text
    labels in flow diagrams.
    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
2026-09-25 Populate heliolite to a strong TRL 2 with concept media (overnight batches 4 and 5)
    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
    [bom.csv]
2026-09-25 Advance heliolite to TRL 3 (batch 4)
    Decisions approved by Amish 2026-09-25 recorded in DDR-001. TRL 4 is on hold.
    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
    [bom.csv, gimbal.step, gimbal.stl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]
2026-09-26 Accept all recommendations (DDR-002), switch footer to designmolecule.com, add README write-up with new inspiration point
    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
    [bom.csv, gimbal.step, gimbal.stl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]
2026-09-27 Product appearance model and photoreal renders
    Adds cad/src/product_model.py (appearance model for renders only, all main
    dimensions from model.py) and Blender renders in media/render-*.png,
    captioned with the project, repository and viewing direction. README leads
    with the product render; trl stays 3.
    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
2026-10-01 Image quality pass: legible exploded views, flow diagrams and drawing sheets
    Kit 1.6.1 image layout: the parts list sits in its own column, number bubbles sit on visible parts and never overlap, small parts get a leader, pictures are cropped to the subject, flow labels keep numbers with their units, and sheet captions and the revision table no longer overprint. Concept images, blueprint and general arrangement sheet regenerated; repo-specific labels moved clear of other text and lines.
2026-10-01 Kit 1.7.0: constructable design, illustrated build plan and design decisions register
    The design is now constructable: every part can be made and fits its neighbours, with each change recorded in a Design for construction decision record (made under Amish's 2026-09-30 instruction; ope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
    FlexHand also credits Dr. Geeti Chadha as a contribut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
    [bom.csv, gimbal.step, gimbal.stl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]
2026-10-02 Record Amish's approval of the open-decision recommendations
    Amish approved the recommendation on every open decision in the design decisions register ("i approve your recommendations for all 555 open decisions.", 2026-10-02). Each decision is moved to Decisio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
2026-10-03 Carry approved follow-ups into the design and redo photoreal renders
    Amish approved the follow-up actions from the open-decision sign-off ("APPROVED CHANGES, COMPLETE THESE", 2026-10-02), the design-for-construction change tables in ten repos, the last wave's open dec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
    [bom.csv, gimbal.step, gimbal.stl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]

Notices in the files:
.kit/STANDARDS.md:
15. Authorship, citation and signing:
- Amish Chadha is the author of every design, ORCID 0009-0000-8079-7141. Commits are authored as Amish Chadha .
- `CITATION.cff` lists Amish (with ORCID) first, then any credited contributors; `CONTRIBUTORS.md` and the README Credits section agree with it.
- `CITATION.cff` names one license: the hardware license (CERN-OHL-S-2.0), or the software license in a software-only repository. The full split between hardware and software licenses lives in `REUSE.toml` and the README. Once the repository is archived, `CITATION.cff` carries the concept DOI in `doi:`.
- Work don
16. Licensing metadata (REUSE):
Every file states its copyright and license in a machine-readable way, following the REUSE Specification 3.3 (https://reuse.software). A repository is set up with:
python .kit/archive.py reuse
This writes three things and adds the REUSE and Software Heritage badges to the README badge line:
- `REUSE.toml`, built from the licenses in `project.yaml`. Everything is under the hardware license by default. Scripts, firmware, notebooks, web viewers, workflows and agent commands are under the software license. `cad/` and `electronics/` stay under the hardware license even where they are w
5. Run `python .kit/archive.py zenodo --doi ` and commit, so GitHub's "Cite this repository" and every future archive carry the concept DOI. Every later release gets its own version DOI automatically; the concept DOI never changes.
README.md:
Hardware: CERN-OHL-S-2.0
